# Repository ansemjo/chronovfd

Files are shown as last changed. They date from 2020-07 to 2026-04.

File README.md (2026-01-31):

# chronovfd

A vacuum-flourescent display (VFD) clock project based on Soviet NOS [IVL2-7/5 / ИВЛ2-7/5](https://www.ebay.com/sch/i.html?_nkw=ivl2-7%2F5) tubes. This has been my first somewhat complex hardware project when I got into electronics design in 2020 and grew to multiple iterations over the years.

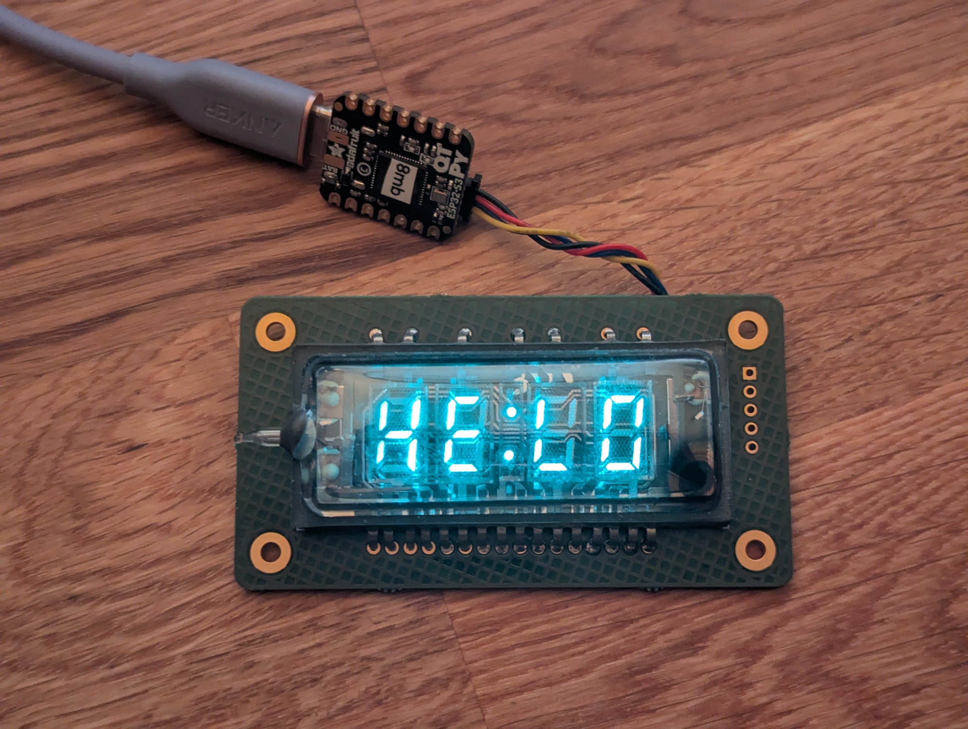
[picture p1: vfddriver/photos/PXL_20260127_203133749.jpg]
Redesigned vfddriver v2 showing blue glowing text HE:LO. The PCB has a hatched pattern on the front and gold ENIG plating.


#### quickmenu:

* [vfddriver](vfddriver/) — updated display board, which can be used over I2C
* [sandwich](sandwich/) — the original clock design with two boards
* [other](#other-directories) — links to initial research prototypes and various experiments

### vfddriver

This section describes the updated display board design, which I will be using going forward with this project. The [original design](#sandwich) of course still works but I found it needlessly complex later on due to a few choices I made.

Primarily, you needed to have a lot of IVL2-7/5 specific bits in the firmware and constantly refresh the display contents on the shift register. The mapping of display characters to segment anodes, their mapping to the correct shift-register pin, as well as the necessary anode and grid time-multiplexing all needed to be implemented on the controller board. Which meant that you really couldn't easily swap out the controller for something else. It had originally been a design goal not to require *any* separate firmware on the display board but I realized that just makes everything more complicated because you can't handle the display as an abstraction.

Instead, in this redesign I opted to include a small AVR ATtiny414 microcontroller, simplify the filament AC driver circuit with an H-bridge and implement the entire board as an I2C peripheral. **That newer design, along with firmware and documentation, can be found in [`vfddriver/`](vfddriver/).**

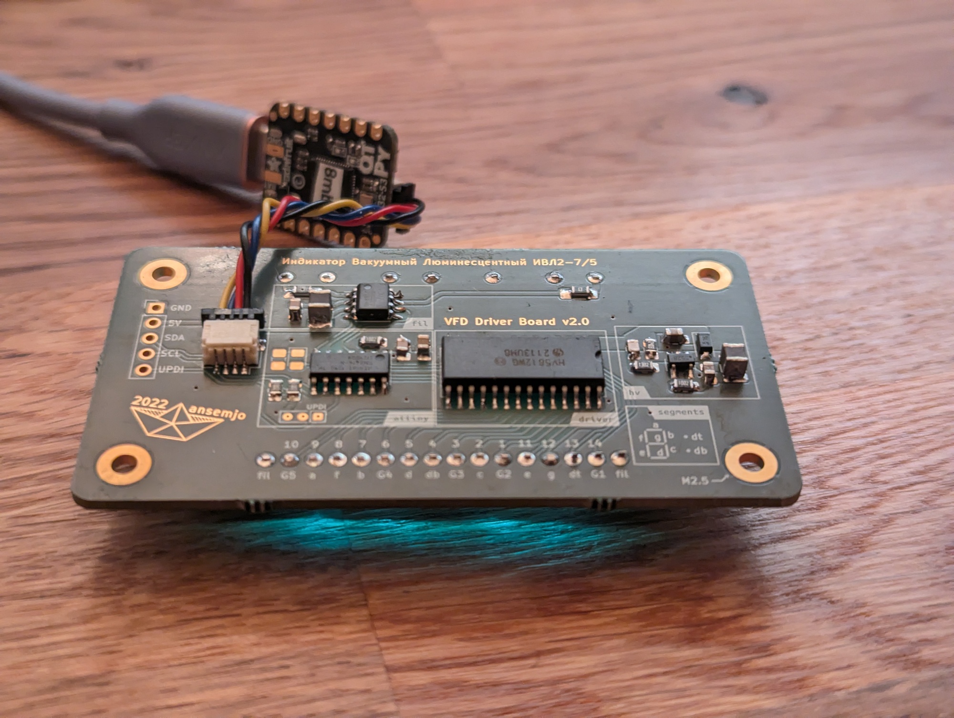
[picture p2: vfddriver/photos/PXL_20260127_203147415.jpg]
Backside of the vfddriver v2 board, with each group of chips labelled on the silkscreen.

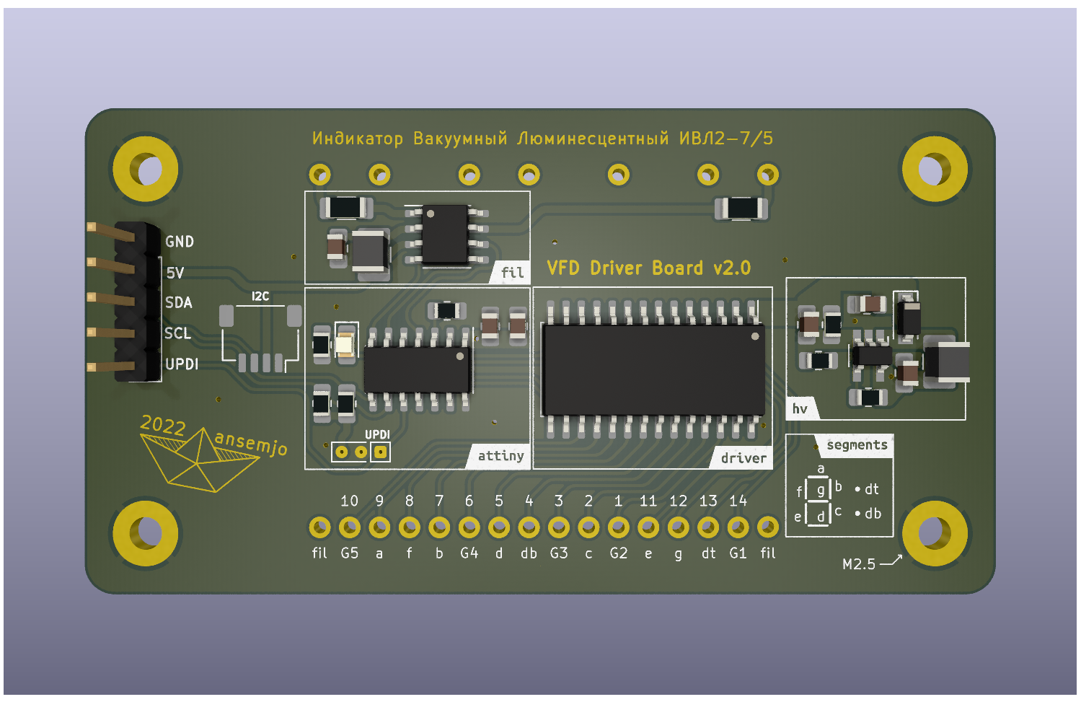
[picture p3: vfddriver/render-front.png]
PCB render of the same board.


In these images above you can also see why there is no dedicated "clockdriver v2" yet: now that the VFD is controlled over I2C, you can just use a small CircuitPython board with a Qwiic cable, like the [Adafruit QT Py ESP32-S3](https://www.adafruit.com/product/5426). :)

### sandwich

What you see in the pictures below is the original "sandwich design" with a pure-logic display driver (more or less a wrapper around the HV5812 shift-register) and an ESP32-based design with an RTC and coin-cell backup for the controller board. You can find all the KiCAD files and firmware for it in [`sandwich/`](sandwich/), together with the original README and more photos.

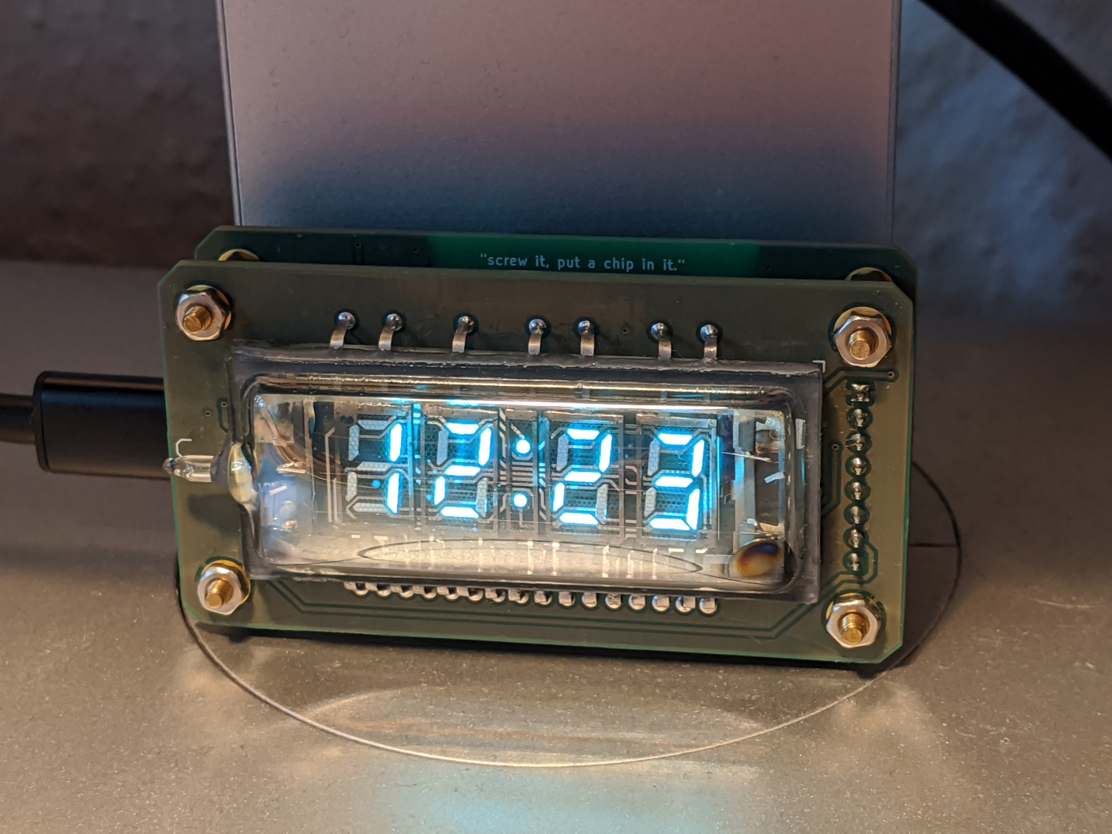
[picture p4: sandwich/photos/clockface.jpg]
finished sandwich clock, showing the time 12:23 in blue glowing digits

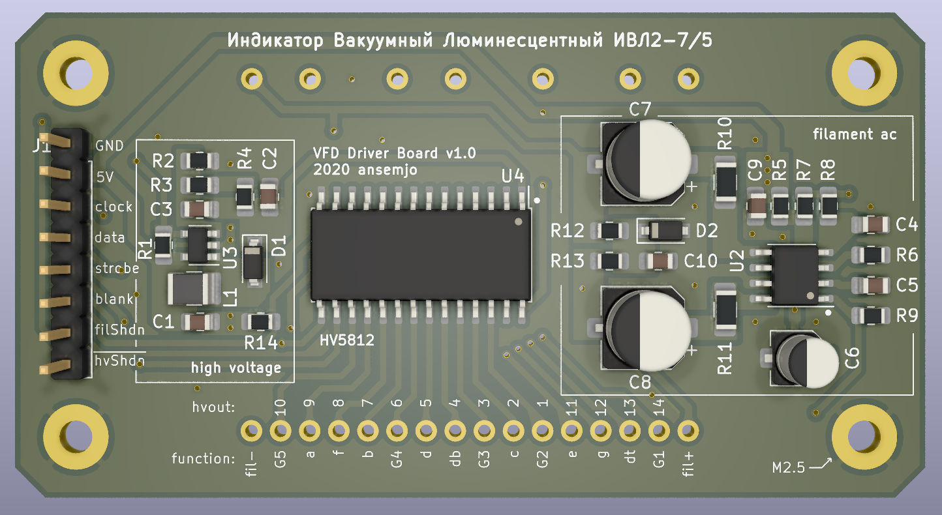
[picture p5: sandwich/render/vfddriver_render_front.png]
vfddriver PCB render, front

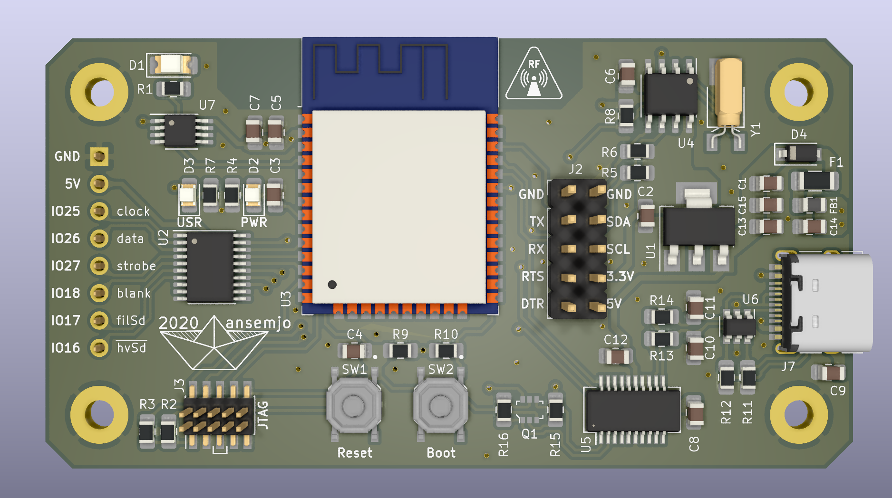
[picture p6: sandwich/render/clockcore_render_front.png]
clockcore PCB render, front


### other directories

The **[research/](research/) directory** contains a lot of initial ideas and fundamental information on VFD operation (needed voltages etc.) along with the [display datasheets](research/ivl2-7_5-datasheets).

The first **prototype clock** on perfboard can be found in [research/protoclock/](research/protoclock/).

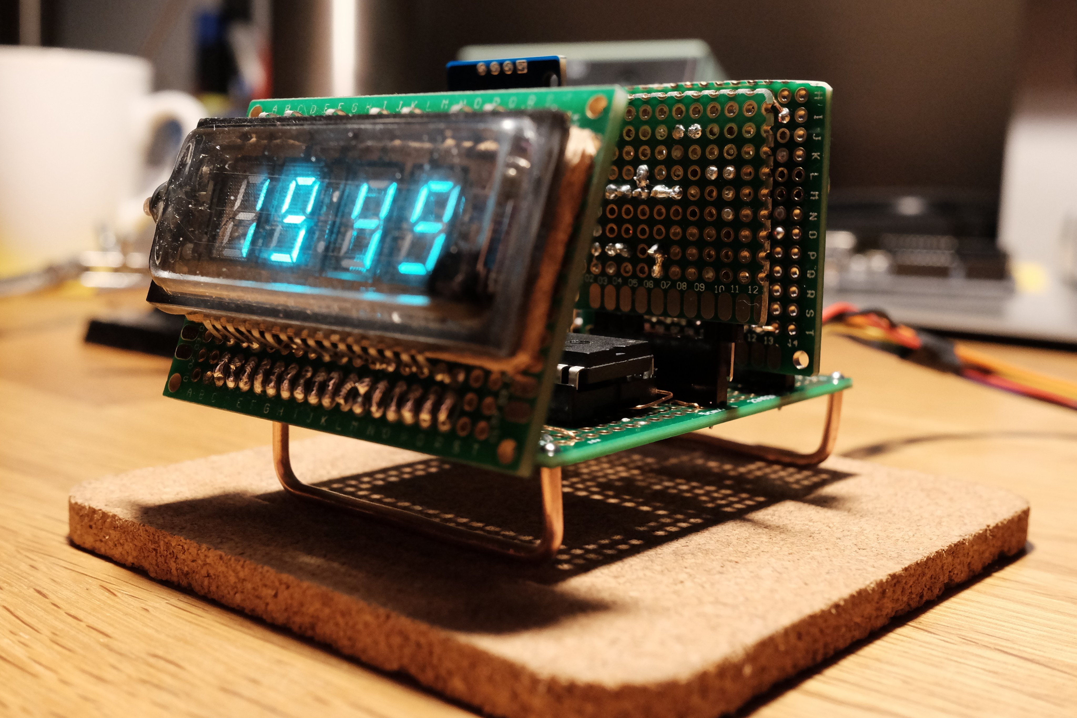
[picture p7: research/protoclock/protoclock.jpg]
Prototype clock built from multiple green perfboards.


An alternative **LCD-based front panel** with compatible dimensions, which can also be used standalone in [lcddriver](lcddriver/).

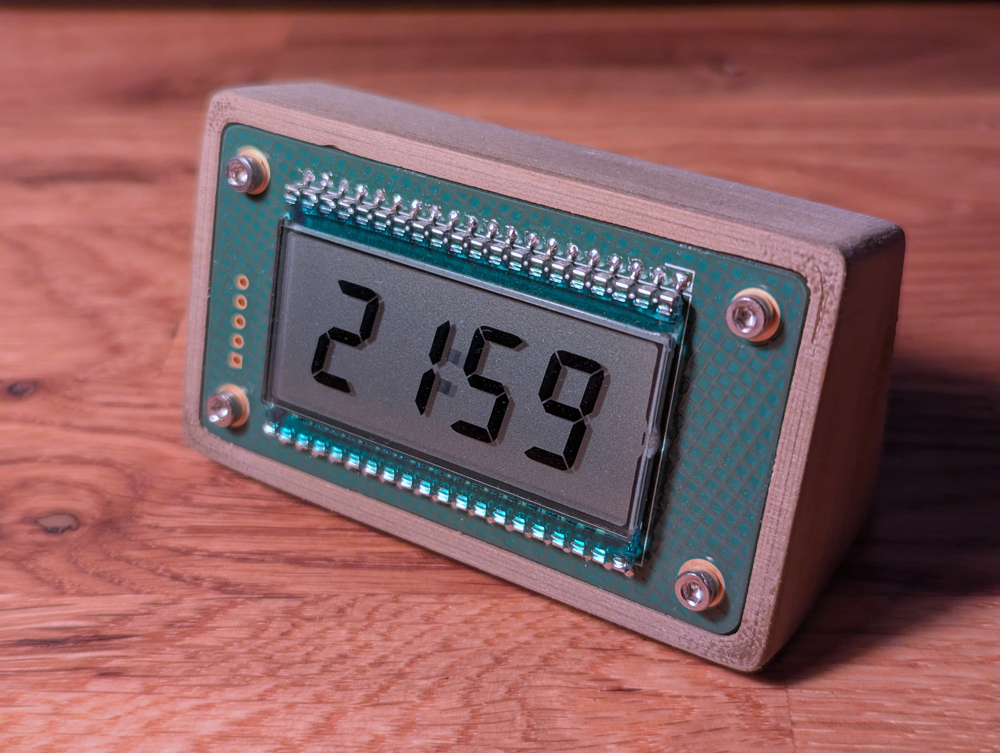
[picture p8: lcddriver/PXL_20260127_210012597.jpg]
The LCD clock panel in a small enclosure printed with brown wood-fibre filament.


In [experiments/si4706_radio_eval](experiments/si4706_radio_eval/) there is an evaluation board based on the **Skyworks Si4706 FM receiver** with RDS decoding. The idea is that you should be able to get time signal from radio stations without any need for internet synchronization.

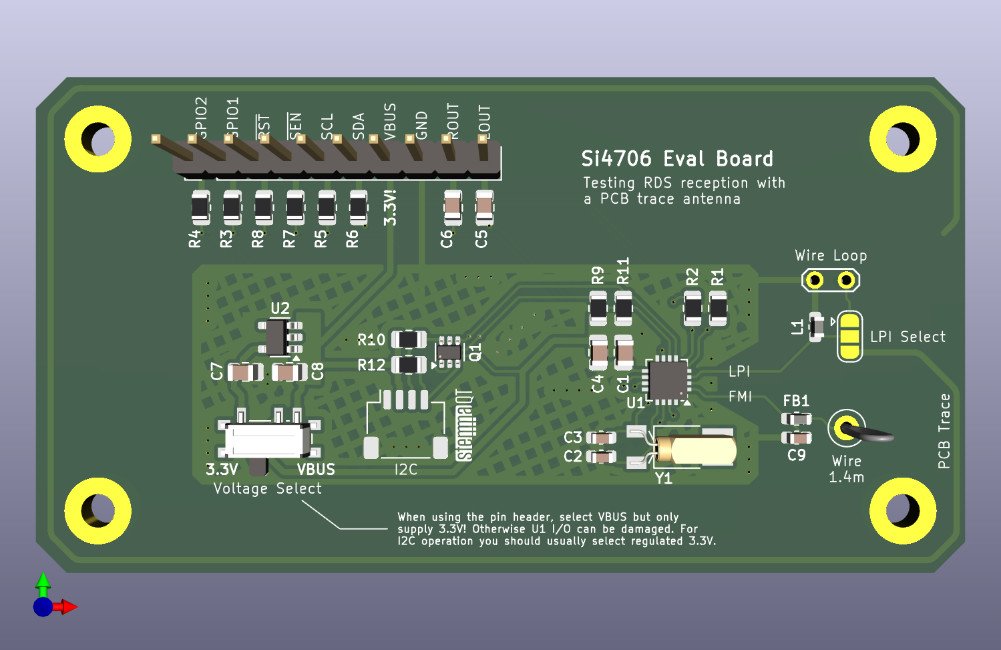
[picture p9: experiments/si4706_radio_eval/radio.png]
PCB render of the Si4706 evaluation board showing a trace around the edge, that could act as an antenna.


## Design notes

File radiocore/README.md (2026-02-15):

# radiocore
This is a redesign of the [`si4706_radio_eval`](../experiments/si4706_radio_eval/) experiment, meant to be a "clockcore v2" to control the standalone vfddriver.

Notably, it includes:

* **Skyworks Si4706** FM radio receiver with RDS decoder, to get time signal "from the air"
* **DS1338 RTC** with coin cell battery backup, to keep accurate time over long periods and without power
* **ESP32-C3** as a simple-to-program-over-USB controller chip, which conveniently *also* includes WiFi capability, if you prefer NTP over RDS
* vertical **GCT USB4145** USB-C connector, so a final assembly with two sandwiched boards will have the cable coming in from the back

_**2026-02-03:** I ordered the boards and am waiting to try if the CircuitPython firmware from the experiment will work on this chip as well. (**edit:** yes, it does!)_

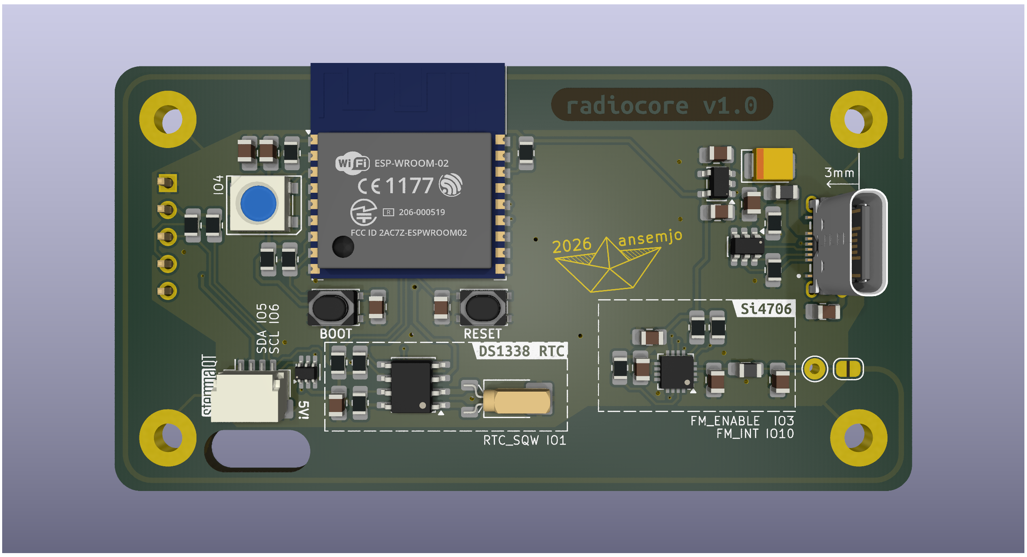
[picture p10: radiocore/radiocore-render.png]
A KiCAD rendering of the radiocore board. Top-left: an ESP32-C3 WROOM module. Bottom: DS1338 RTC with a crystal and the Skyworks Si4706 next to it. Right edge: vertical USB-C connector.

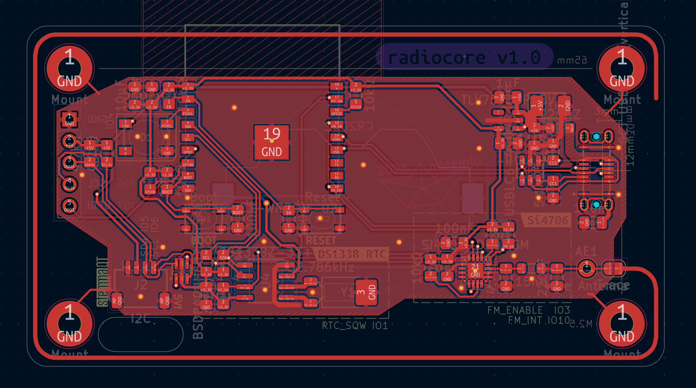
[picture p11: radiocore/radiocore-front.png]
KiCAD screenshot showing the traces on the front side. Visible is a recessed ground fill in the middle and a PCB trace antenna around the edge for radio reception.


### errata

While the overall function works (reception is even better than expected, to be honest), I also made a few major mistakes:

* The Neopixel is supplied with VBUS (~ 5V) but only gets logic level 3.3V on its data pin from the ESP32. When the VBUS supply voltage is slightly over 5V (like 5.2–5.3V), the Neopixel consistenly stays dark. When it is exactly at or slightly under 5V, you can *sometimes* get it to work. At 5V, the SK6812 requires a 3.6V logic level per the datasheet. Oops.

* The UPDI connection (pin 5 on the side header) is connected directly to the ESP32 without level shifting or current limit. Since this pin is at 5V logic level on the ATtiny, you could damage the ESP32-C3 if it is ever connected during programming of the `vfddriver`. Use a Qwiic cable only or just solder the first four pins to be safe.

* While it works out, the cutout under the Qwiic connector is a little close to properly insert the plug while the cable is already weaved through the hole.

* In the previous `vfddriver` firmware, the display's address was `0x68` and thus collided with the RTC. I've moved the VFD to address `0x42` and you can still reconfigure it using the `user_row`, of course.

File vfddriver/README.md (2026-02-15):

# vfddriver (v2)

A standalone driver board for four-digit IVL2-7/5 vacuum-flourescent display (VFD) tubes.

Redesigned vfddriver v2 showing blue glowing text HE:LO. The PCB has a hatched pattern on the front and gold ENIG plating.

view: [schematic](https://kicanvas.org/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) –
[circuit board](https://kicanvas.org/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) –
[firmware](firmware/) –
[parts list](https://www.digikey.de/de/mylists/list/2BJCAMLMTA) –
[ibom](https://htmlpreview.github.io/?https://github.com/ansemjo/chronovfd/blob/main/vfddriver/ibom.html)

## hardware

You can find a lot of fundamental information on VFD operating principles in [this excellent Noritake guide](https://www.noritake-elec.com/technology/general-technical-information/vfd-operation) ([archive](https://archive.is/BsdLR)). As a very brief overview, the filament is emitting electrons from a constant current, which are accelerated towards the positive grids over each segment and when the electrons hit a phosphor-coated segment, it starts glowing brightly.

* High-voltage (24V) for the grids and anodes is supplied using a simple [TI LM2733YMF](https://www.ti.com/lit/gpn/lm2733) boost converter.
* A [Microchip HV5812](https://ww1.microchip.com/downloads/aemDocuments/documents/OTH/ProductDocuments/DataSheets/20005629A.pdf) shift register with high-voltage MOSFET outputs is used to supply the grids and anodes with 24V, while being safe to use with 5V logic.
* The filament requires alternating current for best luminous uniformity. This is provided by a [Diodes Inc. ZXBM5210](https://www.diodes.com/datasheet/download/ZXBM5210.pdf) (or equivalently, [Rohm BD6211F](https://fscdn.rohm.com/en/products/databook/datasheet/ic/motor/dc/bd621x-e.pdf)) H-bridge motor driver by toggling the FWD/REV direction pins and using Vref to adjust the effective RMS voltage, which directly influences the overall brightness.
* Everything is controlled using an [AVR ATtiny414 microcontroller](https://www.microchip.com/en-us/product/attiny414), which acts as a peripheral on an I2C bus. Since the segments on all digits are connected, it needs to use time-multiplexing over the grids and constantly refresh the shift-register sufficiently quickly for a smooth appearance. The AVR also translates received ASCII characters to the actual segment anodes.



So far, I have ordered the PCBs from [AISLER.net](https://aisler.net/), who produce locally (to me) using the pretty gold ENIG finish and accept KiCAD files directly. Parts were [ordered from DigiKey](https://www.digikey.de/de/mylists/list/2BJCAMLMTA) and assembly was done by hand using the [interactive BOM viewer](https://htmlpreview.github.io/?https://github.com/ansemjo/chronovfd/blob/main/vfddriver/ibom.html).

### segments

In the render above, you can see the HV5812 pin numbering and mapping to grids (`G1`, `G2`, `Gc`, `G3`, `G4`) and segments (`a`–`g`, `db`, `dt`), with pin 1 being the "latest" shifted bit:

|anode|G4|a|f|b|G3|d|db|Gc|c|G2|e|g|dt|G1|
|-|-|-|-|-|-|-|-|-|-|-|-|-|-|-|
|**pin**|10|9|8|7|6|5|4|3|2|1|11|12|13|14|

For convenience, here is the same table in terms of bits in a `u16`:

|anode|G1|dt|g|e|G4|a|f|b|G3|d|db|Gc|c|G2
|-|-|-|-|-|-|-|-|-|-|-|-|-|-|-|
|**bit**|13|12|11|10|9|8|7|6|5|4|3|2|1|0|

The segments in a digit are counted clockwise, starting from the top; the center dash is last and the two dots in the colon can be adressed individually as well:

```
      a            a                a            a     
    ────         ────             ────         ────    
 f │    │     f │    │     dt  f │    │     f │    │   
   │  g │ b     │  g │ b   ■     │  g │ b     │  g │ b 
    ────         ────             ────         ────    
 e │    │     e │    │     db  e │    │     e │    │   
   │  d │ c     │  d │ c   ■     │  d │ c     │  d │ c 
    ────         ────             ────         ────    
                                                        
     G1           G2       Gc       G3           G4     
```

## firmware

The firmware was ported to Rust using the [`avr-none`](https://doc.rust-lang.org/stable/rustc/platform-support/avr-none.html) target and [`rahix/avr-device`](https://github.com/Rahix/avr-device) crate. Even though this is effectively still register-fiddling, since there currently is no proper HAL for ATtiny 0/1-series chips, the development experience was much more pleasant already.
*(Note: the previous C firmware can be found in [commit `2b87ed3`](https://github.com/ansemjo/chronovfd/tree/2b87ed39b4a0b78c596b9a6d270321534c5b3cb9/vfddriver/firmware), though it has fallen behind feature-wise.)*

### building

I am not exactly sure what the absolute minimum required version is for a successful build. But I can say that the firmware easily builds in a current `rust:trixie` container.

You should be able to just run `cargo build` after installing `gcc-avr` and `avr-libc`. The resulting `firmware.elf` then just needs to be converted to a HEX file using `avr-objcopy` before flashing.

```
$ docker run --rm -it -v firmware/:/firmware -w /firmware rust:latest

# apt update && apt install -y gcc-avr avr-libc
// binutils-avr amd64 2.43.50.20250108-1
// gcc-avr amd64 1:14.2.0-2
// avr-libc all 1:2.2.1-1

# cargo build
info: syncing channel updates for 'nightly-x86_64-unknown-linux-gnu'
info: latest update on 2026-01-31, rust version 1.95.0-nightly (a293cc4af 2026-01-30)
// ...
    Finished `dev` profile [optimized + debuginfo] target(s) in 26.26s

# avr-objcopy -O ihex -R .eeprom target/avr-none/debug/firmware.{elf,hex}
# avr-size target/avr-none/debug/firmware.hex
   text	   data	    bss	    dec	    hex	filename
      0	   3658	      0	   3658	    e4a	firmware.hex
```

A compiled firmware is also committed in this repository, though I won't guarantee that I will always keep it updated with every commit. (:

### flashing

The ATtiny 0/1/2-series chips can be flashed using an UPDI programmer, which can be as simple as connecting a Schottky diode or resistor between the RX and TX pins of a USB-TTL adapter: [SpenceKonde/AVR-Guidance/UPDI/jtag2updi.md](https://github.com/SpenceKonde/AVR-Guidance/blob/master/UPDI/jtag2updi.md#connections). I have my own programmer based on a CH340N chip, very similar to [this pogo pin adapter](https://oshwlab.com/gabe_9484/usb-c-to-updi).

Using serial adapters like this, you can then use [`pymcuprog`](https://pypi.org/project/pymcuprog/) to flash the firmware:

```
pymcuprog -d attiny414 -t uart -u /dev/ttyUSB0 write \
 --erase -f firmware/target/avr-none/debug/firmware.hex
```

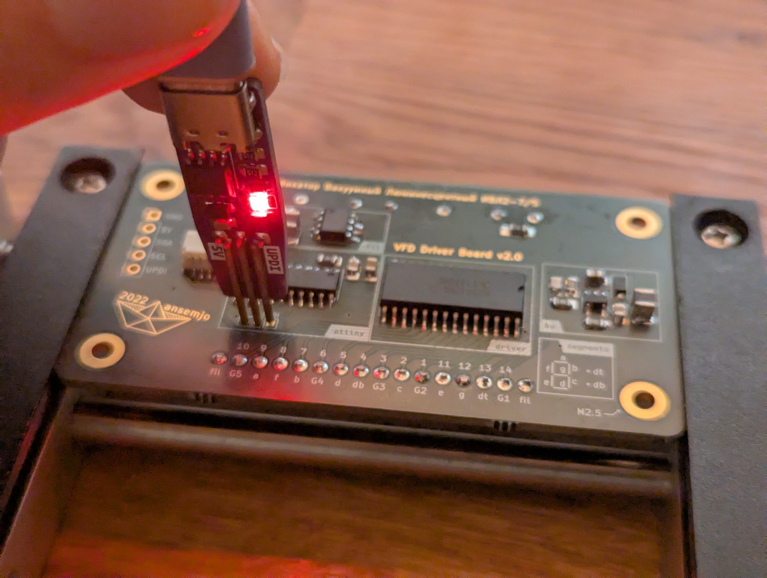
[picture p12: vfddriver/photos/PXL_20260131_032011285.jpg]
Flashing the firmware to the display board using a serial UPDI programmer. A red LED is lit signalling a write in progress.


### configuration

For persistent configuration, you can write values to the ATtiny414's USERROW — a special region in the EEPROM (`0x1300`), which is not deleted when flashing new firmware. You can again use `pymcuprog` to set these values. Erasing the region or writing a `0xff` always means "use hardcoded defaults", since this is the default when you haven't modified the USERROW.

```
pymcuprog -d attiny414 -t uart -u /dev/ttyUSB0 write \
 -m user_row -o 0x01 -l 160 # default brightness
```

| Offset | Type | Default | Description |
| --- | ---- | ---| --- |
| `0x00` | `u8` | `0x42` | I2C peripheral address |
| `0x01` | `u8` | 120 | filament brightness (DAC value) |
| `0x02` | `u16` | 10.000 | digit multiplexing frequency in Hz |
| `0x0b` | `[u8; 5]` | `0xff..ff` | initial display contents |
| `0x10` | `[u8; 16]` | `[0, 1, 2, 3, 4]` | grid multiplex loop |

The grid multiplex loop can be used to adjust the relative brightness of grids, if they do not light up evenly. For example, if your first and last digits are darker at the edges, write:

```
pymcuprog -d attiny414 -t uart -u /dev/ttyUSB0 write \
 -m user_row -o 0x10 -l 0 0 1 2 3 4 4 0xff
```

## usage

The default I2C address of the display is `0x42`. Since the primary usage will be writing new display contents, the firmware will try to parse *most* bytes as bare numbers, ASCII characters or raw segment bitmaps. There are only two special command sequences which change the behaviour with the first transmitted byte; otherwise the display always expects exactly five bytes for the new display contents, from left to right, with the colon in the middle.

```
# HE LO
i2c.writeto(0x42, "HE LO")
```

#### commands

The two commands currently are:

* `[ 0x10, <u8> ]`: adjust display brightness with a new filament DAC value
* `[ 0x7f ]` (ASCII `DEL`): clear display (all segments off)

Future additions will probably use the non-printable range after `0x10`.

#### bare numbers

The byte values `0x00` to `0x09` are simply interpreted as decimal numbers.

So `[ 0x01, 0x02, 0x00, 0x03, 0x04 ]` would display `12 34`.

#### segment bitmap

The non-printable range above `0x80` is treated as raw bitmaps to the segments. To make it easier to think about, the bits are mapped from "left to right" (MSB to LSB) in the same clockwise order as they are named `a` to `g`: `0b1abcdefg` (bits `b` and `c` additionally map to `dt` and `db`).

Showing the "identical to" symbol `≡` with three horizontal bars could therefore be done by transmitting:

```
  1abcdefg
0b11001001
```

#### characters

All the remaining bytes are mapped from the ASCII characters, where possible. Since the digits are only sevent-segments digits, you can't really display the full alphabet well; for the colon only `:`, `.` and ` ` are really useful, etc. But this also allows you to simply format a `HH:MM` string with the time on your controller and transmit that as bytes.

#### examples

A few more examples that you might use from CircuitPython:

```
# 23:59
i2c.writeto(0x42, "23:59")
i2c.writeto(0x42, bytes([2, 3, 0xff, 5, 9]))
# 20°C
i2c.writeto(0x42, "20 *C")
```

```
# An.on                    A     n        .        o     n
i2c.writeto(0x42, bytes([0x41, 0x6e, 0b10010000, 0x6f, 0x6e]))
```

```
# lower brigthness
i2c.writeto(0x42, bytes([0x10, 65]))
```

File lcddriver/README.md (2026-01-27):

# lcddriver

This isn't entirely my own design and is instead heavily based on David Johnson-Davies' ["Low-Power LCD Clock" design on Technoblogy](http://www.technoblogy.com/show?19K8) (archived: [page](https://archive.ph/uYsL3), [firmware](https://archive.ph/4itl0)). This was created shortly after the `vfddriver` v2 and was meant to use the same physical format and I2C protocol to be a drop-in replacement. In practice, I haven't really bothered to write a separate firmware and used it as a standalone clock with David's firmware instead.

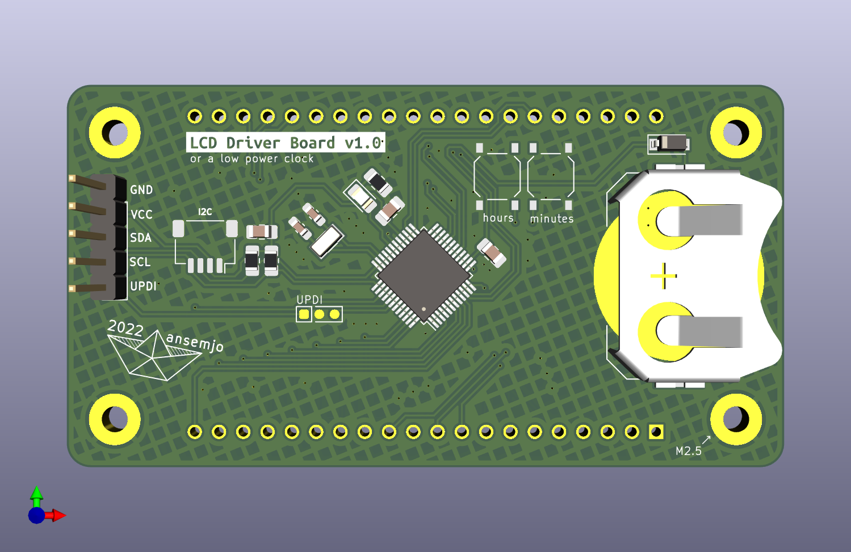
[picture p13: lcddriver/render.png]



It just needed a few small modifications from the original:

* Only `PE0` is connected to the display's `COM`. `PE1` is used for an LED and if you use the firmware as-is, you'll have a constantly flashing LED.

* I used an **AVR32DB48** and apparently (?) it lacks some of the ADC stuff necessary to read its own voltage? So I just removed `ADCSetup()`, `DisplayVoltage()` and the references to it.

* Additionally, I removed the temperature display and reduced the blinking frequency of the colon by to 2 Hz.

There is also an inverted variant of the firmware, for when you want to operate the clock rotated by 180°, since the LCD segments are rotationally symmetric but the viewing angle is better from one side.

### Compile

The firmware is in `technoblogy-clock-firmware/`.

The chip [is supported](https://docs.platformio.org/en/latest/boards/atmelmegaavr/AVR32DB48.html) by PlatformIO but back when I tried this, I couldn't get it to work. I got either `Error: Unknown board ID 'AVR32DB48'` or `Error: This board doesn't support Arduino framework!`. Therefore I used the method that David used and installed the [DxCore](https://github.com/SpenceKonde/DxCore) in the Arduino IDE, which I then used to compile the firmware instead.

### Flashing

For some reason the Arduino GUI couldn't directly flash my chip. Probably something about a wrong Python version. I manually installed [`pymcuprog`](https://pypi.org/project/pymcuprog/) in a Python 3.9.12 environment and used:

```
pymcuprog write -d avr32db48 -t uart -u /dev/ttyUSB1 -f lcdclock.ino.hex
```

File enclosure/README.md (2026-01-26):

# enclosures

This is a small collection of 3D-printable cases designed in [Solvespace](https://solvespace.com/) to go with the chronovfd display.

* **vfdshell**: fits a vfddriver_v2 display from behind
  * screw with M2.5 directly into the plastic or use the `_deeper` variant which uses heat inserts
  * supposed to be standalone and driven with an [Adafruit QT Py](https://learn.adafruit.com/adafruit-qt-py-esp32-s3/overview) over the Stemma QT cable
  * it hides most of the PCB from the front and encloses the vacuum tube

* **frontmount**: screw in the display PCBs from the front
  * again, held in place with M2.5 screws and nuts that need to be pushed into pockets
  * rather designed for use with the lcddriver, which is powered by a coin cell and needs no additional microcontrollers or cables on the back

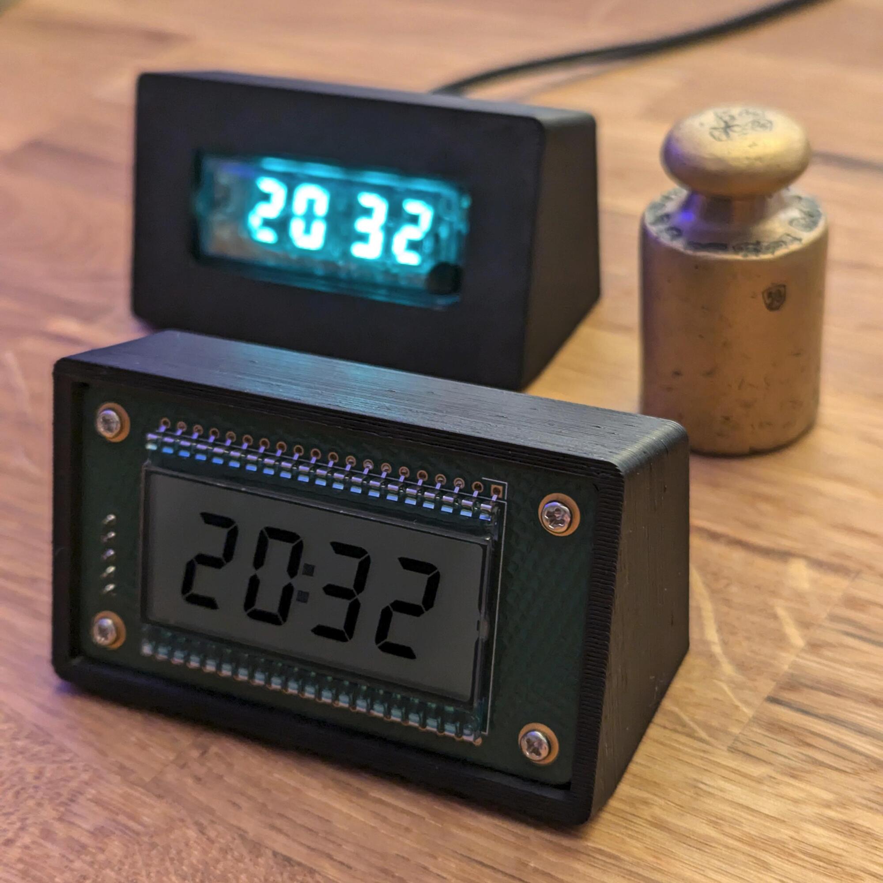
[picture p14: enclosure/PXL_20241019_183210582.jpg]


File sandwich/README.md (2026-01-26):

# chronovfd

~~ *a vacuum-flourescent display clock project* ~~

The first prototype of this clock was built completely on protoboard and can be
seen on [my Twitter](https://twitter.com/ansemjo/status/1235315817937596424).

This has become my first somewhat complex hardware project and as of now I have
assembled multiple printed circuit boards for the "display driver" and the
"clock core". After fiddling with Espressif's development framework for a while
the assembled hardware now actually works as a clock with internet time
synchronization. :)



You'll find:

* some initial research and ressources on the topic in `research/`
* [hardware](#hardware) files in `hardware/`
* the [firmware](#firmware) in a PlatformIO project in `firmware/`

# Hardware

As mentioned above the final assembly consists of two sandwiched boards:

* [VFD Driver](#vfd-driver-board)
* [Clock Core](#clock-core)

The boards were designed with KiCad version 5.1.6.

The bill-of-materials files contain Digi-Key part numbers, so you can easily
import all parts into your cart. Only the IVL2-7/5 display itself needs to be
sourced elsewhere but there are plenty on [eBay](https://www.ebay.com/sch/i.html?_nkw=ivl2-7%2F5).

Both boards can be screwed together e.g. with 11 mm M2.5 standoffs between
them. I have found some that are marketed as a "Raspberry Pi assembly kit" that
fit well.

### Errata

Sometimes things go wrong .. these are known errors and how to fix them:

* [Rev1.0: Fix the ambient light sensor photodiode](hardware/errata/rev1.0-photodiode/erratum-photodiode.md)

## VFD Driver Board

The VFD driver board is basically a power supply and a simple shift register
with a high-voltage capable output side. I used Rolo's *Universal VFD PSU*
design from [this EEVblog forum post](https://www.eevblog.com/forum/projects/showing-my-vfd-psu/).
The original [schematics](research/universal-vfd-psu/schematic_r2.1.pdf) and
a few pictures are mirrored in `research/universal-vfd-psu/`.

It can be used standalone but there is no logic on the board, so you'll have
to implement time multiplexing for the digits yourself. See the
[Microchip HV5812 datasheet](http://ww1.microchip.com/downloads/en/DeviceDoc/20005629A.pdf)
for more information. The gist is:

* supply regulated 5V power on `GND` / `5V`
* data is transmitted over `clock` and `data` with SPI mode 0 transactions at 5 MHz
* the output pin numbers are listed with their segment or grid function on the silkscreen
* toggle the `strobe` pin `HIGH` to latch the data to the high voltage outputs
* pulling the `filShdn` pin `HIGH` disables the filament supply
* pulling the `hvShdn` pin `LOW` disabled the high-voltage supply
* when the shutdown pins are left floating / in high-Z state, they are pulled active internally, so the display is "on"
* PWM dimming the brigthness with the filament shutdown pin is possible

### Design files

| type | file |
| ---- | ---- |
| kicad project | `hardware/vfddriver.pro` |
| schematic | [`hardware/vfddriver.pdf`](https://github.com/ansemjo/chronovfd/raw/master/hardware/vfddriver.pdf) |
| bill of materials | [`hardware/vfddriver_bom.csv`](hardware/vfddriver_bom.csv) |
| interactive bom | [`hardware/vfddriver_ibom.html`](https://raw.githack.com/ansemjo/chronovfd/master/hardware/vfddriver_ibom.html) |

### Images

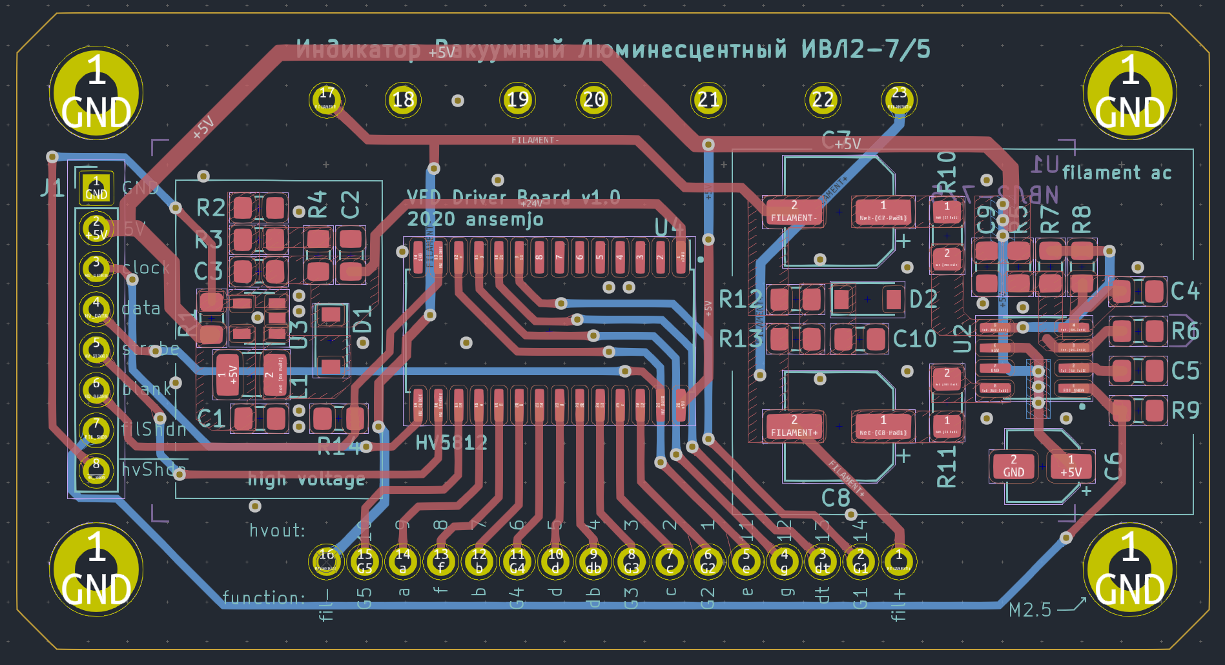
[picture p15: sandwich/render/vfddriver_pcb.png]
vfddriver PCB layout

vfddriver PCB render, front
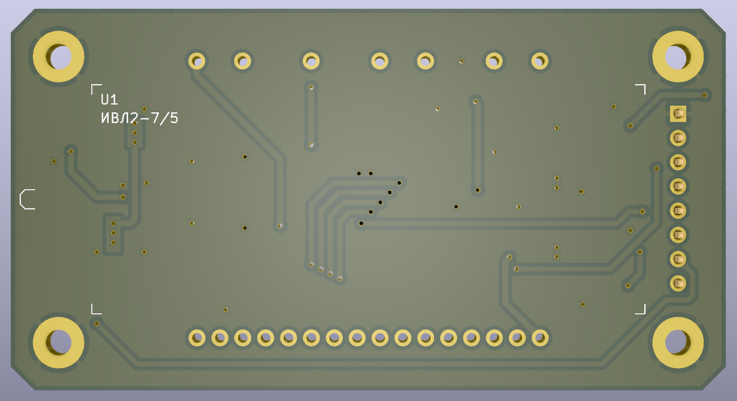
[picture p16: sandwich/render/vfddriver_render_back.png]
vfddriver PCB render, back


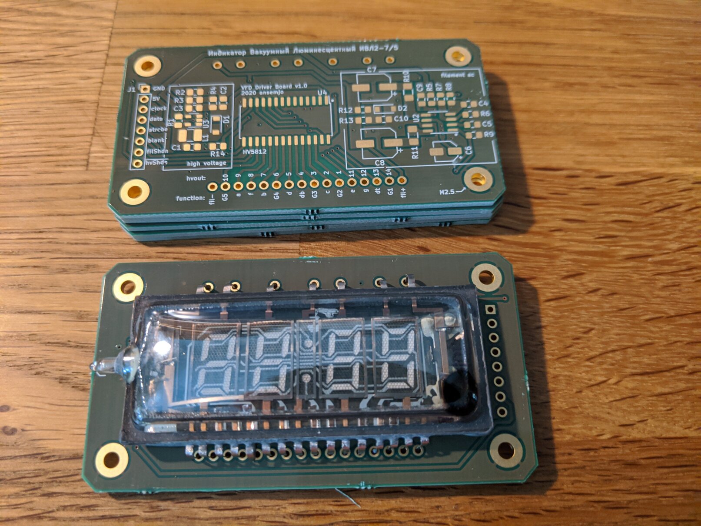
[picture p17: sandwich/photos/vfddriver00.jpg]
First batch of PCBs from Aisler.net

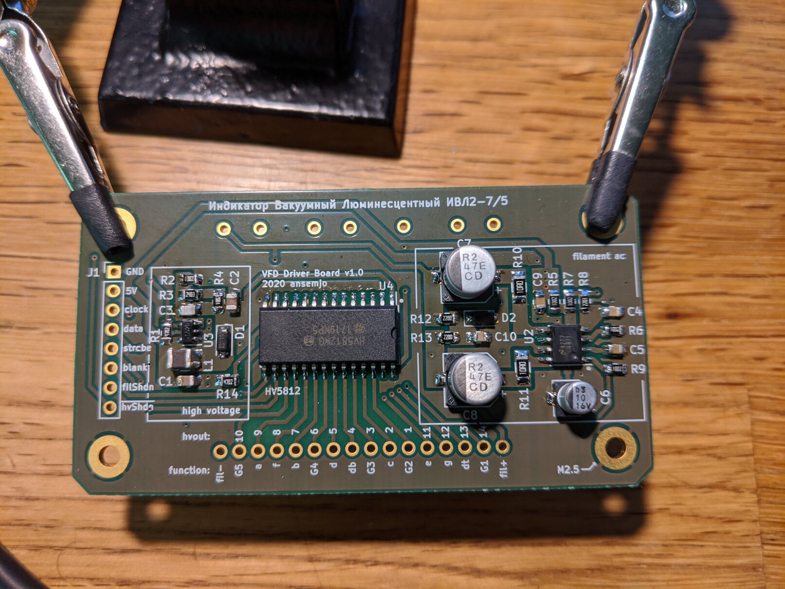
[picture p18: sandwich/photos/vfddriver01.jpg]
An assembled VFD driver board

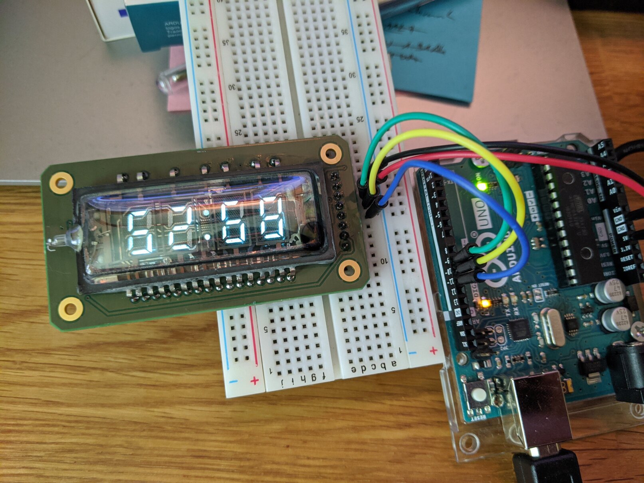
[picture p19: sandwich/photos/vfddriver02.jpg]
Testing a board on a breadboard with an Arduino


## Clock Core

The Clock Core board is the control logic for this clock project. If you look
at the bill of materials it is a relatively expensive board for what it's
supposed to do but I wanted to experiment with some of these components. On
this board there are:

* an Espressif `ESP32-WROOM-32` module, which has WiFi and Bluetooth connectivity
* a USB 2.0 Type-C receptacle for power and data with relatively good input protections and a 3.3V linear regulator
* an FTDI `FT231XS` with an auto-reset circuit providing a serial programming and communication interface to the ESP32
* a Maxim `DS1338Z-33+` RTC with a crystal, which is connected to the ESP32 over I²C and has a coin cell battery backup
* a Maxim `DS18B20U` temperature sensor with a OneWire interface
* a footprint for a photodiode to sense ambient light levels
* a Texas Instruments `SN74HCT245PWR` level shifter to provide the correct logic levels to the VFD driver board
* a PWR and a USR LED for that blinkenlights, the PWR LED can be disabled by cutting a solder jumper
* a 10-pin 1.27mm JTAG header for the ESP32

### Design files

| type | file |
| ---- | ---- |
| kicad project | `hardware/clockcore.pro` |
| schematic | [`hardware/clockcore.pdf`](https://github.com/ansemjo/chronovfd/raw/master/hardware/clockcore.pdf) |
| bill of materials | [`hardware/clockcore_bom.csv`](hardware/clockcore_bom.csv) |
| interactive bom | [`hardware/clockcore_ibom.html`](https://raw.githack.com/ansemjo/chronovfd/master/hardware/clockcore_ibom.html) |

### Images

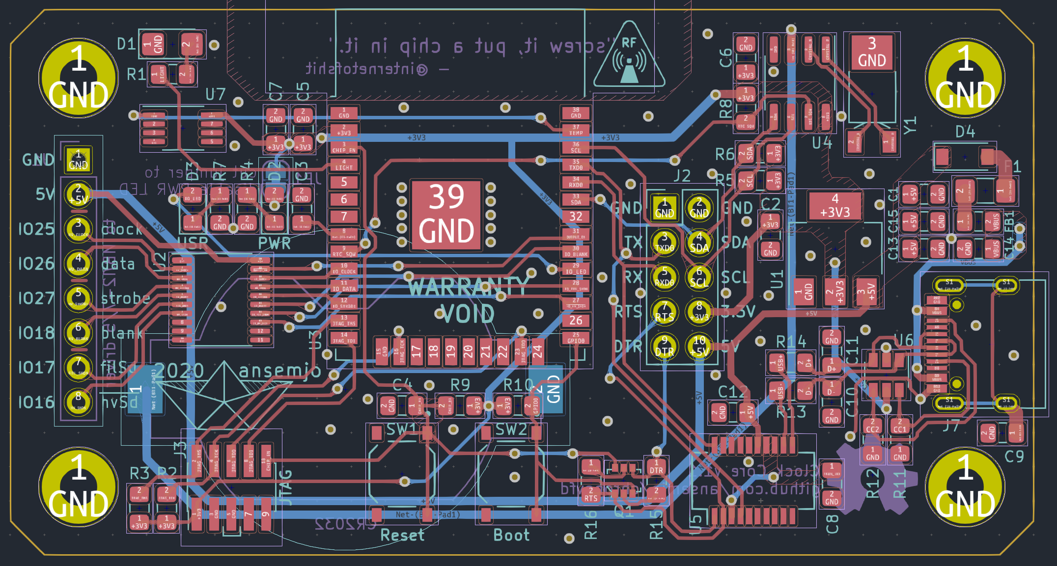
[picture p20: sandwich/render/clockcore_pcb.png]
clockcore PCB layout

clockcore PCB render, front
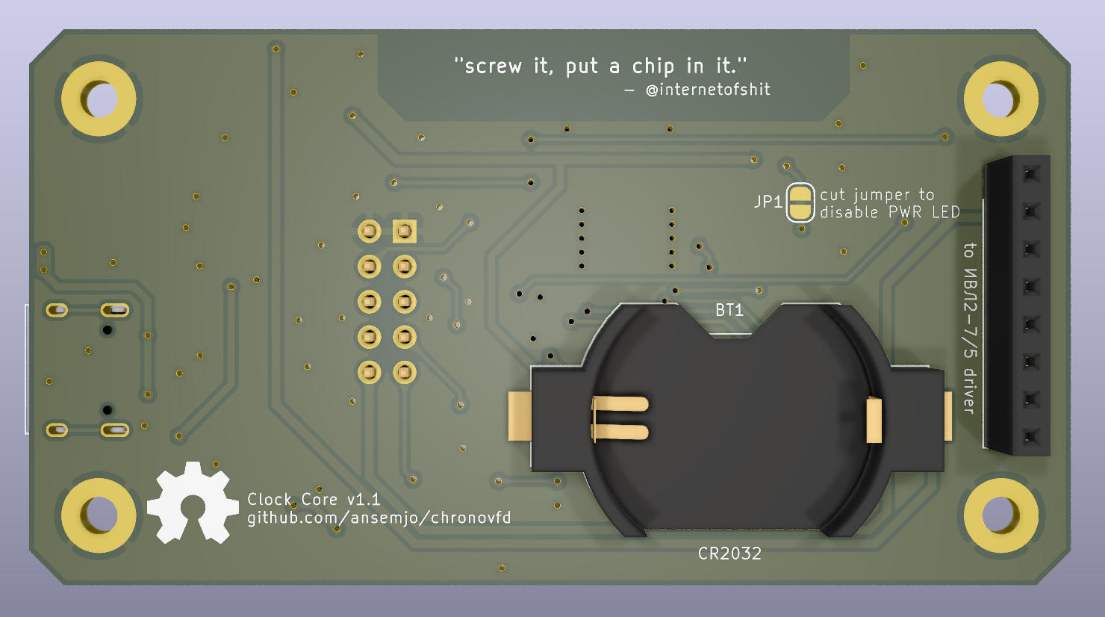
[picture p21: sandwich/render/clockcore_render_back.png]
clockcore PCB render, back


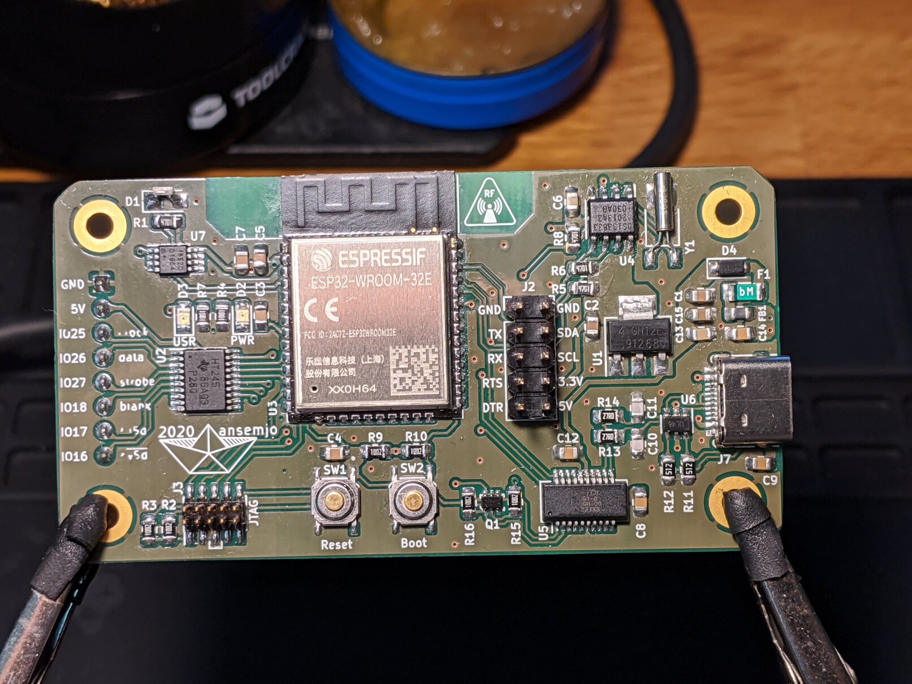
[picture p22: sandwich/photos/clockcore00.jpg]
A soldered clockcore circuit boards in small helping hands grips.

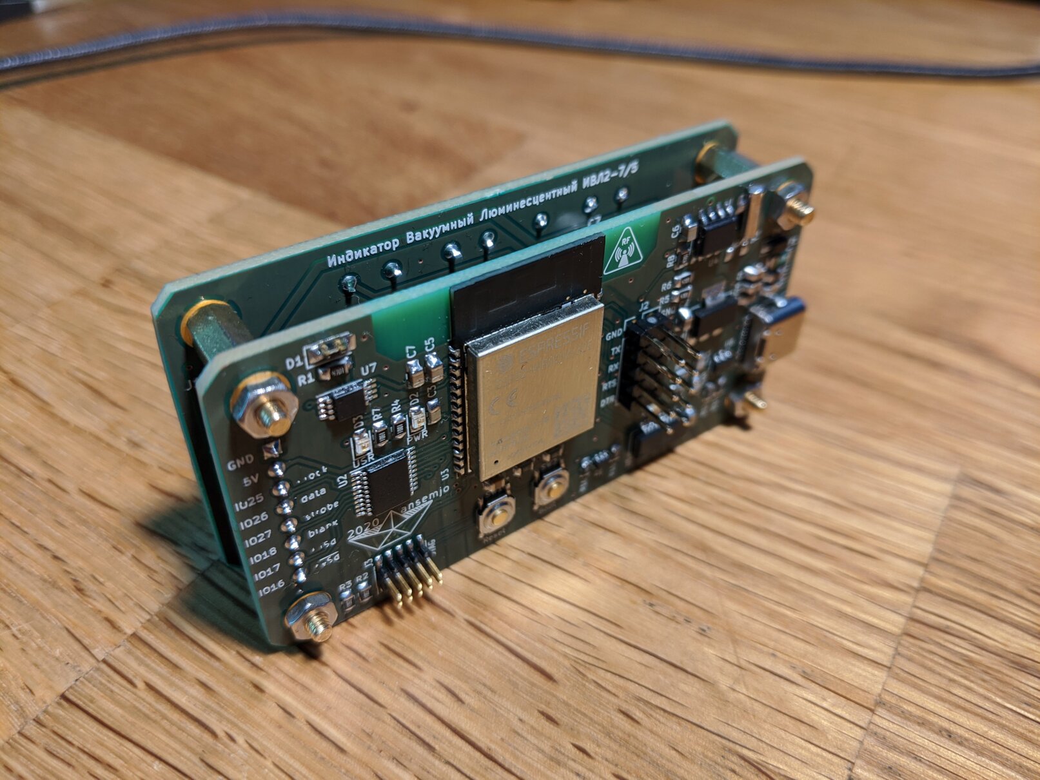
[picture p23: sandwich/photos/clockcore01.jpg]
An assembled chronovfd, where both boards are screwed together with standoffs.

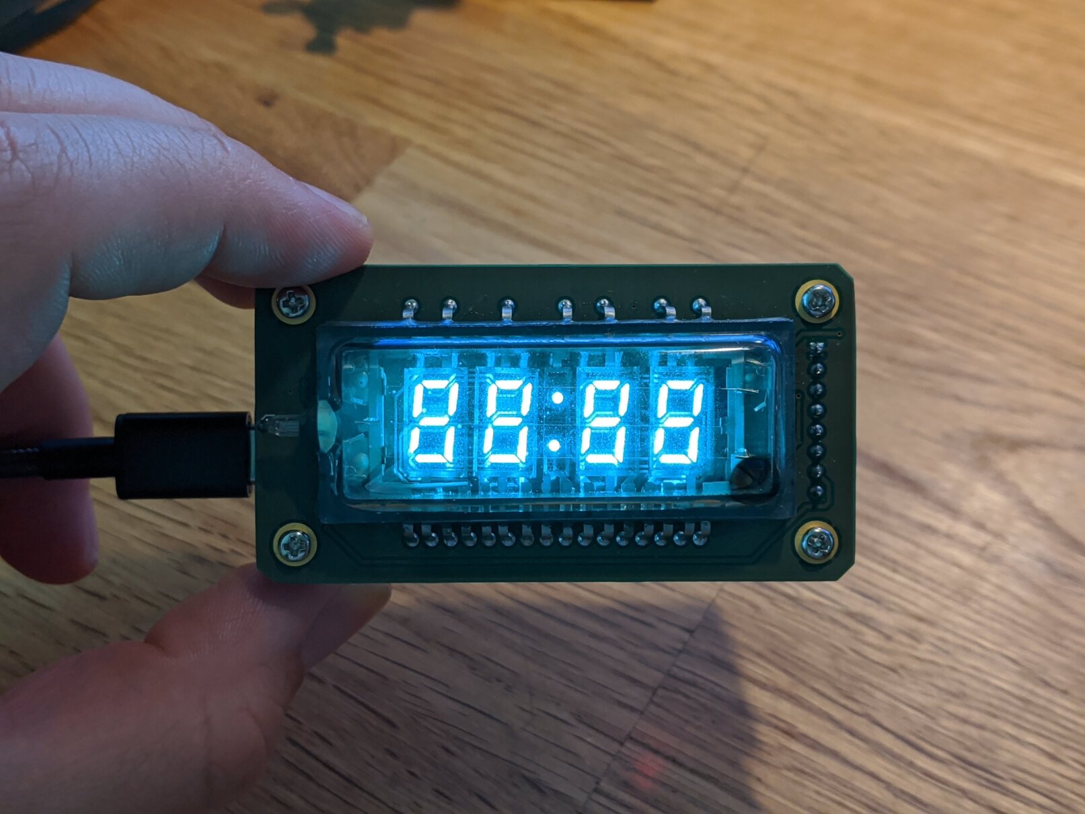
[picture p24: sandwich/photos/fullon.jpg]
Testing the display by lighting up all segments to their full brightness.


# Firmware

The firmware is kept in a PlatformIO project. So – if you have `platformio`
already installed – all you need to do is connect the Clock Core via USB and run:

    pio run -t upload

Generally, this board is compatible with most ESP32 devkit configurations. I'm
using a custom board definition mainly to get faster upload speeds, which the
onboard FTDI FT231X can handle. For new projects you may use `pio init -b esp32dev`.

After flashing the firmware, the board starts in **provisioning mode** and you'll
see the word `Prov` blink on the display. Use the
[ESP BLE Provisioning](https://play.google.com/store/apps/details?id=com.espressif.provble)
app to connect and provision your WiFi credentials.

**Note:** I haven't configured a *proof-of-posession* in the firmware, so you
must disable *Encrypted Device Communication* in the app settings first. If you
want to encrypt the provisioning step, look into `wireless_provision()` in
`src/wireless.c`.

Afterwards, the chip will connect to the internet and attempt to synchronize the
time. This will be written to the RTC, which will keep the time as long as an
RTC backup battery is present. If upon poweron the last synchronization is more
than two hours ago, the clock will be synchronized once immediately. Otherwise
it runs on a schedule every night at 05:00. See `src/realtimeclock.c` if you
want to change that. You should probably also fix the timezone if you're not
in the "Europe/Berlin" zone. That is set in `app_main()` with a call to `setenv()`.

# LICENSE

Unless otherwise noted in the file (`ds1307.*`, `i2cdev.*`) the firmware is licensed
under an MIT license, which can be found in [LICENSE](LICENSE).

The hardware project is licensed under a CERN Open Hardware Licence Version 2 -
Permissive, which can be found in [hardware/LICENSE](hardware/LICENSE).

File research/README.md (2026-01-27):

# VFD Clock

I bought some old Russian / Ukranian stock of **IVL2-7/5** tubes. These are **V**acuum **F**lourescent **D**isplays used in old alarm clocks.

The basic principle has a cathode filament wire and several phosphorous-coated anode segents with section grids above them. A low voltage has to be supplied to the cathode to emit electrons which are attracted to a higher voltage on the anode grids and segments. When an electron hits the coating of a segment, it lights up in a blue-ish colour.

## Thoughts

Some thoughts on a select number of topics, when building such a clock:

### Realtime Clock

There's basically two approaches .. use a microcontrller with a sufficiently precise crystal and set the time on every boot, e.g. via NTP on an Espressif chip .. or use an onboard RTC module, which holds the time with a little button cell.

I think I favor the no-internet-of-shit approach, which uses only an offline microcontroller and can keep its time while it is disconnected from power. Either implement a simple three-button interface to set the clock or write a serial protocol to interface with the chip in-system.

### Microcontroller

As descibed above, I funfamentally need to make the choice between a connected device like an ESP8266 or a chip from the ATMega/ATTiny family.

And I tend towards the latter, specifically either an ATMega328P or an ATTiny84. They use 5 V logic levels, so I don't need any level shifting with my desired power source. And the project is just a damn clock after all! If I decide to do another design with a larger dot-matrix VFD, then a connected device might come in handy. For now though ..

I'd also like to experiment with barebones microchips. The Espressif boards are too much of a *complete module* for my tastes here.

### Power Source

There's a few designs which only use a 1.5 V battery and the kinda work .. albeit not for long. That's cool. But I would rather use a bigger battery, it doesn't need to be a wristwatch after all.

In any case, I think I would like to assume a regulated 5 V rail from which I derive all other voltages that I need. This allows me to solder a micro-USB port somewhere and run it off a powerbank. Also, most LiPo daughterboards appear to be interfacing at 5 V, so I could just put some sort of JST connector somewhere and not bother with charging logic at all.

### High-voltage Driver

Simply use a regulated boost converter, duh'. This part seems to be really simple. Though, depending on your specific filament circuit you might need to boost a little higher than nominally needed to account for the center-tap offset.

### Filament Driver

The filament usually expects AC voltage to mitigate the effects of luminance gradients caused by the DC voltage drop in the filament. When one side has a lower potential than the other this might cause a visible gradient. On the one hand the voltage for this tube is relatively low to begin with and the tube is rather short. On the other hand a proper AC circuit is relatively complex. Just looking at the VFD PSU design by Rolo, the coupling capacitors would be the next biggest component after the anode multiplexer chip - weird.

Either way, this driver circuit needs to be regulated at the correct voltage. If I just pump 3.3 V into it continiously, it will eventually burn out or drastically reduce the lifetime. This seems to concern the RMS voltage however, so pulsing with the correct width could be feasible ..

I would like to have power circuits that do not depend on the microcontroller to provide correct oscillations. An ATTiny-controlled H-bridge would probably remain open in one direction if I program the microcontroller in-system .. eek. Ideally, the board should be usable as a serial-interface to the VFD, so it should not depend on any microcontroller.

There's a number of different approaches here:

* Just use **DC**.

  * Use a regulated converter to provide the correct voltage as DC. It may have a disable pin to cut power but otherwise needs no interfacing.

  * Supply 3.3 V from a microcontroller and pulse-modulate the output to reach the correct average.

* Supply an **AC** voltage.

  * Use an H-bridge (motor controller) that is timed externally. This can be a self-oscillating circuit, a 555 timer or a microcontroller. Hard to get the right timing.

      + _**Note from the future:** this is what I picked for the v2 redesign, where I decided to have a microcontroller on the display driver anyway. This way, I can adjust the direction change frequency and can supply the correct filament voltage from an ADC pin directly. Though, be aware that bad frequencies can lead to high-pitched ringing!_

  * Use two GPIO pins and alternate their HIGH/LOW stated on a microcontroller. Maximum draw might be an issue and we're still dealing with too much voltage.

  * Clone the circuitry of a dedicated filament driver with a self-oscillating audio amplifier, capacitor coupling and center-tap biasing with a zener diode. This is Rolo's design but it's pretty large.

      + _**Another note from the future:** still, this is overall a very nice and clean design. You can dim the display pretty well by PWM-toggling the shutdown pin of the amplifier._

  * **Future note:** The best combination would probably reuse a lot of the circuit (large capacitors and center-tap) from the self-oscillating v1 design but instead drive the direction changes with an H-bridge from v2.

### Interfaces

Do I provide a USB-to-Serial adapter on the board? Can I speak to ATTiny84's in this way at all? I suspect you can only program them over ISP anyway. I could probably just spit out the current time over Serial and allow setting the correct time as well.

Buttons? If any, I think I'd use microswitches along one of the edges. I don't want to have anything at all on the front. Switches might come in handy to quickly control things like brightness or date display?

## Links

A collection of useful links and articles:

* [JohnEngineer's ChronodeVFD](https://archive.is/ODOFR): a steampunk-esque wristwatch powered from a 1.5V Alkaline battery ([flickr](https://www.flickr.com/photos/johngineer/15564850491/), [archive]([https://archive.is/ODOFR](https://archive.is/ODOFR))

* [VFD Watch Demystified](https://www.instructables.com/id/Vacuum-Fluorescent-Display-Watch/): a clone of the wristwatch above, complete with schematics and code ([archive](https://archive.is/ojaD5))

* [WiFi Desk Clock](https://www.thingiverse.com/thing:3479496): instructions on using an ESP32 to power the tube and use NTP

* [VFD Clock](http://vwlowen.co.uk/arduino/vfd/vfd-clock.htm): another design, where the filament is driven directly from two Arduino GPIOs, but also contains a description of a regulated H-bridge driver L9110 ([archive](https://archive.is/Xkr9G))

* [Tiny IV-21 VFD Clock](https://hackaday.io/project/167749-tiny-iv-21-vfd-clock#j-discussions-title) uses a hovering actual tube VFD where the filament is powered directly with a voltage divider through a transistor

* [One more build by Kevin Rye](http://kevinrye.net/index_files/vfd_clock_part3.php) which uses a dedicated - albeit obsolete - filament driver: LM9022 (note: this is the same schematic like Rolo's LM4871 driver) ([archive](https://archive.is/C2UBq))

Some fundamental information on VFD operation:

* [Noritake Itron VFD operation guide](https://www.noritake-elec.com/technology/general-technical-information/vfd-operation): contains extensive descriptions of how to drive the filament with center-tapped AC couplings ([archive](https://archive.is/BsdLR))

* [IV-18 Clock](https://web.jfet.org/inGrid/) contains a description of driving anodes with discrete transistors, the author says not to worry about filament AC ([archive](https://archive.is/tNjHp))

* [A series of posts on idyl.io](https://idyl.io/category/vfd/) follows the design of VFD quasi-dot-matrix displays with several different PSU designs based on OpAmps and H-bridges

* Some EEVblog Forum posts:

  * [Designing and OpAmp based power supply for VFD filaments](https://www.eevblog.com/forum/projects/vfd-filament-power-using-lm4871-replacement-for-obsolete-lm9022/)

  * [Datasheet of an old Amp used for that: LM9022M, with example circuits](https://datasheet.octopart.com/LM9022M/NOPB-National-Semiconductor-datasheet-11896945.pdf)

  * [Rolo shows off his universal VFD PSU](https://www.eevblog.com/forum/projects/showing-my-vfd-psu/) based on an LM4871 OpAmp ([archive, no images](https://archive.is/bkgaG))

  * [One particular reply by Ian which details some filament specifics](https://www.eevblog.com/forum/projects/any-interest-in-vfd-tube-power-supply-boards/msg1607869/#msg1607869)

  * [Rolo / r.kamp's pictures folder on some university server?](http://members.casema.nl/r.kamp/pictures/electronics/vfd_psu)

* [Noritake VFD Driver by Nick Poole](https://github.com/NPoole/VFDLib/tree/main/Driver_Boards), [schematic](https://mobile.twitter.com/NorthAllenPoole/status/1460093862437916677/photo/1) ([archive](https://archive.ph/Z7QLS))
  * 60V boost: LM3488MM/NOPB
  * grid scanning watchdog: CD74HC123ME4
  * VCC1 protection switch with a MOSFET
  * 100kHZ filament driver: LTC6906CS6#TRPBF (R-set oscillator) & MAX628CSA+ (N/P-ch MOSFET)

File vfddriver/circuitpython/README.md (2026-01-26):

# CircuitPython Driver

These `code_*.py` files can be used on a [CircuitPython board](https://circuitpython.org/downloads) to drive the display over I2C. I've used a QT Py ESP32-S3 for most of these.

You may need to install extra libraries for some of these. Use `circup` to do so:

```
circup install asyncio adafruit_connection_manager adafruit_ntp
```

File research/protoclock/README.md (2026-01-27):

# protoclock

Since the fragile legs of the display are pretty hard to use in a breadboard, and also because I wanted to test the schematics for filament and 24V supplies, I constructed this prototype on multiple perfboards instead. The solder joints look horrible but it was my first working clock.



* There is a large carrier board, which holds the HV5812P DIP shift register and an ATtiny84 for control. Additionally, pin headers and enamelled wired connect all the other modules:
* the "high-voltage" (24V) power supply for the grids and anodes,
* a low-voltage AC power supply for the filament, based on a self-oscillating audio amplifier,
* a header for a DS3231 RTC with coin cell battery.

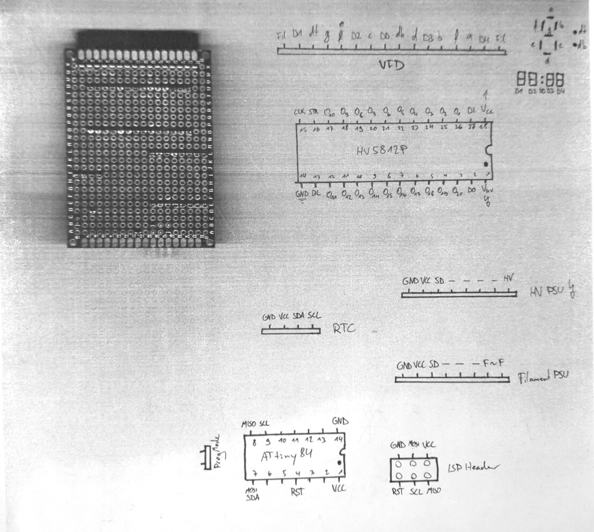
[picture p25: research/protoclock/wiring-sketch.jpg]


The [firmware](firmware/) supports two modes:

* With the jumper closed, the ATtiny drives the display as a standalone clock from the RTC.
* An open jumper makes the microcontroller a peripheral, so you can set the time on the RTC or drive the display directly over I2c.

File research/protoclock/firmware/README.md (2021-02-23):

# protoclock

This is the firmware for my protoboard version of the clock
based on an ATtiny84 and a DS3231 module connected over I2C.

The jumper is read on startup:

* `LOW` (closed) --> I2C mode, address `0x20`
* `HIGH` (open) --> clock mode

In I2C mode you can use the scripts in the sibling directory
to push content onto the display. They're written with an
i2c-tiny-usb in mind.

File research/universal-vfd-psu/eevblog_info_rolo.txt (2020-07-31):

1) For the tubes I ordered I've seen many people just use DC voltage. 
   Since it's pretty low voltage at only 2.4 V with 65 mA per the datasheet and the tube is relatively 
   short I might just get away with using a simple regulator and not waste time thinking about an AC design at all? 
   You seem to be using DC in your IV-22 carrier PCB as well ..
   
   My opinion/experiance is that it's best to use AC on display's that contain multiple characters. 
   I think most factory made clocks used a separate winding on the AC tranformer for the filament.
   You can start with DC, develop your program and then see if AC is needed. Check for segment ghosting. 
   AC is better on the long run, that is hard to check.     

2) If I decide I want to "do it right" and I were to use your universal VFD PSU design rev2 though ..

2.1) Do the coupling capacitors C4 and C5 really need to be that large? 
     It just stands out to me that these capacitors are (physically) that large, while the HV rail uses relatively small ones.
     
     I have copied these values from other designs, I think it must be an electrolyte. 
     The HV rail uses ceramic caps, they are mandatory with the LM2733 (info from the datasheet)

2.2) How would I calculate the correct values for R7, R8, R10 and R11? 
     You have given values for "13 char" and "8 char" displays in your schematic but 
     neither do I know what voltage those displays use, nor would I know I'd calculate mine.
     
     I have an excel sheet to calculate HVout and determine R2 & R13
     R8 and R11 have to be about 5 times the hot filament resistance, choose a nearby E value, not critical.
     I have no calculation for R7 & R10, I did this empirical, using two resistor banks. 
     I do have three tables with values for different display, you can use these as an indication for your application.

3) Could you use something like an SN6501 Transformer Driver with an SMD transformer in place of the self-oscillating circuit with an audio amplifier? Looking at the application schematics in chapter 9 of its datasheet, it should be possible to use this driver without the rectifier diodes and treat the transformer outputs as filament connection points, no? R8, R11 and the bias voltage with the zener diode should work similarly, too. And the output voltage could be selectable by choosing the correct winding ratio?
     Yes, should be possible, I did not go this route. Would be a nice solution. 
     Biggest issue is parts availability, SMD transformers and the SN6501 are less available to me.

Some random tips:
You can experiment with the zener voltage, depends on the display. 2.7V, 3.3V, 4.7V are common values     
You have to measure the actual HV between HVout and the cathode of D2. You will find that it less then HVout to gnd. 
Difference is the zener voltage.

The coils are size 1210
All ceramic caps are size 0805
All resistors (except R7 & R10) are size 0805
R7 & R10 are size 1206
Please do not buy the LM4871 or LM2733 in China, they can be fake.
D1 is package SOD-123
D2 is package SOD-80
 
See bom.xlsx for reichelt partnumbers coils, IC's and electolytic caps

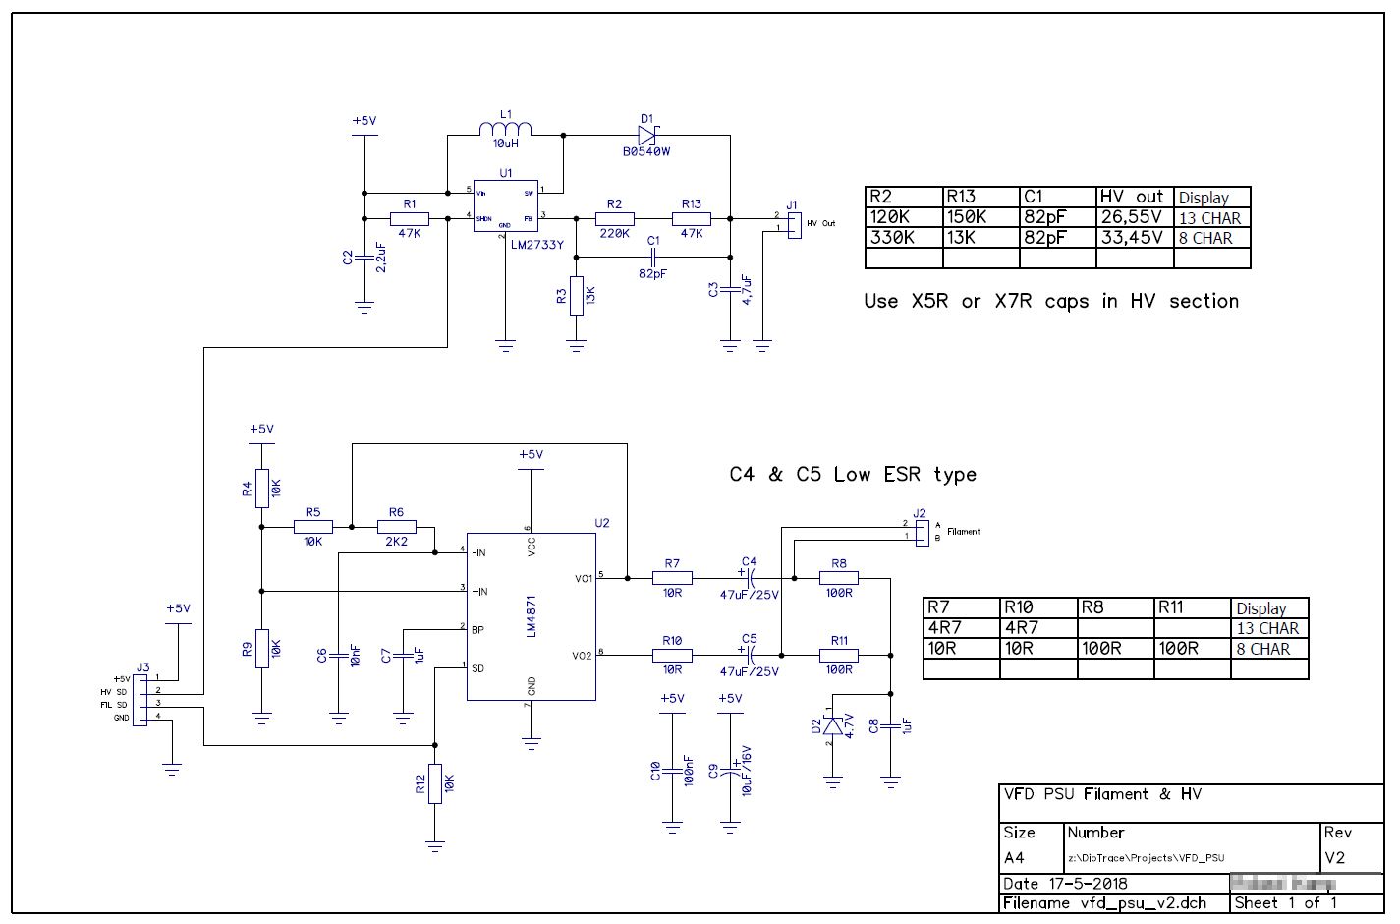
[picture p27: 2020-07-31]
research/universal-vfd-psu/schematic_r2.jpg

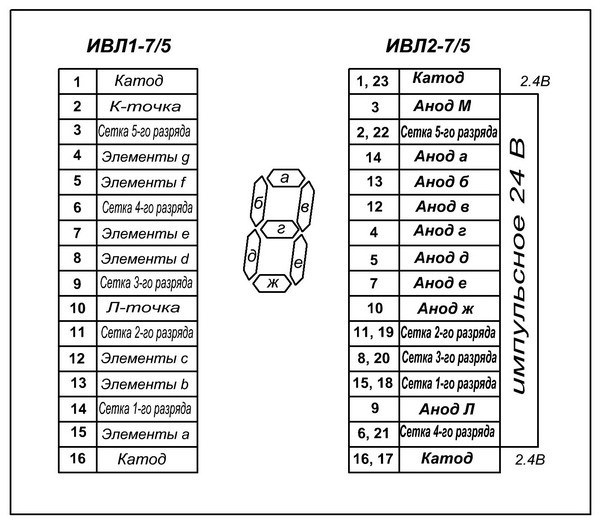
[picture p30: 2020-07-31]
research/ivl2-7_5-datasheets/pinout.jpg

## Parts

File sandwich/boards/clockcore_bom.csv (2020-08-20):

References | Value | Quantity Per PCB | Part | Digi-Key_PN | MPN | Manufacturer
BT1 | Keystone 1058 (CR2032) | 1 | Battery_Cell | 36-1058-ND | 1058 | Keystone
C4 C7 C8 C12 C14 | 100nF | 5 | C_Small | 1276-1099-1-ND | CL21B104KACNNNC | Samsung
C13 | 10nF | 1 | C_Small | 311-1136-1-ND | CC0805KRX7R9BB103 | Yageo
C5 | 10µF | 1 | C_Small | 1276-1096-1-ND | CL21A106KOQNNNE | Samsung
C3 | 1nF | 1 | C_Small | 1276-1020-1-ND | CL21B102KBANNNC | Samsung
C6 | 1µF | 1 | C_Small | 1276-6469-1-ND | CL21B105KAFNNNG | Samsung
C1 C2 C15 | 4.7µF | 3 | C_Small | 1276-1244-1-ND | CL21A475KAQNNNE | Samsung
C10 C11 | 47pF | 2 | C_Small | 311-1107-1-ND | CC0805JRNPO9BN470 | Yageo
C9 | DNP/100nF | 1 | C_Small | 1276-1099-1-ND | CL21B104KACNNNC | Samsung
D4 | 1N5819HW | 1 | D_Schottky_Small | 1N5819HW-FDICT-ND | 1N5819HW-7-F | Diodes Inc.
D2 | PWR RED | 1 | LED_Small | 732-4985-1-ND | 150080SS75000 | Würth
D1 | Photodiode | 1 | D_Photo | VEMD1060X01CT-ND | VEMD1060X01 | Vishay
D3 | USR GRN | 1 | LED_Small | 732-4986-1-ND | 150080VS75000 | Würth
F1 | 500mA | 1 | Polyfuse_Small | 507-1802-1-ND | 0ZCJ0050FF2G | Bel Fuse
FB1 | 220ΩZ | 1 | Ferrite_Bead_Small | 490-16661-1-ND | BLM21PG221SZ1D | Murata
J2 | Ext | 1 | Conn_02x05_Odd_Even | S2011EC-40-ND | PRPC040DAAN-RC | Sullins
J7 | GCT_USB4108-GF-A | 1 | USB_C_Receptacle_USB2.0 | 2073-USB4105-GF-ACT-ND | USB4105-GF-A | GCT
J1 | Header | 1 | Conn_01x08_Male | S7006-ND | PPTC081LFBN-RC | Sullins
J3 | JTAG | 1 | Conn_ARM_JTAG_SWD_10 | 609-3695-6-ND | 20021121-00010C4LF | Amphenol
Q1 | MBT3904DW1T1G | 1 | MBT3904DW1T1G | MBT3904DW1T1GOSCT-ND | MBT3904DW1T1G | ON Semiconductor
R2 R3 R9 R10 R15 R16 | 10kΩ | 6 | R_Small | 311-10.0KCRCT-ND | RC0805FR-0710KL | Yageo
R1 | 1MΩ | 1 | R_Small | 311-1.00MCRCT-ND | RC0805FR-071ML | Yageo
R7 | 1kΩ | 1 | R_Small | 311-1.00KCRCT-ND | RC0805FR-071KL | Yageo
R4 | 2.2kΩ | 1 | R_Small | 311-2.20KCRCT-ND | RC0805FR-072K2L | Yageo
R13 R14 | 27Ω | 2 | R_Small | 311-27.0CRCT-ND | RC0805FR-0727RL | Yageo
R5 R6 R8 | 4.7kΩ | 3 | R_Small | 311-4.70KCRCT-ND | RC0805FR-074K7L | Yageo
R11 R12 | 5.1kΩ | 2 | R_Small | 311-5.1KARCT-ND | RC0805JR-075K1L | Yageo
SW2 | Boot | 1 | SW_Push | CKN12221-1-ND | PTS526 SK15 SMTR2 LFS | C&K
SW1 | Reset | 1 | SW_Push | CKN12221-1-ND | PTS526 SK15 SMTR2 LFS | C&K
U1 | AP2114H-3_3TRG1 | 1 | AP2114H-3_3TRG1 | AP2114H-3.3TRG1DICT-ND | AP2114H-3.3TRG1 | Diodes Inc.
U4 | DS1338Z-33+ | 1 | DS1307ZN+ | DS1338Z-33+T&RCT-ND | DS1338Z-33+T&R | Maxim
U7 | DS18B20U | 1 | DS18B20U | DS18B20U+T&RCT-ND | DS18B20U+T&R | Maxim
U3 | ESP32-WROOM-32 | 1 | ESP32-WROOM-32 | 1965-ESP32-WROOM-32E(8MBFLASH)CT-ND | ESP32-WROOM-32E (8MB) | Espressif
U5 | FT231XS | 1 | FT231XS | 768-1129-1-ND | FT231XS-R | FTDI
U6 | USBLC6-4SC6 | 1 | USBLC6-4SC6 | 497-4492-1-ND | USBLC6-4SC6 | ST Microelectronic
U2 | ‎SN74HCT245PWR‎ | 1 | SN74LVC245AN | 296-8404-1-ND | SN74HCT245PWR | Texas Instruments
Y1 | 32.768Hz, 12.5pF, 45kΩ | 1 | Crystal_GND3 | XC1911CT-ND | ECS-.327-12.5-13FLX-C | ECS Inc.

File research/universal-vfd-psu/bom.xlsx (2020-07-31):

Part | Ref | Package | Reichelt part no
47uF/25V | C4&C5 |  | FK 47/25 AP
10uF/16V | C9 |  | FK 10/16 R
LM4871 | U2 |  | LM 4871 M
LM2733Y | U1 |  | LM 2733 YMF
Coil 4,7uH | L2 | 1210 | LQH3C 4,7µ
Coil 10uH | L1 | 1210 | LQH3C 10µ

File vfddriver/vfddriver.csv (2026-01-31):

Id | Designator | Footprint | Quantity | Designation | Supplier and ref
1 | C1,C3 | C_0805_2012Metric_Pad1.18x1.45mm_HandSolder | 2 | 4.7µF
2 | L1,L2 | L_1210_3225Metric_Pad1.42x2.65mm_HandSolder | 2 | 10µH
3 | R2 | R_0805_2012Metric_Pad1.20x1.40mm_HandSolder | 1 | 13kΩ
4 | R3 | R_0805_2012Metric_Pad1.20x1.40mm_HandSolder | 1 | 240kΩ
5 | R1,R14,R7,R8 | R_0805_2012Metric_Pad1.20x1.40mm_HandSolder | 4 | 10kΩ
6 | C2 | C_0805_2012Metric_Pad1.18x1.45mm_HandSolder | 1 | 82pF
7 | U3 | SOT-23-5_HandSoldering | 1 | LM2733YMF
8 | D1 | D_SOD-123 | 1 | 1N5819HW-7-F
9 | J1 | PinHeader_1x05_P2.54mm_Vertical | 1 | Header
10 | C5 | C_0805_2012Metric_Pad1.18x1.45mm_HandSolder | 1 | 100nF
11 | D2 | LED_0805_2012Metric_Pad1.15x1.40mm_HandSolder | 1 | LED
12 | U2 | SOIC-14_3.9x8.7mm_P1.27mm | 1 | ATtiny414-SS
13 | R6,R5 | R_1206_3216Metric_Pad1.30x1.75mm_HandSolder | 2 | 0Ω
14 | U4 | SOIC-28W_7.5x17.9mm_P1.27mm | 1 | HV5812WG
15 | R4 | R_0805_2012Metric_Pad1.20x1.40mm_HandSolder | 1 | 660Ω
16 | J3 | JST_SH_SM04B-SRSS-TB_1x04-1MP_P1.00mm_Horizontal | 1 | I2C
17 | U5 | SOIC-8_3.9x4.9mm_P1.27mm | 1 | ZXBM5210-S
18 | C6 | C_0805_2012Metric_Pad1.18x1.45mm_HandSolder | 1 | 1µF
19 | C4 | C_0805_2012Metric_Pad1.18x1.45mm_HandSolder | 1 | 10µF
20 | U1 | IVL2-7_5 | 1 | IVL2-5_7

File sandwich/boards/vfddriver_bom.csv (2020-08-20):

References | Value | Quantity Per PCB | Part | Digi-Key PN | MPN | Mfg
C9 | 100nF | 1 | C_Small | 1276-1099-1-ND | CL21B104KACNNNC | Samsung
C4 | 10nF | 1 | C_Small | 311-1136-1-ND | CC0805KRX7R9BB103 | Yageo
C6 | 10µF | 1 | CP_Small | 493-2100-1-ND | UWX1C100MCL1GB | Nichicon
C5 C10 | 1µF | 2 | C_Small | 1276-6469-1-ND | CL21B105KAFNNNG | Samsung
C1 C2 | 4.7µF | 2 | C_Small | 587-5485-1-ND | UMK212BBJ475KG-T | Taiyo Yuden
C7 C8 | 47µF | 2 | CP_Small | 493-6385-1-ND | UCD1E470MCL1GS | Nichicon
C3 | 82pF | 1 | C_Small | 311-1110-1-ND | CC0805JRNPO9BN820 | Yageo
D1 | 1N5819HW-7-F | 1 | 1N5819 | 1N5819HW-FDICT-ND | 1N5819HW-7-F | Diodes Inc.
D2 | 3.3V | 1 | D_Zener_Small | MMSZ4684T1GOSCT-ND | MMSZ4684T1G | ON Semi
J1 | Connection Header | 1 | Conn_01x08_Male | S2112EC-40-ND | PREC040DBAN-M71RC | Sullins
L1 | 10µH | 1 | L_Small | 587-6332-1-ND | LBC3225T100MR | Taiyo Yuden
R4 R5 R6 R7 R9 | 10kΩ | 5 | R_Small | 311-10.0KCRCT-ND | RC0805FR-0710KL | Yageo
R10 R11 | 12Ω 0.25W | 2 | R_Small | 311-10.0FRCT-ND | RC1206FR-0710RL | Yageo
R2 | 13kΩ | 1 | R_Small | 311-13.0KCRCT-ND | RC0805FR-0713KL | Yageo
R8 | 2.2kΩ | 1 | R_Small | 311-2.20KCRCT-ND | RC0805FR-072K2L | Yageo
R12 R13 | 220Ω | 2 | R_Small | 311-220CRCT-ND | RC0805FR-07220RL | Yageo
R3 | 240kΩ | 1 | R_Small | 311-240KCRCT-ND | RC0805FR-07240KL | Yageo
R1 R14 | 47kΩ | 2 | R_Small | 311-47.0KCRCT-ND | RC0805FR-0747KL | Yageo
U4 | HV5812WG | 1 | HV5812WG | HV5812WG-GCT-ND | HV5812WG-G | Microchip
U1 | IVL2-5_7 | 1 | IVL2-5_7 |  | IVL2-7/5
U3 | LM2733YMF | 1 | LM2733YMF | LM2733YMF/NOPBCT-ND | LM2733YMF/NOPB | Texas Instr
U2 | LM4871MX_NOPB | 1 | LM4871MX_NOPB | LM4871MX/NOPBCT-ND | LM4871MX/NOPB | Texas Instr

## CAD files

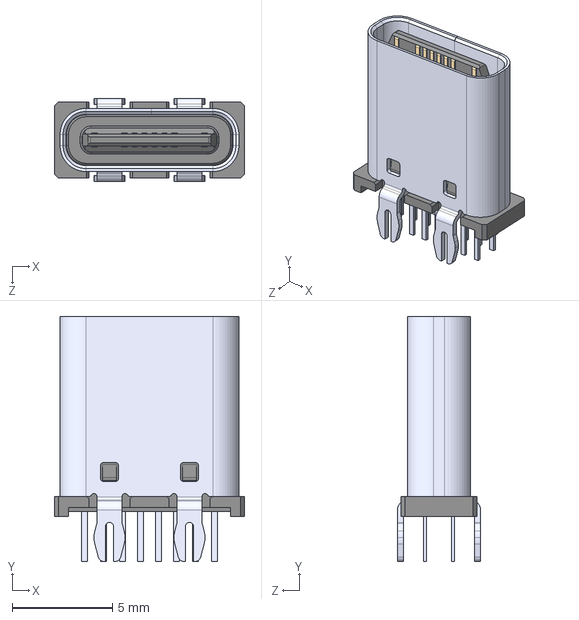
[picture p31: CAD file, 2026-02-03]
kicad_library/3dmodels/UJ20-C-V-C-2-SMT-TR.step
9.50 x 12.2 x 4.16 mm

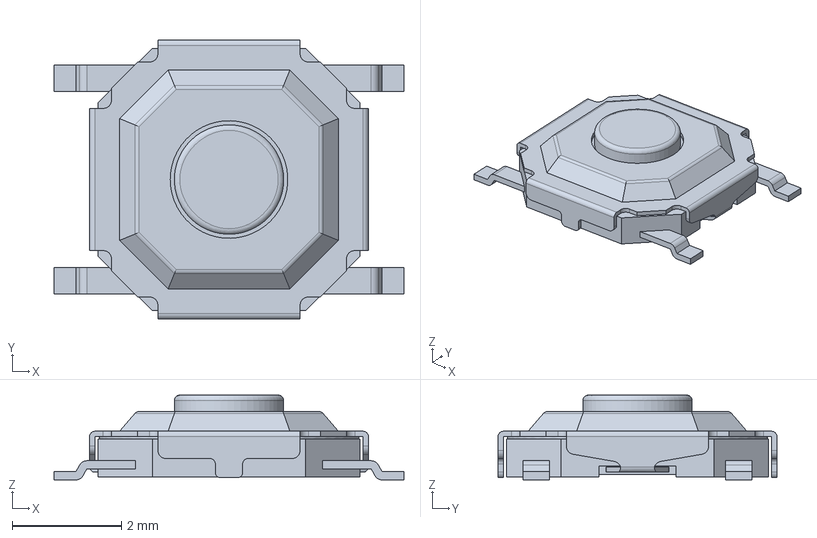
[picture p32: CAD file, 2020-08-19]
sandwich/boards/extra_libraries/PTS526SPG15SMTR2LFS.stp
6.40 x 5.10 x 1.55 mm

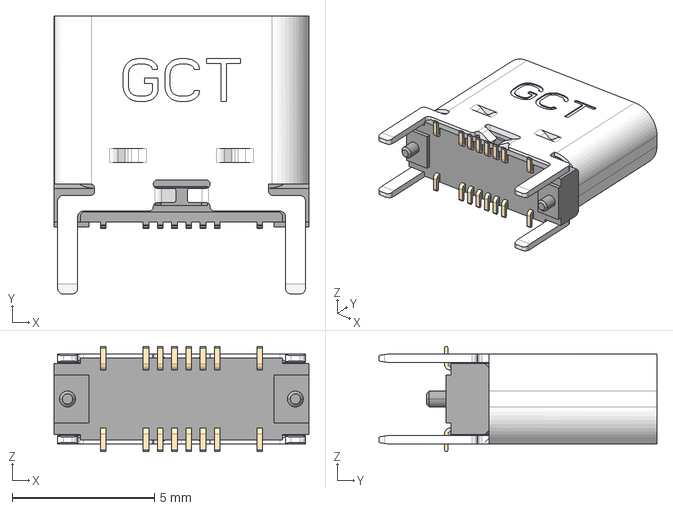
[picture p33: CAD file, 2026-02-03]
kicad_library/3dmodels/usb4145-03-0230-c.stp
8.95 x 9.76 x 3.69 mm

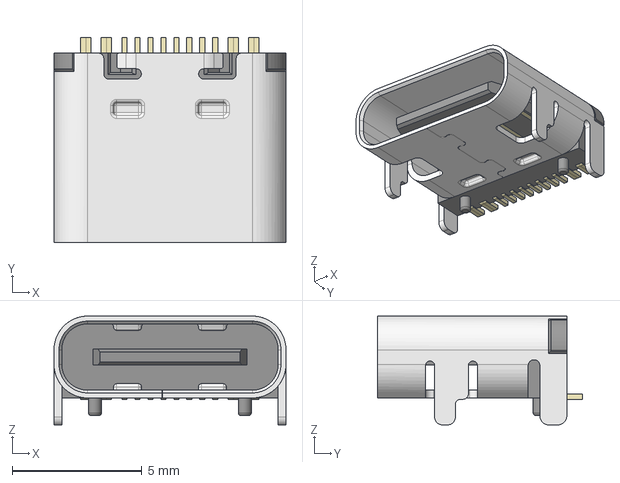
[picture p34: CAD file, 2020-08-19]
sandwich/boards/extra_libraries/USB_C_Receptacle_HRO_TYPE-C-31-M-12.step
8.95 x 7.90 x 4.20 mm

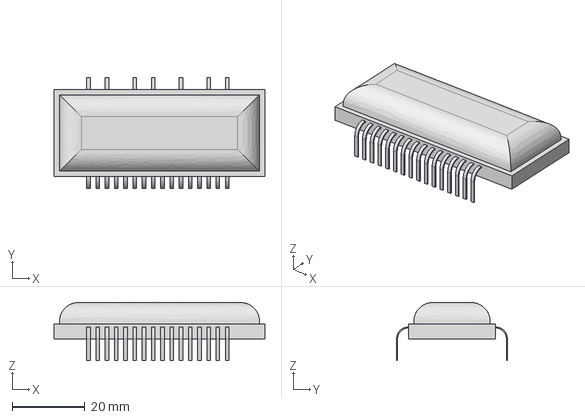
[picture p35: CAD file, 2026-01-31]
kicad_library/3dmodels/VFD_Display v1.step
58.0 x 30.5 x 16.0 mm

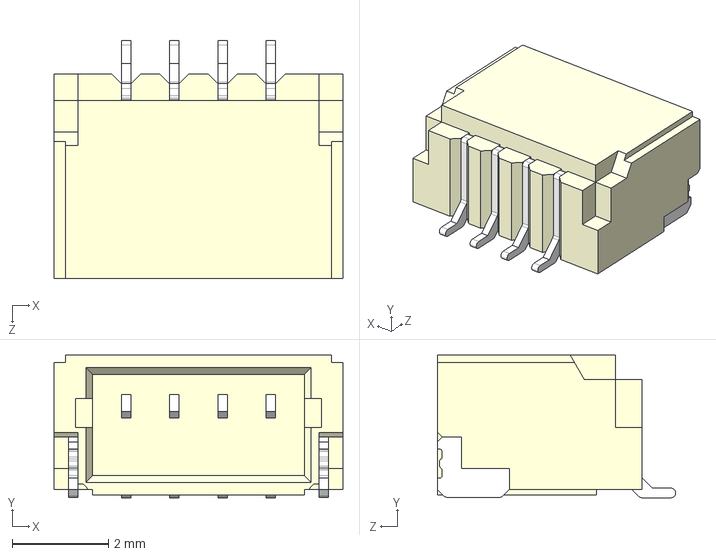
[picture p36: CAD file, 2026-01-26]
kicad_library/3dmodels/SM04B-SRSS-TB(LF)(SN)--3DModel-STEP-56544.stp
6.00 x 2.96 x 4.95 mm

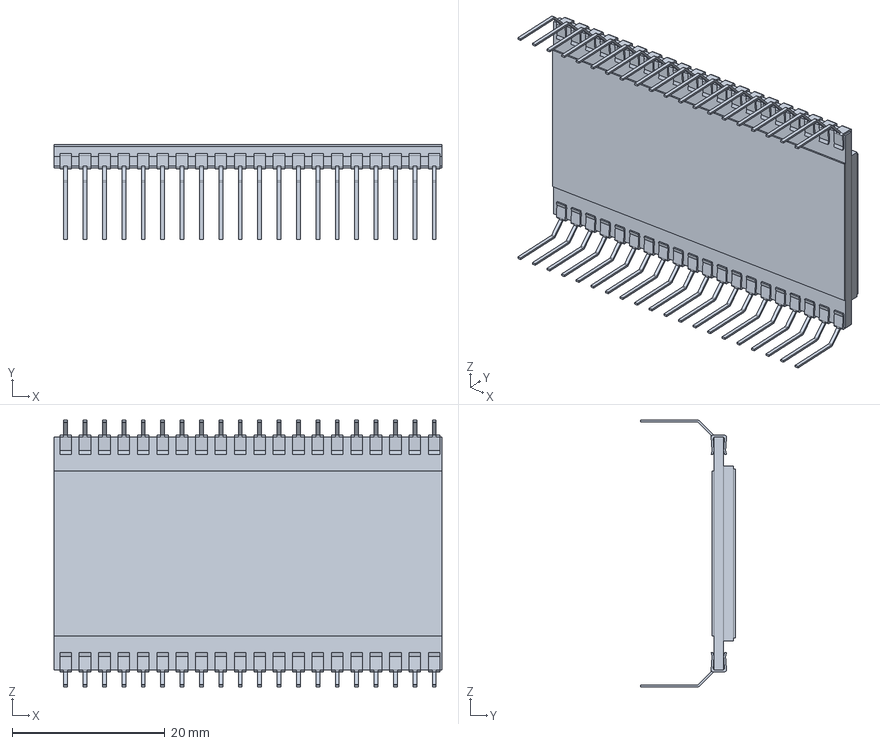
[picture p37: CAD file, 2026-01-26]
kicad_library/3dmodels/de113-lcd-1.step
50.8 x 12.4 x 34.9 mm
eMachineShop.1.1
eMachineShop.1.2
eMachineShop.1.3
eMachineShop.1.4
eMachineShop.1.5
eMachineShop.1.6
eMachineShop.2.1
eMachineShop.2.2
eMachineShop.2.3
eMachineShop.2.4
eMachineShop.2.5
eMachineShop.2.6
eMachineShop.3.1
eMachineShop.3.2
eMachineShop.3.3
eMachineShop.3.4
eMachineShop.3.5
eMachineShop.3.6
eMachineShop.4.1
eMachineShop.4.2
eMachineShop.4.3
eMachineShop.4.4
eMachineShop.4.5
eMachineShop.4.6
eMachineShop.5.1
eMachineShop.5.2
eMachineShop.5.3
eMachineShop.5.4
eMachineShop.5.5
eMachineShop.5.6
eMachineShop.5.7
eMachineShop.5.8
eMachineShop.5.9
eMachineShop.5.10
eMachineShop.5.11
eMachineShop.5.12
eMachineShop.5.13
eMachineShop.5.14
eMachineShop.5.15
eMachineShop.5.16
eMachineShop.5.17
eMachineShop.5.18
eMachineShop.5.19
eMachineShop.5.20
eMachineShop.5.21
eMachineShop.5.22
eMachineShop.5.23
eMachineShop.5.24
eMachineShop.5.25
eMachineShop.5.26
eMachineShop.5.27
eMachineShop.5.28
eMachineShop.5.29
eMachineShop.5.30
eMachineShop.5.31
eMachineShop.5.32
eMachineShop.5.33
eMachineShop.5.34
eMachineShop.5.35
eMachineShop.5.36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

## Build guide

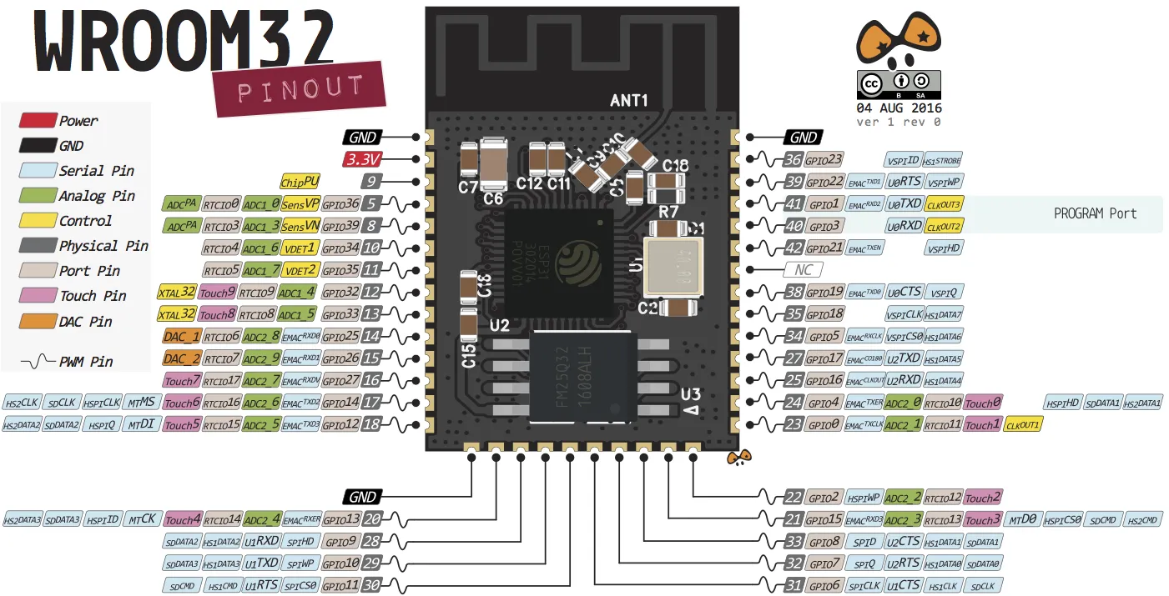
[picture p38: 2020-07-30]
sandwich/render/esp32-wroom-32-pinout-randomnerdtutorials.png

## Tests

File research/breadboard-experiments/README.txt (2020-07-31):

# Breadboard Experiments

These were some first tests using the HV5812P shift register
and an Adafruit FT232H for SPI communication.

I don't have wiring diagrams anymore, sorry.

| file | function |
| ---- | --- |
| `helo.py` | simply displays `HELO` in the segments |
| `clock.py` | display the current time with blinking second dots |

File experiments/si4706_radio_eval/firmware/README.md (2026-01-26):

# Si4706 Examples

These are code samples for a CircuitPython device to use this FM
testing board and try to find suitably strong radio signals and
get a current time from the RDS signal.

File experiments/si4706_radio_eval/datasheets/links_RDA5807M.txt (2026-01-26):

https://www.mouser.com/datasheet/2/744/Seeed_107020006-1217577.pdf
https://github.com/Seeed-Studio/I2C_FM_Receiver/blob/master/I2C_FM.ino
https://w.electrodragon.com/w/Category:FM
https://www.mikrocontroller.net/topic/313562#3411429
https://www.mikrocontroller.net/topic/381652

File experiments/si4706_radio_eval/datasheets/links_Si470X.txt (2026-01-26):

https://radio-bastler.de/forum/showthread.php?tid=14455
https://www.instructables.com/Si4703-FM-Radio-Arduino-Uno-Schield/
https://learn.sparkfun.com/tutorials/si4703-fm-radio-receiver-hookup-guide
https://www.mathertel.de/Arduino/RadioLibrary3.aspx

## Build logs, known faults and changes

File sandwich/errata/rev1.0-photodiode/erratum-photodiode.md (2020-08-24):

# Fix the ambient light sensor on rev 1.0 boards

The ambient light sensor in the form of a photodiode on D1 was added and placed
as one of the last components before ordering the first batch of PCBs. As such
I haven't actually calculcated how much of a voltage drop the diode would cause
and overlooked that the ADC of the ESP32 could not actually measure the
difference between 3.3V and 3.1V accurately.

To remedy this and move the measured voltage to the other side of the spectrum
closer to GND a small modification to the circuit board is necessary. The
modification is incorporated in revision 1.1 and the change is as follows:

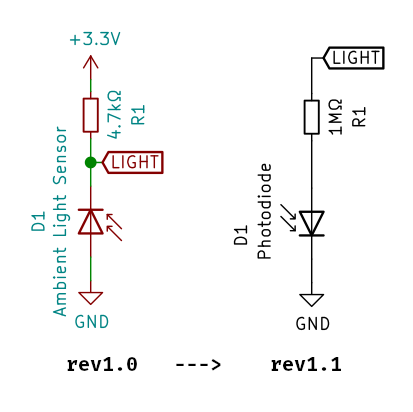
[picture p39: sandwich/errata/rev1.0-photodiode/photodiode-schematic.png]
screenshots showing the changes between schematics rev 1.0 and 1.1


That means:

* If already assembled, desolder `R1` and `D1`.
* Cut the trace between the footprints of `R1` and `D1` with a sharp tool.¹
* Solder `D1` back in reverse direction, so the diode's anode is on the cathode
  side of the footprint (in the silkscreen box).³
* Put a `1MΩ` resistor over the previously cut trace, connecting the diode's
  anode and the trace going to the ESP32.²
* The `+3.3V` pad of the `R1` footprint remains unpopulated!

## Pictures:

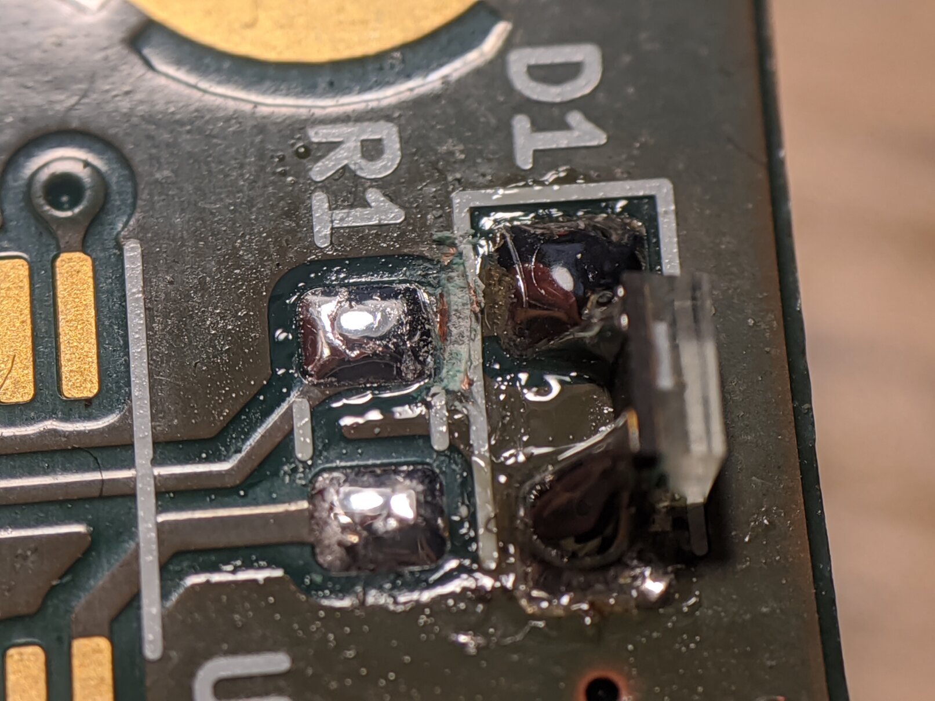
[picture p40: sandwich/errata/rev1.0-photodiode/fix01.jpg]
1) cut the trace between D1 and R1

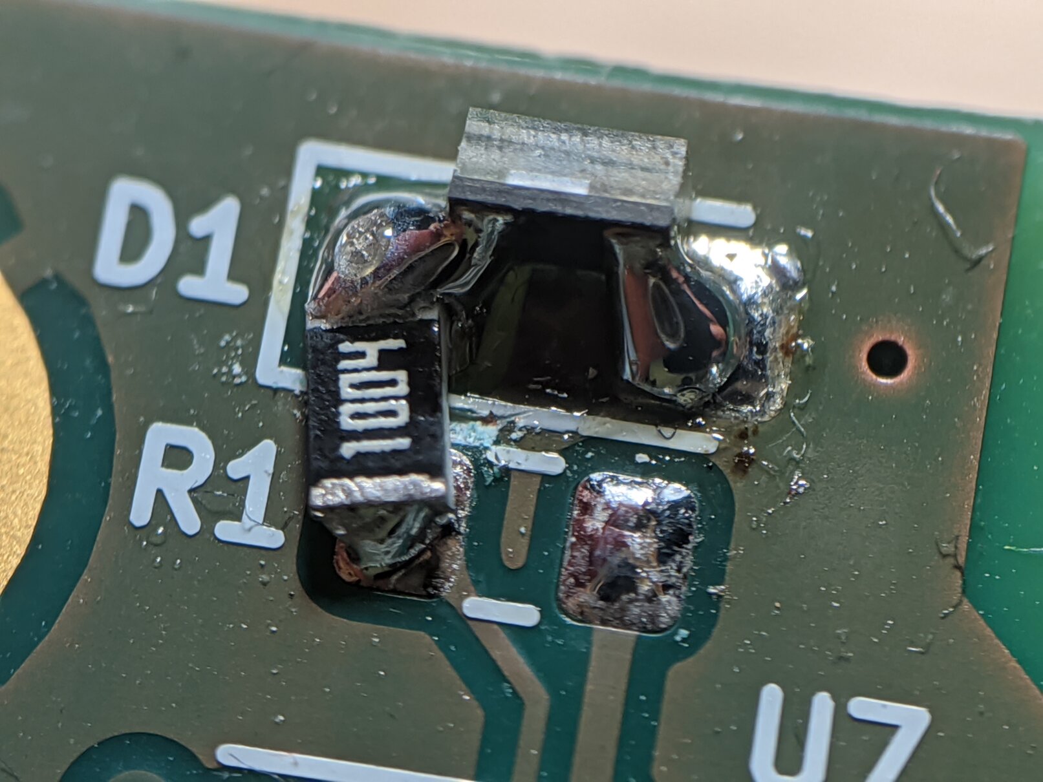
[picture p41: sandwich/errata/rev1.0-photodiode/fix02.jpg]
2) put a 1 megaohm resistor on these now-disconnected pads

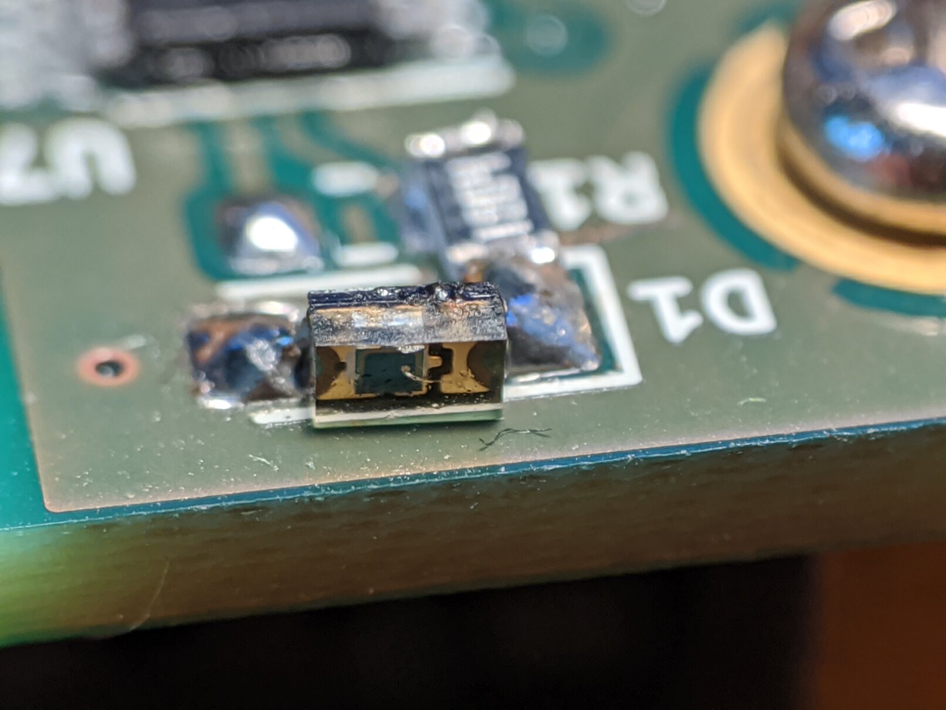
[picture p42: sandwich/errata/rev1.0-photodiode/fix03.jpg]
3) top view showing the orientation of the vishay photodiode


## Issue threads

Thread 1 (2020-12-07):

document provisioning mode better

ansemjo, 2020-12-07:
the first person who was not me or my roommate assembled a chronovfd and they had trouble with provisioning ..

* in the most recent firmware, holding the `boot0` button will reset to "factory" settings and delete the saved wireless credentials
* apparently a somewhat recent device with bluetooth le support is necessary for the current provisioning mode?

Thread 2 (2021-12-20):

automated workflow to check firmware build

ansemjo, 2021-12-20:
I was contacted with a request for help in building the firmware and noticed that due to some updated package names in the PlatformIO toolchains / framework my pinned versions in `platformio.ini` were apparently ineffective.

Maybe create a simple scheduled GitHub workflow that tries to build the firmware from a fresh `HEAD` clone to detect such problems early.

ansemjo, 2022-01-11:
fixed in c2c7b33cb1a6d2b7752a84c55f2d39de58642ff3

Closed 2022-01-11.

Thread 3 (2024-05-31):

Problem finding how to set GMT

nikkisstuff, 2024-05-31:
I have built the clock and it works flawlessly But i am not very good with coding please could you tell me what i need to change to configure GMT

Thanks

ansemjo, 2024-05-31:
That is wonderful to hear! ☺️

The timezone is configured in `main.c` with a `setenv( )` call: https://github.com/ansemjo/chronovfd/blob/c2c7b33cb1a6d2b7752a84c55f2d39de58642ff3/firmware/src/main.c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

According to the [linked CSV file](https://github.com/nayarsystems/posix_tz_db/blob/1f0cc11d79f7384afcf6acd860d8565165d940db/zones.csv#L459) you should simply change that to:
```c
setenv("TZ", "GMT0", 1);
```

nikkisstuff, 2024-05-31:
Thank you i will try it now

nikkisstuff, 2024-05-31:
I made the changes and set it for GMT/London from the list in the link but its not worked. I took the picture at 3:51pm // ```
Copyright (c) 2020 Anton Semjonov
// Licensed under the MIT License

#include <stdio.h>
#include <stdlib.h>
#include <string.h>
#include <time.h>

#include <freertos/FreeRTOS.h>
#include <freertos/task.h>
#include <freertos/queue.h>
#include <freertos/event_groups.h>

#include <esp_system.h>
#include <esp_log.h>
#include <esp_types.h>
#include <esp_event.h>
#include <nvs_flash.h>
#include <esp_wifi.h>

#include <wifi_provisioning/manager.h>
#include <wifi_provisioning/scheme_ble.h>

#include <driver/gpio.h>

#include "ds1307.h"
#include "vfddriver.h"
#include "segments.h"
#include "realtimeclock.h"
#include "ambientlight.h"
#include "animations.h"
#include "wireless.h"

#define SECONDS configTICK_RATE_HZ

// turn on the usr led, yay
#define LED 5
void led_init() {

  gpio_set_level(LED, 1);
}

/*
  TODO LIST
  - erase nvs and reprovision on long gpio0 button press
  - manage "foreground" task in stack with push/pop
  - use the temperature sensor
*/

void do_sync(TaskHandle_t clock) {

  esp_err_t err;
  if (clock) vTaskSuspend(clock);
  TaskHandle_t loading;
  animation_spinner(&loading);

  wireless_connect();
  err = xEventGroupWaitBits(wireless, WIFI_CONNECTED, false, true, 30 * SECONDS);
  if (err == ESP_ERR_TIMEOUT) goto fail;
  err = sntp_sync(60 * SECONDS);
  if (err == ESP_ERR_TIMEOUT) goto fail;
  wireless_disconnect();
  goto out;

  fail:
  vTaskSuspend(loading);
  vfd_text("FAIL");
  vTaskDelay(2 * SECONDS);

  out:
  vTaskDelete(loading);
  if (clock) vTaskResume(clock);

}

TaskHandle_t factory_reset;

void factory_reset_task(void *arg) {

  ESP_LOGW("factory_reset", "button pressed");
  TickType_t t = xTaskGetTickCount();
  for (int i = 0; i < 5; i++) {
    ESP_LOGW("factory_reset", "in %d ...", 5 - i);
    gpio_set_level(LED, 1);
    vTaskDelayUntil(&t, 0.2 * SECONDS);
    gpio_set_level(LED, 0);
    vTaskDelayUntil(&t, 0.8 * SECONDS);
  }
  gpio_set_level(LED, 1);
  ESP_LOGW("factory_reset", "erase nvs partition & reboot");
  nvs_flash_erase();
  esp_restart();

}

static void IRAM_ATTR factory_reset_isr(void *arg) {

  int level = gpio_get_level(GPIO_NUM_0);
  if (!level) {
    // falling edge, button press
    xTaskCreate(factory_reset_task, "factory reset", 2048, NULL, ESP_TASK_PRIO_MIN + 1, &factory_reset);
  } else {
    // rising edge, release
    if (factory_reset) vTaskDelete(factory_reset);
    gpio_set_level(LED, 0);
  }

}

void factory_reset_watcher_init() {

  gpio_config_t factrst = {
    .mode = GPIO_MODE_INPUT,
    .pin_bit_mask = (1ULL << GPIO_NUM_0),
    .pull_up_en = true,
    .intr_type = GPIO_INTR_ANYEDGE,
  };
  gpio_config(&factrst);

  gpio_install_isr_service(0);
  gpio_isr_handler_add(GPIO_NUM_0, factory_reset_isr, NULL);

}

void app_main() {

  // initialize nonvolatile storage
  esp_err_t err = nvs_flash_init();
  if (err == ESP_ERR_NVS_NO_FREE_PAGES || err == ESP_ERR_NVS_NEW_VERSION_FOUND) {
    ESP_ERROR_CHECK(nvs_flash_erase());
    err = nvs_flash_init();
  }
  ESP_ERROR_CHECK(err);

  // init usr led
  gpio_set_direction(LED, GPIO_MODE_OUTPUT);
  gpio_set_level(LED, 0);
  factory_reset_watcher_init();

  // initialize vacuum flourescent display
  vfd_pin_t vfdcfg = {
    .enable    = VFD_PIN_ENABLE,
    .clock     = VFD_PIN_CLOCK,
    .data      = VFD_PIN_DATA,
    .strobe    = VFD_PIN_STROBE,
    .blank     = VFD_PIN_BLANK,
    .fil_shdn  = VFD_PIN_FILSHDN,
    .hv_shdn   = VFD_PIN_HVSHDN,
  };
  vfd_init_spi(&vfdcfg);
  TaskHandle_t digitmux;
  vfd_init_mux(0.002, &digitmux);

  // initialize filament dimmer via photodiode
  TaskHandle_t ambientlight;
  ambientlight_init(PHOTODIODE, vfdcfg.fil_shdn, &ambientlight);

  // connect to battery-backed rtc
  realtimeclock_init(I2C_SDA, I2C_SCL);
  time_t lastsync = realtimeclock_read_from_rtc();

  // set timezone to Europe/Berlin
  // https://github.com/nayarsystems/posix_tz_db/blob/master/zones.csv
  setenv("TZ", "GMT0BST,M3.5.0/1,M10.5.0", 1);
  tzset();

  // enable and possibly provision credentials the first time
  // nvs_flash_erase(); // always clear creds to force conf
  wireless_init();
  wireless_provision();

  // maybe sync once on startup
  time_t now;
  time(&now);
  if ((lastsync == 0) || (lastsync > now) || ((now - lastsync) > (60 * 60))) {
    ESP_LOGI("main", "last sync more than an hour ago");
    do_sync(NULL);
  }

  // display the current time
  TaskHandle_t clock;
  clockface(&clock);

  // all segments for debug purposes
  // vfd_text("88:88");
  // for (;;) { vTaskDelay(2 * SECONDS); }

  for (;;) {
    sntp_sync_schedule(NULL);
    do_sync(clock);
  }

  wireless_end();

}

```
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

ansemjo, 2024-05-31:
That looks like your clock isn't fetching any time at all, not just a timezone issue ...
- Did it fetch time before, just with a wrong offset?
- Maybe you need to configure the WiFi credentials again after flashing? It has been a long time since I've flashed mine; I don't remember ..
- Try taking out the RTC battery to "force" an NTP update after reset.

nikkisstuff, 2024-05-31:
that did not work i am going to reflash with unmodified firmware to see if that makes a difference

nikkisstuff, 2024-05-31:
After uploading the unmodified firmware it had moved +1 hour

ansemjo, 2024-05-31:
> After uploading the unmodified firmware it had moved +1 hour

Which, again, indicates that the timezone is applied correctly but the clock doesn't fetch the current time from NTP.

Have you tried opening the serial console to the ESP32? There are a lot of logging messages, including success or failure of NTP updates.

Maybe you also need to update the NTP server addresses. If you're in a firewalled network, connections to external NTP servers are sometimes not allowed and you need to use a specific host on-campus or something like that. https://github.com/ansemjo/chronovfd/blob/c2c7b33cb1a6d2b7752a84c55f2d39de58642ff3/firmware/src/realtimeclock.c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

ansemjo, 2024-05-31:
As an aside: I am working on-and-off on the next iteration of this clock, which will fetch the current time from FM radio stations via RDS. No internet and no timezones required. Or at least I hope so ...

nikkisstuff, 2024-05-31:
That sounds very interesting!  I Have pulled the boot message
```
ets Jul 29 2019 12:21:46
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
ansemjo, 2024-05-31:
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

wat. I'm afraid there is some kind of over- or underflow happening here.

* Something clearly went wrong during time calculation if that "last synchronized" time was saved like this. It obviously shouldn't be 1908.
* Notwithstanding, the check in `app_main()` should see that it's been more than an hour and refresh immediately: https://github.com/ansemjo/chronovfd/blob/c2c7b33cb1a6d2b7752a84c55f2d39de58642ff3/firmware/src/main.c#L175

---

If you can live with your clock *always* updating from NTP when plugging in power, you could replace the check entirely and just always force an update:

```diff
diff --git a/firmware/src/main.c b/firmware/src/main.c
index e4f65c8..cea49e2 100644
--- a/firmware/src/main.c
+++ b/firmware/src/main.c
@@ -169,13 +169,9 @@ void app_main() {
   wireless_init();
   wireless_provision();

-  // maybe sync once on startup
-  time_t now;
-  time(&now);
-  if ((lastsync == 0) || (lastsync > now) || ((now - lastsync) > (60 * 60))) {
-    ESP_LOGI("main", "last sync more than an hour ago");
-    do_sync(NULL);
-  }
+  // always sync on startup
+  ESP_LOGI("main", "forcing NTP sync on startup");
+  do_sync(NULL);

   // display the current time
   TaskHandle_t clock;

```

nikkisstuff, 2024-05-31:
that's brilliant I will try it now

nikkisstuff, 2024-06-01:
I left the clock powered up over night and this morning it looks to have synced up with the ntp server. i left the sync delay as 5 in the firmware

Closed 2024-06-02.

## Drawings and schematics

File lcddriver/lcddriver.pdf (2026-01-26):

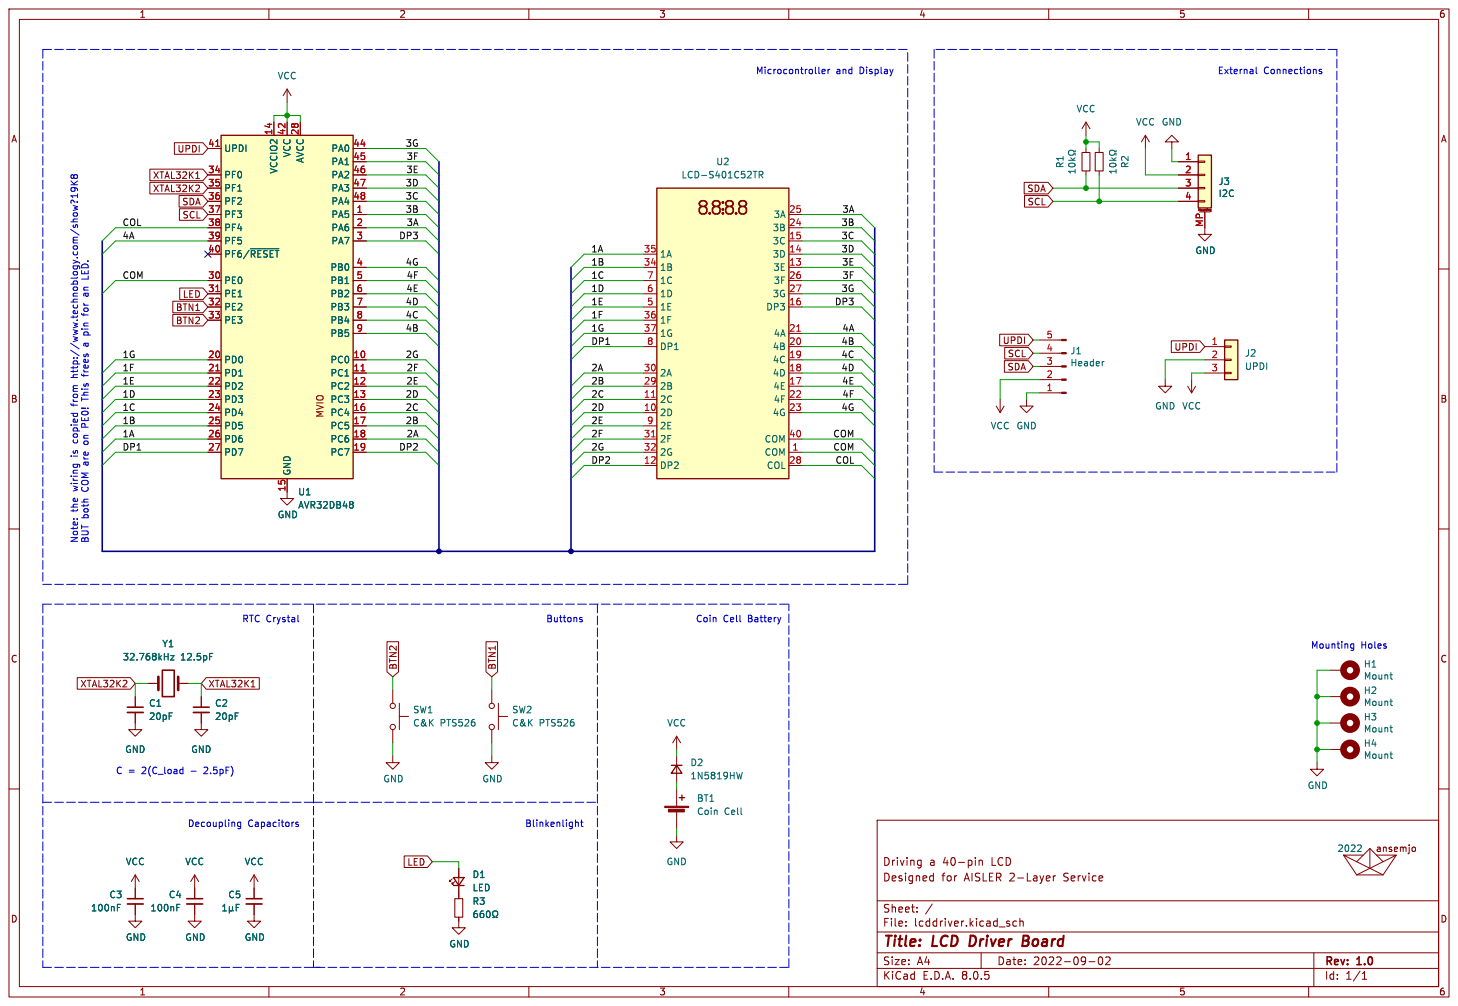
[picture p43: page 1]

H3 Mount H2 Mount H1 Mount UPDI SDA

Mounting Holes Note: the wiring is copied from http://www.technoblogy.com/show?19K8 BUT both COM are on PE0! This frees a pin for an LED.

Id: 1/1 Title: LCD Driver Board

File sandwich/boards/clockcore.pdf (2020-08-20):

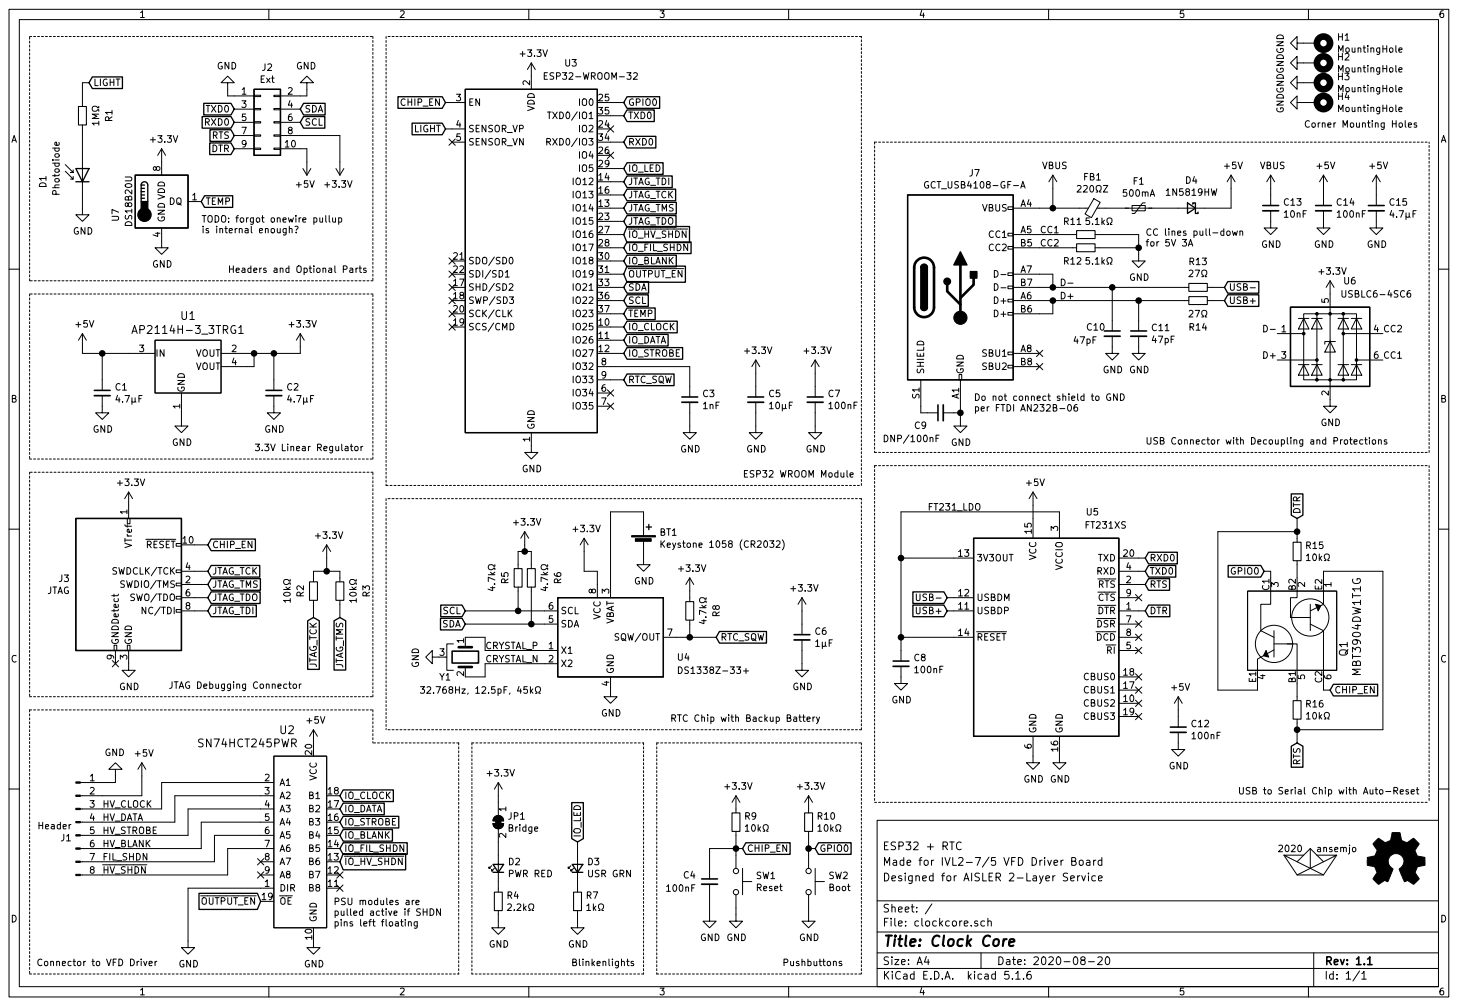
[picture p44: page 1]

2 SCK/CLK 20 SDO/SD0 21 SDI/SD1 22

1 2 JP1 Bridge D1 Photodiode 10k R2 10k R3 GND GND

TODO: forgot onewire pullup
is internal enough?

Headers and Optional Parts
SCL SDA OUTPUT_EN

6 DSR 7 DCD 8 CTS 9 U5 FT231XS D3USR GRN GND

3 SWDCLK/TCK 4 SWO/TDO 6 NC/TDI 8 GNDDetect 9

8 U4DS1338Z-33+ DIR 1 A1 2 A2 3 A3 4 A4 5 A5 6 A6 7 A7 8 A8 9 GND 10 VCC 20 B8 11 B7 12 B6 13 B5 14 B4 15 B3 16 B2 17 B1 18 OE 19 U2 SN74HCT245PWR

4 SDA 5 SCL 6 SQW/OUT 7 VCC

RTC Chip with Backup Battery

File: clockcore.sch Sheet: / Designed for AISLER 2-Layer Service Made for IVL2-7/5 VFD Driver Board ESP32 + RTC

pulled active if SHDN
pins left floating

Id: 1/1 Title: Clock Core

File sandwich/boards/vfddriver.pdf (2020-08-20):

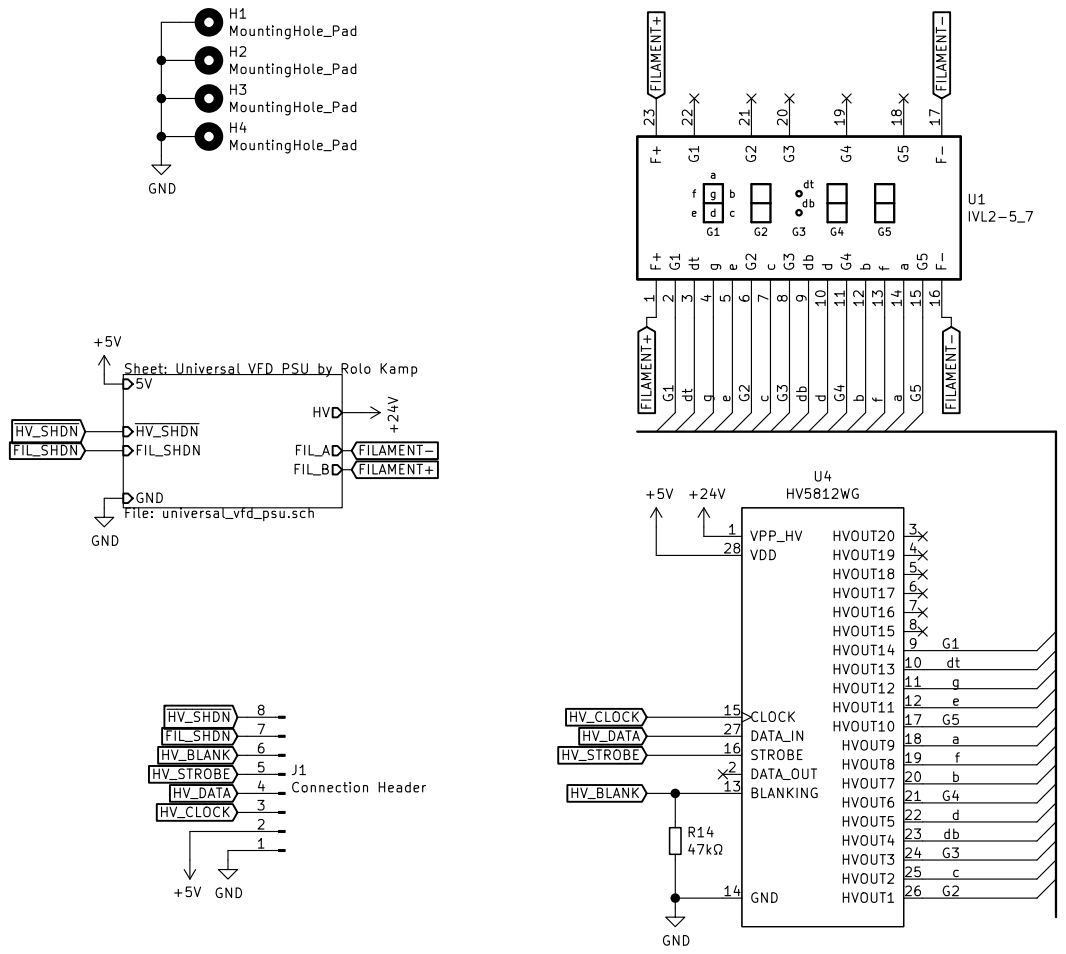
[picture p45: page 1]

Sheet: Universal VFD PSU by Rolo Kamp

Driving an IVL2-7/5 Display
File: vfddriver.sch Sheet: / Designed for AISLER 2-Layer Service

Id: 1/2 Title: VFD Driver Board

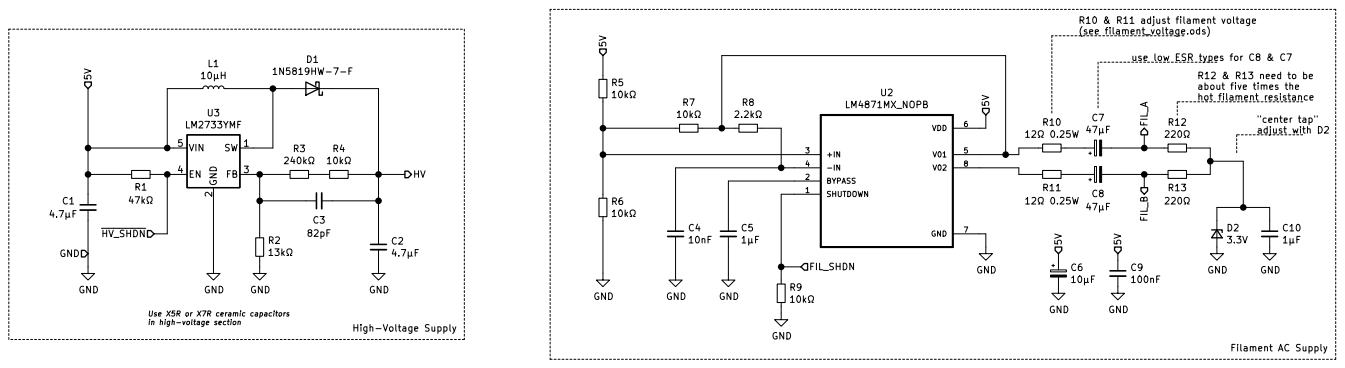
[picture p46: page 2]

use low ESR types for C8 & C7

R12 & R13 need to be
about five times the
hot filament resistance

Filament AC Supply Use X5R or X7R ceramic capacitors

vfd_psu_v2.dch from 2019-04-27
Original Design by Rolo Kamp on EEVBlog

Sheet: /Universal VFD PSU by Rolo Kamp/
File: universal_vfd_psu.sch
Id: 2/2 Title: Universal VFD PSU

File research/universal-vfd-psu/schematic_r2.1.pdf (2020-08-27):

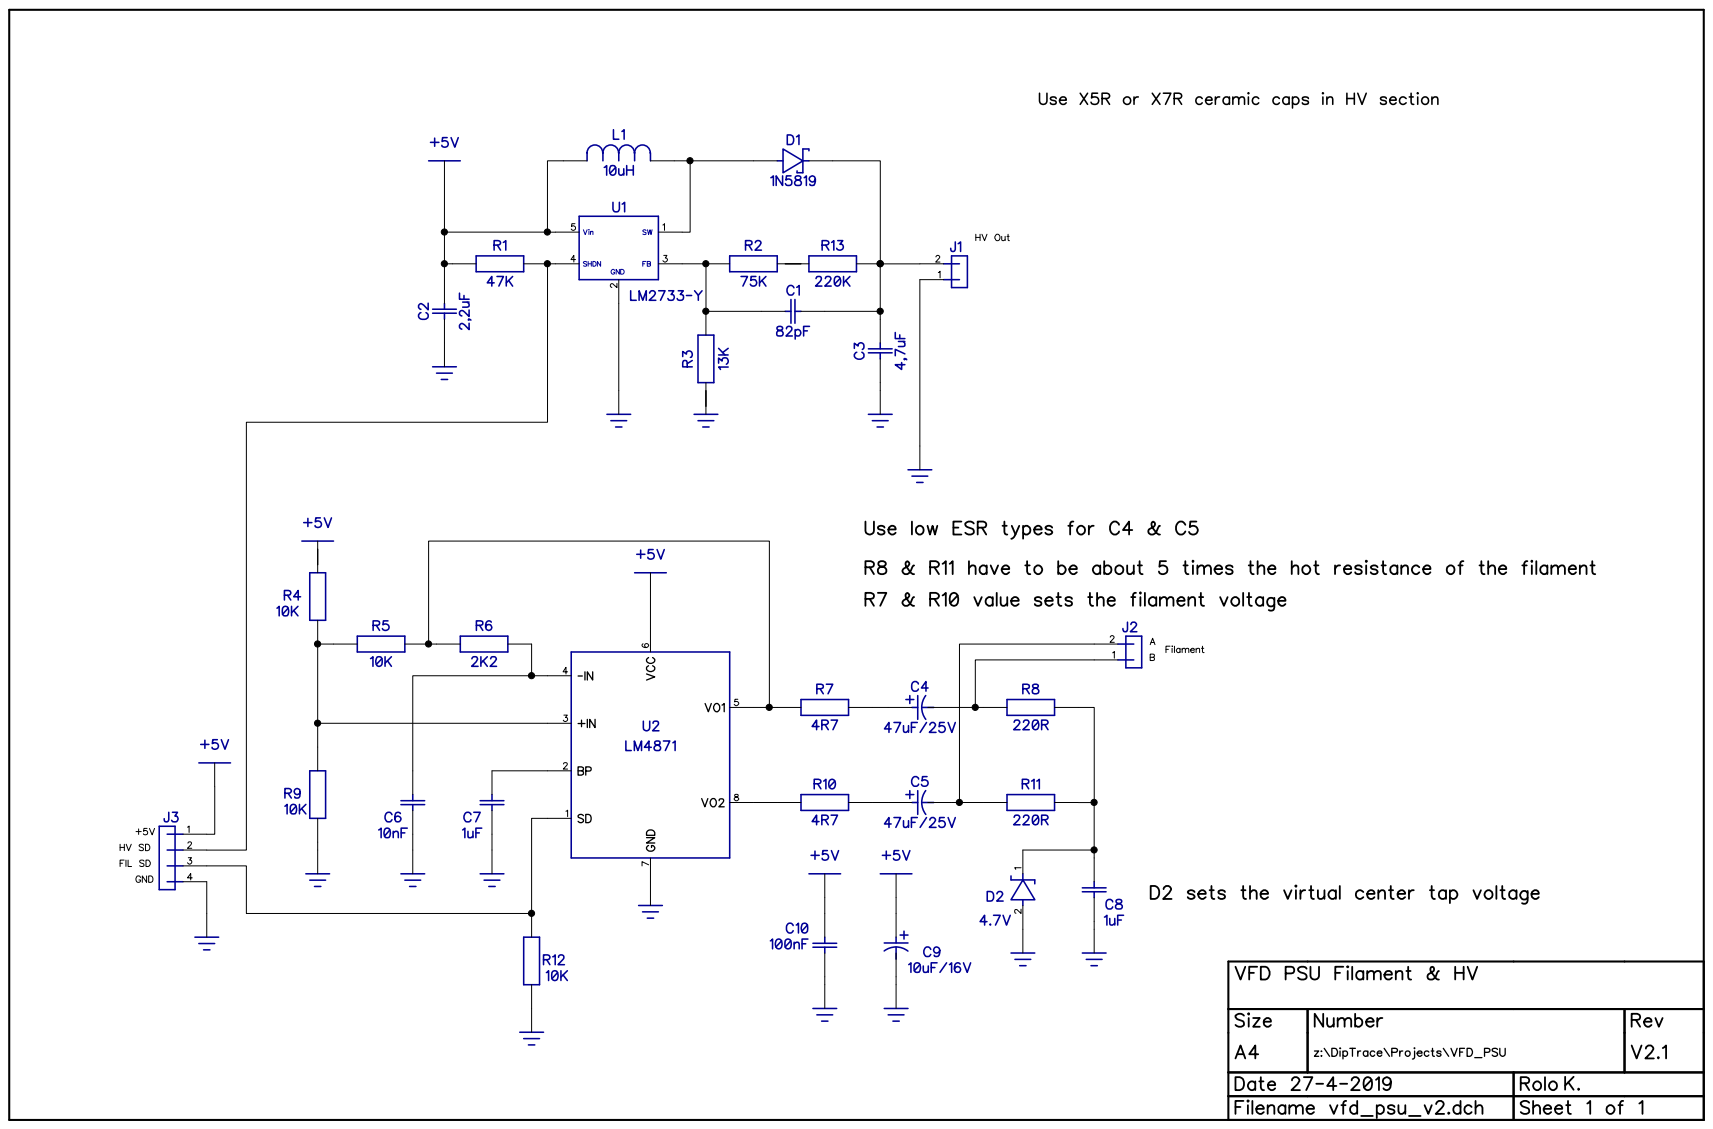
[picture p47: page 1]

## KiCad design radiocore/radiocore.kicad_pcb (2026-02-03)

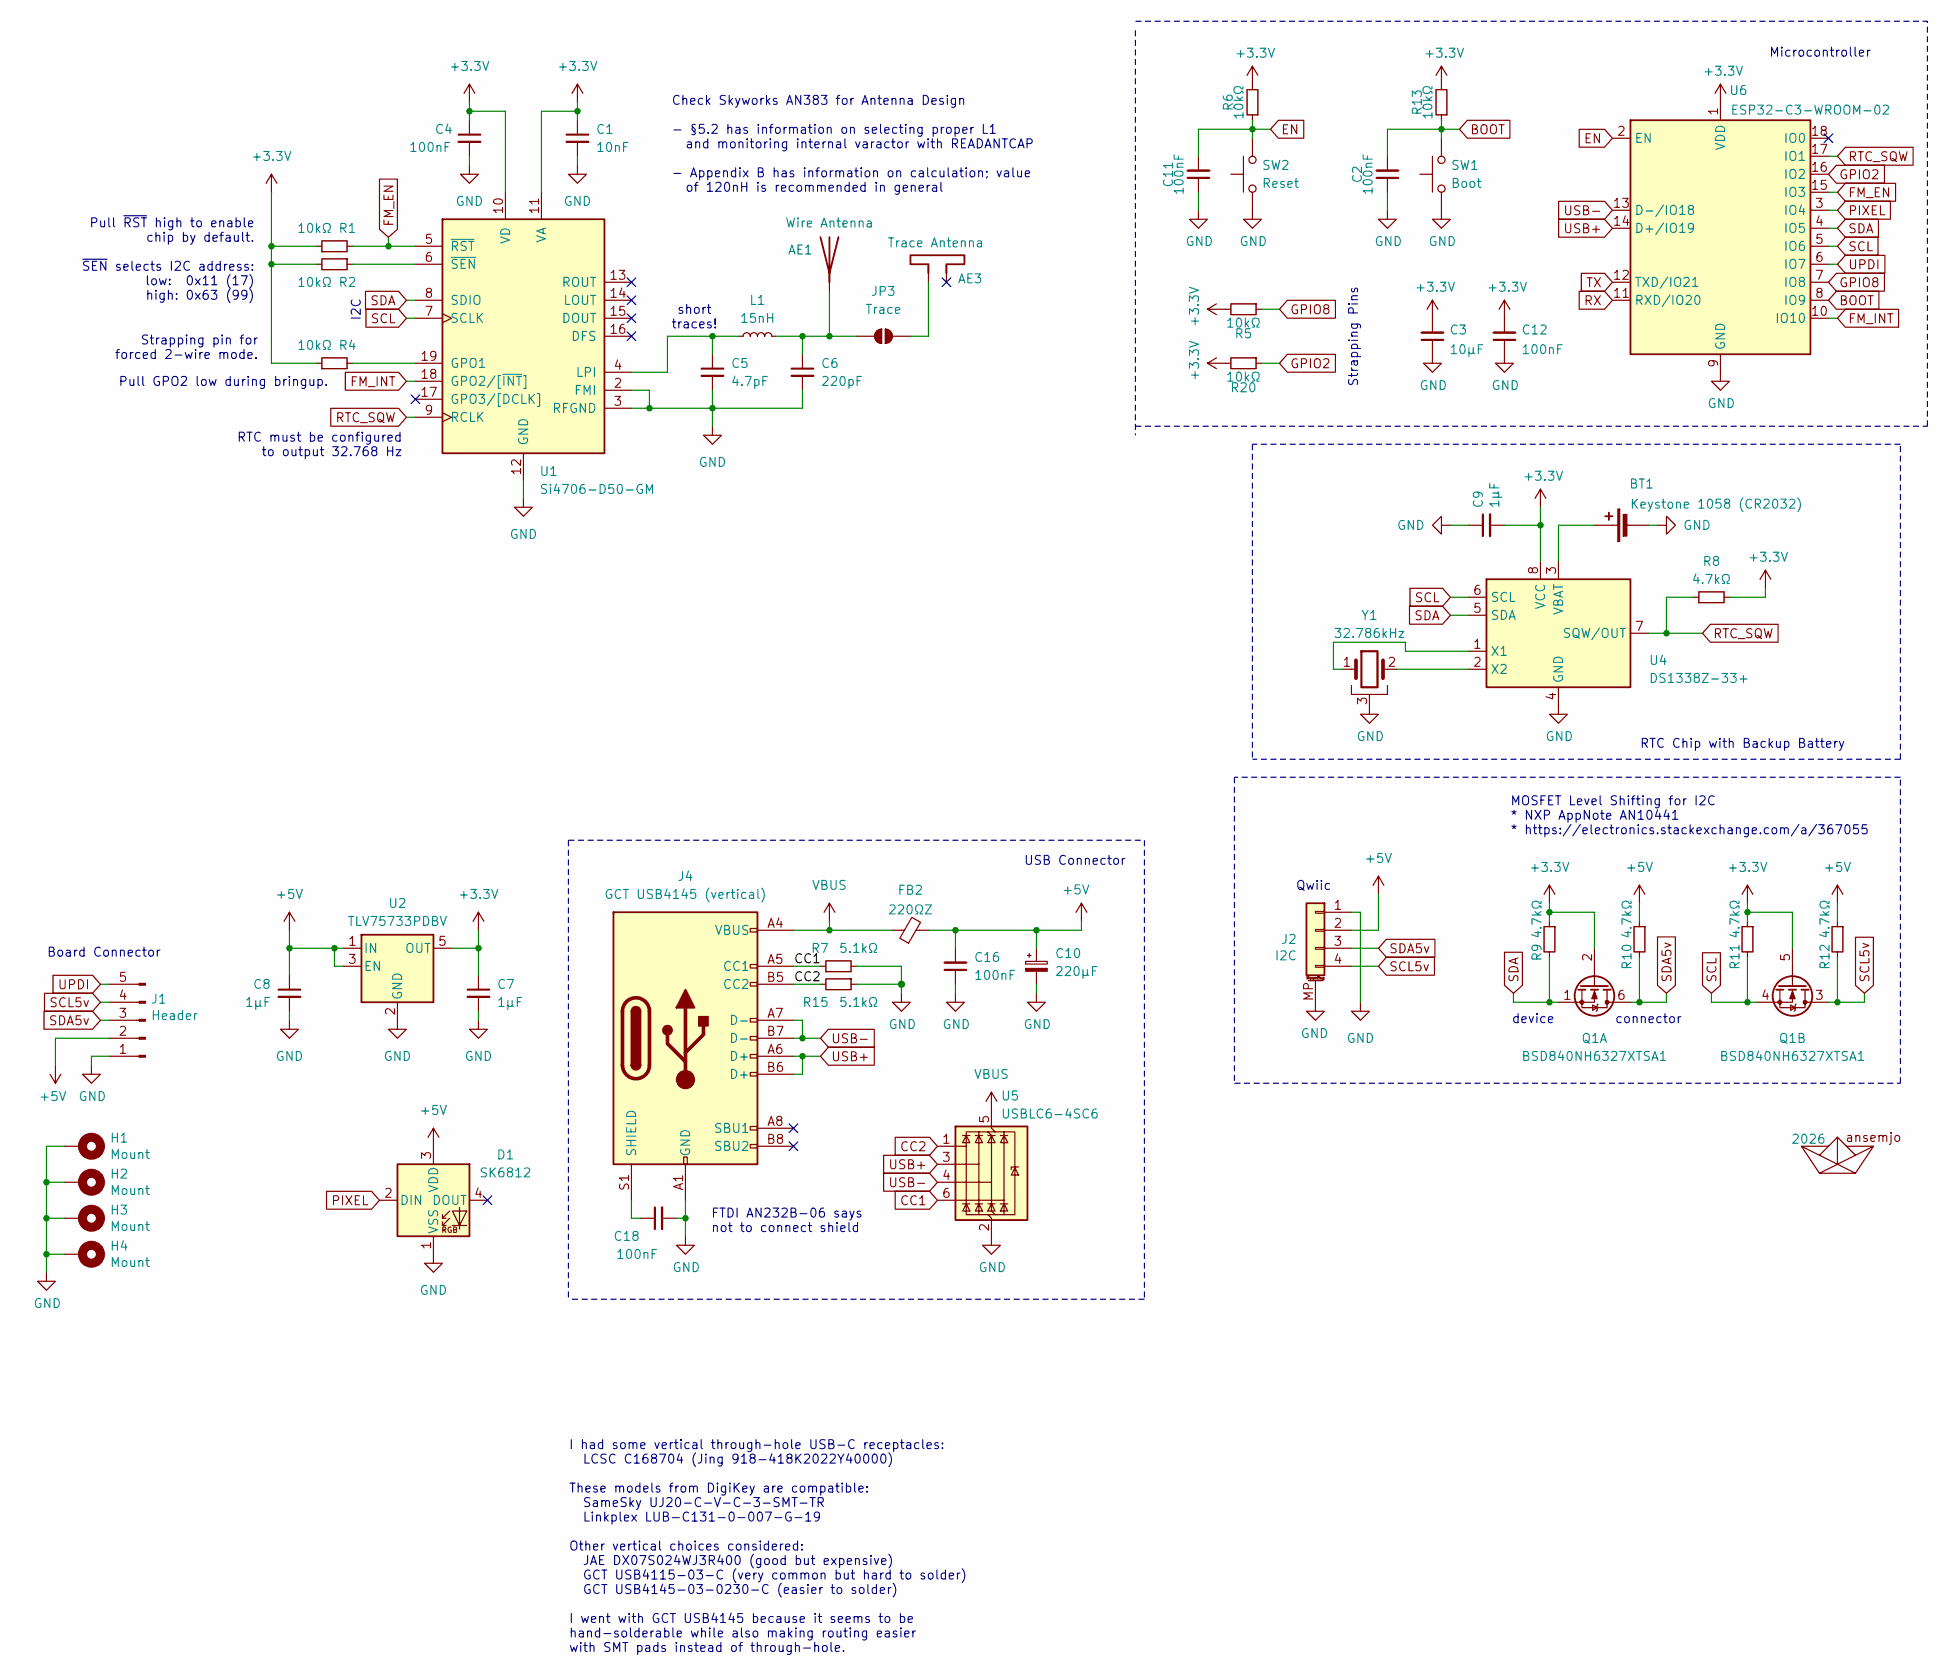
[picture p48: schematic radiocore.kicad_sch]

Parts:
A1: 2026; ahoi
AE1: Wire Antenna; TestPoint_THTPad_D2.0mm_Drill1.0mm
AE3: Trace Antenna
BT1: Keystone 1058 (CR2032); BatteryHolder_Keystone_1058_1x2032; MPN 1058; Digi-Key_PN 36-1058-ND
C1: 10nF; C_0805_2012Metric_Pad1.18x1.45mm_HandSolder
C2, C4, C11, C12, C16: 100nF; C_0805_2012Metric_Pad1.18x1.45mm_HandSolder
C3: 10µF; C_0805_2012Metric_Pad1.18x1.45mm_HandSolder
C5: 4.7pF; C_0805_2012Metric_Pad1.18x1.45mm_HandSolder
C6: 220pF; C_0805_2012Metric_Pad1.18x1.45mm_HandSolder
C7, C8: 1µF; C_0805_2012Metric_Pad1.18x1.45mm_HandSolder
C9: 1µF; C_0805_2012Metric_Pad1.18x1.45mm_HandSolder; MPN CL21B105KAFNNNG; Digi-Key_PN 1276-6469-1-ND
C10: 220µF; CP_EIA-3528-12_Kemet-T_HandSolder
C18: 100nF; C_0805_2012Metric_Pad1.18x1.45mm_HandSolder; MPN CL21B104KACNNNC; Digi-Key_PN 1276-1099-1-ND
D1: SK6812; LED_SK6812_PLCC4_5.0x5.0mm_P3.2mm
FB2: 220ΩZ; L_0805_2012Metric_Pad1.05x1.20mm_HandSolder
H1, H2, H3, H4: Mount; MountingHole_2.7mm_M2.5_Pad
J1: Header; PinHeader_1x05_P2.54mm_Vertical; MPN PREC040DBAN-M71RC; Digi-Key PN S2112EC-40-ND
J2: I2C; JST_SH_SM04B-SRSS-TB_1x04-1MP_P1.00mm_Horizontal
J4: GCT USB4145 (vertical); GCT_USB4145-03-0230-C_REVA2
JP3: Trace; SolderJumper-2_P1.3mm_Open_RoundedPad1.0x1.5mm
L1: 15nH; L_0805_2012Metric_Pad1.05x1.20mm_HandSolder
Q1: BSD840NH6327XTSA1; SOT-363_SC-70-6
R1, R2, R4, R5, R6, R13, R20: 10kΩ; R_0805_2012Metric_Pad1.20x1.40mm_HandSolder
R7, R15: 5.1kΩ; R_0805_2012Metric_Pad1.20x1.40mm_HandSolder
R8: 4.7kΩ; R_0805_2012Metric_Pad1.20x1.40mm_HandSolder; MPN RC0805FR-074K7L; Digi-Key_PN 311-4.70KCRCT-ND
R9, R10, R11, R12: 4.7kΩ; R_0805_2012Metric_Pad1.20x1.40mm_HandSolder
SW1: Boot; SW_SPST_PTS810
SW2: Reset; SW_SPST_PTS810
U1: Si4706-D50-GM; SiliconLabs_QFN-20-1EP_3x3mm_P0.5mm_EP1.8x1.8mm
U2: TLV75733PDBV; SOT-23-5
U4: DS1338Z-33+; SOIC-8_3.9x4.9mm_P1.27mm; MPN DS1338Z-33+T&R; Digi-Key_PN DS1338Z-33+T&RCT-ND
U5: USBLC6-4SC6; SOT-23-6; MPN USBLC6-4SC6; Digi-Key_PN 497-4492-1-ND
U6: ESP32-C3-WROOM-02; ESP-WROOM-02
Y1: 32.786kHz; Crystal_SMD_MicroCrystal_MS1V-T1K

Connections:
+3.3V: C1.1, C3.2, C4.1, C7.1, C9.2, C12.2, Q1.2 (G), Q1.5 (G), R1.1, R2.2, R4.1, R5.2, R6.2, R8.2, R9.1, R11.1, R13.2, R20.2, U1.10 (VD), U1.11 (VA), U2.5 (OUT), U4.8 (VCC), U6.1 (VDD)
+5V: C8.1, C10.1, C16.2, D1.3 (VDD), FB2.2, J1.2, J2.2, R10.1, R12.1, U2.1 (IN), U2.3 (EN)
BOOT: C2.2, R13.1, SW1.2, U6.8 (IO9)
CC1: J4.A5 (CC1), R7.1, U5.6 (I/O4)
CC2: J4.B5 (CC2), R15.2, U5.1 (I/O1)
EN: C11.2, R6.1, SW2.2, U6.2 (EN)
FM_EN: R1.2, U1.5 (~RST), U6.15 (IO3)
FM_INT: U1.18 (GPO2/[~INT]), U6.10 (IO10)
GND: BT1.2 (-), C1.2, C2.1, C3.1, C4.2, C5.2, C6.2, C7.2, C8.2, C9.1, C10.2, C11.1, C12.1, C16.1, C18.2, D1.1 (VSS), H1.1, H2.1, H3.1, H4.1, J1.1, J2.1, J2.MP (MountPin), J4.A1 (GND), J4.A12 (GND), J4.B1 (GND), J4.B12 (GND), R7.2, R15.1, SW1.1, SW2.1, U1.2 (FMI), U1.3 (RFGND), U1.12 (GND), U1.21 (GND), U2.2 (GND), U4.4 (GND), U5.2 (GND), U6.9 (GND), U6.19 (GND), Y1.3
GPIO2: R20.1, U6.16 (IO2)
GPIO8: R5.1, U6.7 (IO8)
unnamed: AE1.1 (A), C6.1, JP3.1 (A), L1.2
unnamed: BT1.1 (+), U4.3 (VBAT)
unnamed: C18.1, J4.S1 (SHIELD)
unnamed: AE3.1, JP3.2 (B)
unnamed: R4.2, U1.19 (GPO1)
unnamed: C5.1, L1.1, U1.4 (LPI)
unnamed: R2.1, U1.6 (~SEN)
unnamed: U4.1 (X1), Y1.1
unnamed: U4.2 (X2), Y1.2
PIXEL: D1.2 (DIN), U6.3 (IO4)
RTC_SQW: R8.1, U1.9 (RCLK), U4.7 (SQW/OUT), U6.17 (IO1)
RX: U6.11 (RXD/IO20)
SCL: Q1.4 (S), R11.2, U1.7 (SCLK), U4.6 (SCL), U6.5 (IO6)
SCL5v: J1.4, J2.4, Q1.3 (D), R12.2
SDA: Q1.1 (S), R9.2, U1.8 (SDIO), U4.5 (SDA), U6.4 (IO5)
SDA5v: J1.3, J2.3, Q1.6 (D), R10.2
TX: U6.12 (TXD/IO21)
UPDI: J1.5, U6.6 (IO7)
USB+: J4.A6 (D+), J4.B6 (D+), U5.3 (I/O2), U6.14 (D+/IO19)
USB-: J4.A7 (D-), J4.B7 (D-), U5.4 (I/O3), U6.13 (D-/IO18)
VBUS: FB2.1, J4.A4 (VBUS), J4.A9 (VBUS), J4.B4 (VBUS), J4.B9 (VBUS), U5.5 (VBUS)

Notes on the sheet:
USB Connector
Microcontroller
RTC Chip with Backup Battery
Qwiic
short traces!
Board Connector
RTC must be configured to output 32.768 Hz
I2C
Check Skyworks AN383 for Antenna Design - §5.2 has information on selecting proper L1 and monitoring internal varactor with READANTCAP - Appendix B has information on calculation; value of 120nH is recommended in general
device
FTDI AN232B-06 says not to connect shield
I had some vertical through-hole USB-C receptacles: LCSC C168704 (Jing 918-418K2022Y40000) These models from DigiKey are compatible: SameSky UJ20-C-V-C-3-SMT-TR Linkplex LUB-C131-0-007-G-19 Other vertical choices considered: JAE DX07S024WJ3R400 (good but expensive) GCT USB4115-03-C (very common but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
Pull ~{RST} high to enable chip by default. ~{SEN} selects I2C address: low: 0x11 (17) high: 0x63 (99)
connector
Pull GPO2 low during bringup.
Strapping Pins
MOSFET Level Shifting for I2C * NXP AppNote AN10441 * https://electronics.stackexchange.com/a/367055
Strapping pin for forced 2-wire mode.

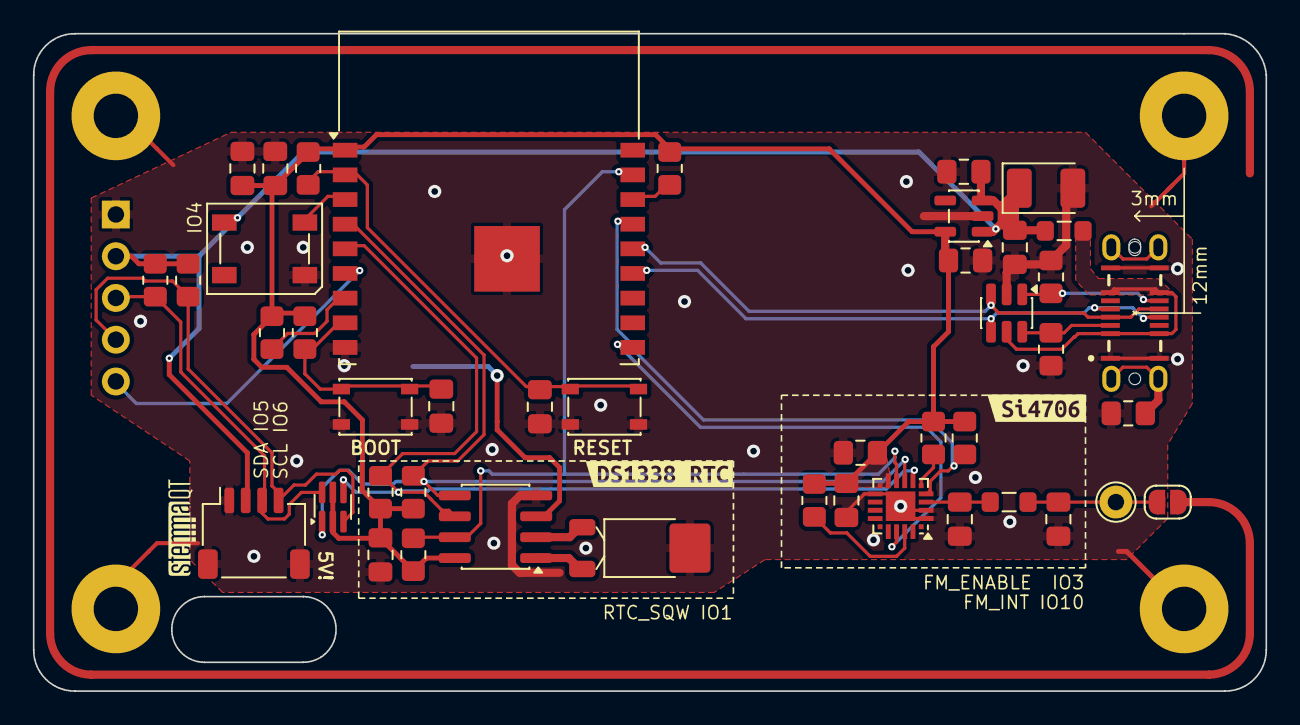
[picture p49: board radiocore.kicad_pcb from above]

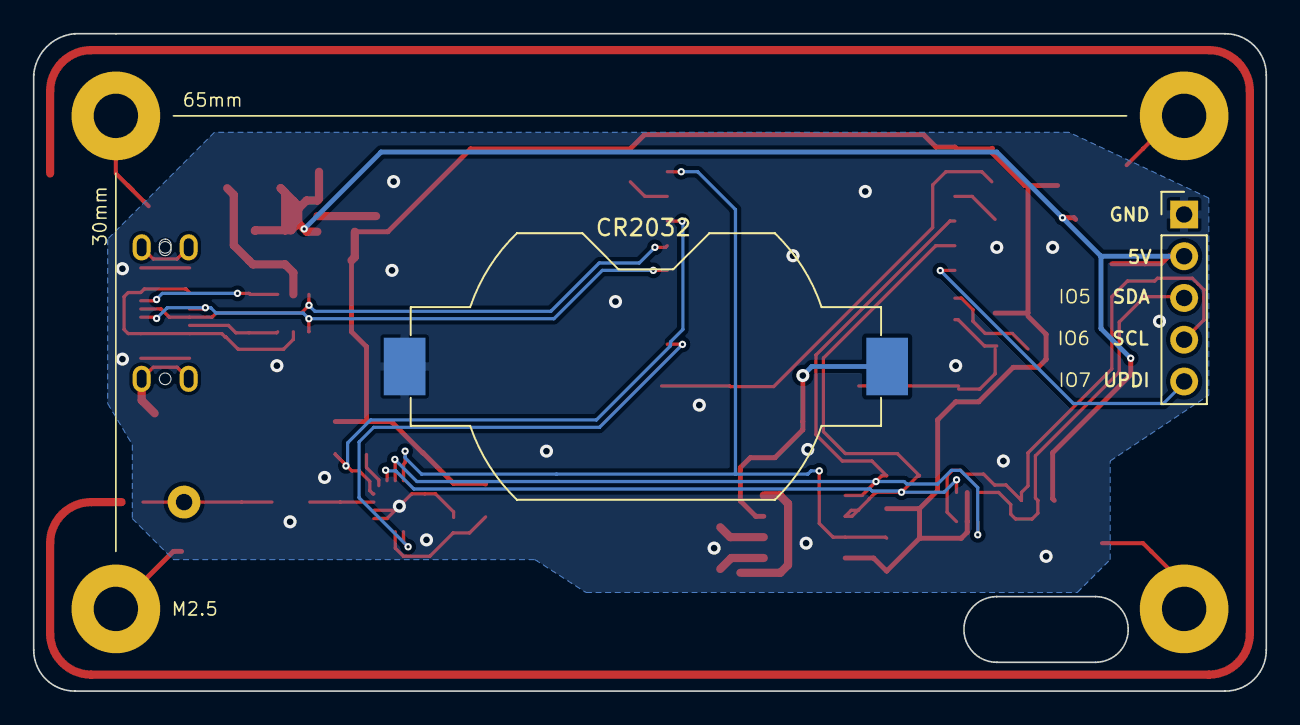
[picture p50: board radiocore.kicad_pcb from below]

Board: 2 copper layers, 75.0 x 40.0 mm, 54 parts (2 on the bottom side), 29 nets.

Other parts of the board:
kibuzzard-69810B1B: G***; kibuzzard-69810B1B
kibuzzard-69810B5E: G***; kibuzzard-69810B5E
kibuzzard-69811623: G***; kibuzzard-69811623

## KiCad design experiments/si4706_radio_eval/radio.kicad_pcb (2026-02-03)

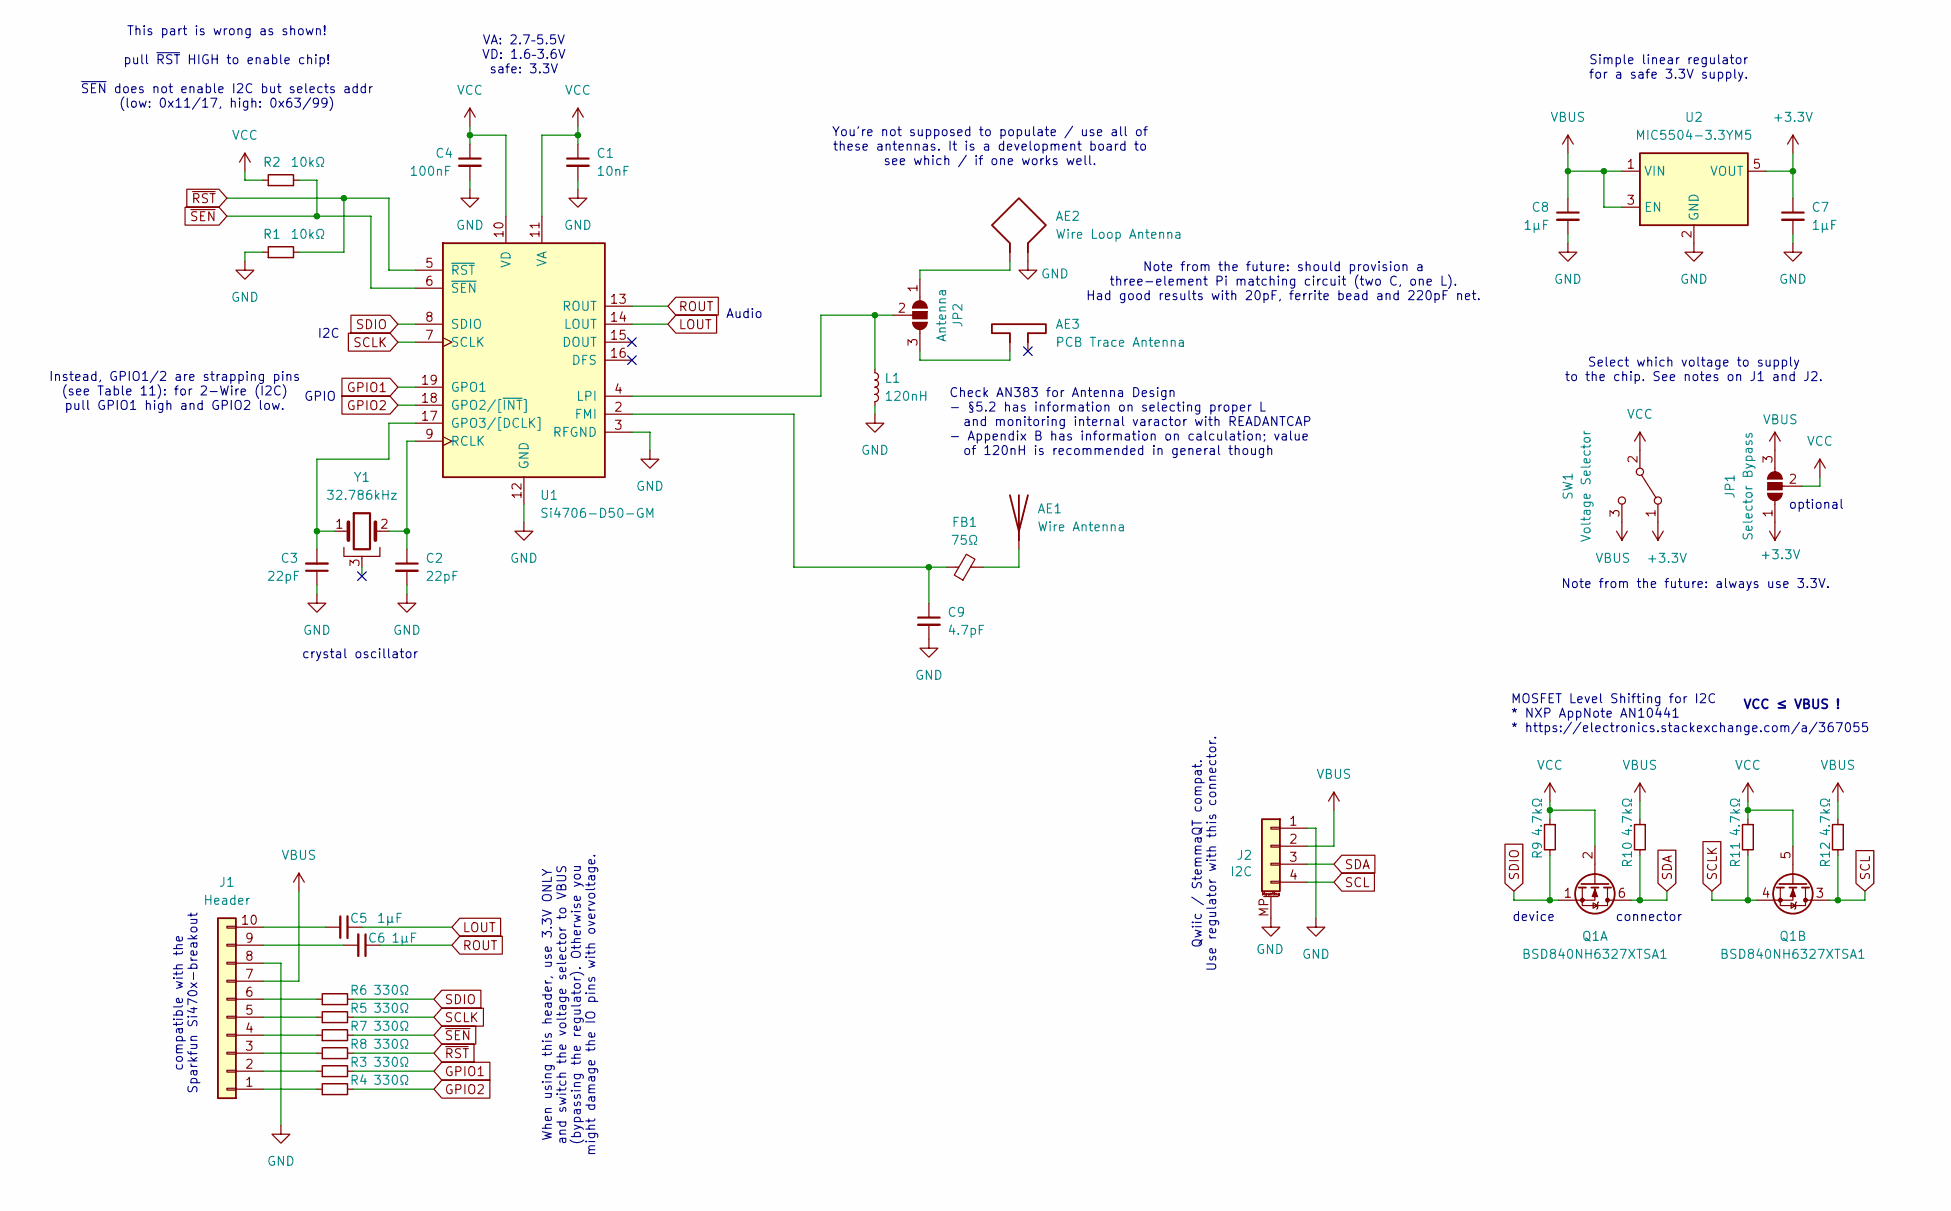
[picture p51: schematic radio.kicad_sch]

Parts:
AE1: Wire Antenna; TestPoint_Loop_D2.50mm_Drill1.0mm
AE2: Wire Loop Antenna; TestPoint_2Pads_Pitch2.54mm_Drill0.8mm
AE3: PCB Trace Antenna
C1: 10nF; C_0805_2012Metric
C2, C3: 22pF; C_0603_1608Metric
C4: 100nF; C_0805_2012Metric
C5, C6, C7, C8: 1µF; C_0805_2012Metric
C9: 4.7pF; C_0603_1608Metric
FB1: 75Ω; L_0603_1608Metric
J1: Header; PinHeader_1x10_P2.54mm_Vertical
J2: I2C; JST_SH_SM04B-SRSS-TB_1x04-1MP_P1.00mm_Horizontal
JP1: Selector Bypass; SolderJumper-3_P1.3mm_Open_RoundedPad1.0x1.5mm
JP2: Antenna; SolderJumper-3_P1.3mm_Open_RoundedPad1.0x1.5mm
L1: 120nH; L_0603_1608Metric
Q1: BSD840NH6327XTSA1; SOT-363_SC-70-6
R1, R2: 10kΩ; R_0805_2012Metric
R3, R4, R5, R6, R7, R8: 330Ω; R_0805_2012Metric
R9, R10, R11, R12: 4.7kΩ; R_0805_2012Metric
SW1: Voltage Selector; SW_SPDT_PCM12
U1: Si4706-D50-GM; SiliconLabs_QFN-20-1EP_3x3mm_P0.5mm_EP1.8x1.8mm
U2: MIC5504-3.3YM5; SOT-23-5
Y1: 32.786kHz; Crystal_SMD_MicroCrystal_MS1V-T1K

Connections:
+3.3V: C7.1, JP1.1 (A), SW1.1 (A), U2.5 (VOUT)
GND: AE2.2, C1.2, C2.2, C3.1, C4.2, C7.2, C8.2, C9.2, J1.8, J2.1, J2.MP (MountPin), L1.2, R1.1, U1.3 (RFGND), U1.12 (GND), U1.21 (GND), U2.2 (GND)
GPIO1: R3.2, U1.19 (GPO1)
GPIO2: R4.2, U1.18 (GPO2/[~INT])
LOUT: C5.2, U1.14 (LOUT)
unnamed: AE1.1 (A), FB1.2
unnamed: J1.1, R4.1
unnamed: J1.2, R3.1
unnamed: J1.3, R8.1
unnamed: J1.4, R7.1
unnamed: J1.5, R5.1
unnamed: J1.6, R6.1
unnamed: C6.2, J1.9
unnamed: C5.1, J1.10
unnamed: AE2.1, JP2.1 (A)
unnamed: AE3.1, JP2.3 (B)
unnamed: JP2.2 (C), L1.1, U1.4 (LPI)
unnamed: C9.1, FB1.1, U1.2 (FMI)
unnamed: C3.2, U1.17 (GPO3/[DCLK]), Y1.1
unnamed: C2.1, U1.9 (RCLK), Y1.2
ROUT: C6.1, U1.13 (ROUT)
SCL: J2.4, Q1.3 (D), R12.2
SCLK: Q1.4 (S), R5.2, R11.2, U1.7 (SCLK)
SDA: J2.3, Q1.6 (D), R10.2
SDIO: Q1.1 (S), R6.2, R9.2, U1.8 (SDIO)
VBUS: C8.1, J1.7, J2.2, JP1.3 (B), R10.1, R12.1, SW1.3 (C), U2.1 (VIN), U2.3 (EN)
VCC: C1.1, C4.1, JP1.2 (C), Q1.2 (G), Q1.5 (G), R2.1, R9.1, R11.1, SW1.2 (B), U1.10 (VD), U1.11 (VA)
~RST: R1.2, R8.2, U1.5 (~RST)
~SEN: R2.2, R7.2, U1.6 (~SEN)

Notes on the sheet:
Note from the future: always use 3.3V.
Simple linear regulator for a safe 3.3V supply.
crystal oscillator
Qwiic / StemmaQT compat. Use regulator with this connector.
compatible with the Sparkfun Si470x-breakout
Audio
You're not supposed to populate / use all of these antennas. It is a development board to see which / if one works well.
I2C
Select which voltage to supply to the chip. See notes on J1 and J2.
Check AN383 for Antenna Design - §5.2 has information on selecting proper L and monitoring internal varactor with READANTCAP - Appendix B has information on calculation; value of 120nH is recommended in general though
Note from the future: should provision a three-element Pi matching circuit (two C, one L). Had good results with 20pF, ferrite bead and 220pF net.
device
When using this header, use 3.3V ONLY and switch the voltage selector to VBUS (bypassing the regulator). Otherwise you might damage the IO pins with overvoltage.
This part is wrong as shown! pull ~{RST} HIGH to enable chip! ~{SEN} does not enable I2C but selects addr (low: 0x11/17, high: 0x63/99)
connector
VA: 2.7–5.5V VD: 1.6–3.6V safe: 3.3V
optional
GPIO
MOSFET Level Shifting for I2C * NXP AppNote AN10441 * https://electronics.stackexchange.com/a/367055
VCC ≤ VBUS !
Instead, GPIO1/2 are strapping pins (see Table 11): for 2-Wire (I2C) pull GPIO1 high and GPIO2 low.

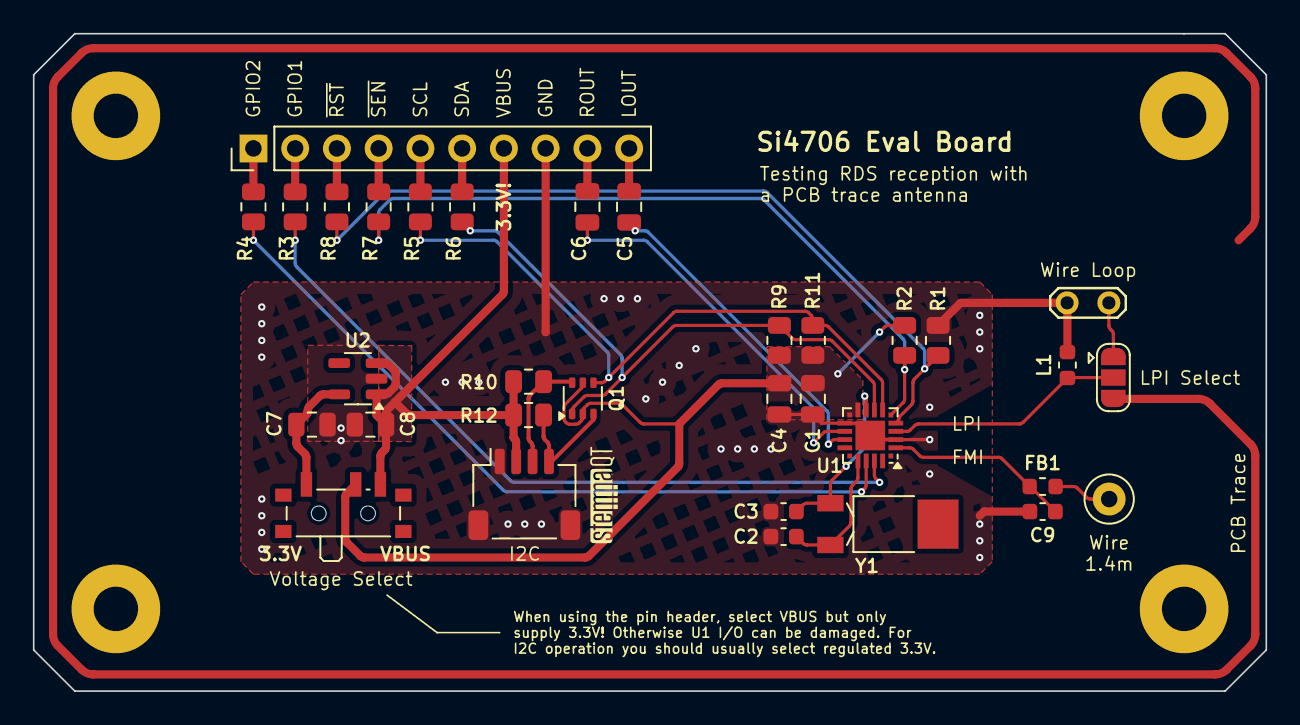
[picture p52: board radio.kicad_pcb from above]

Board: 2 copper layers, 75.0 x 40.0 mm, 33 parts (0 on the bottom side), 28 nets.

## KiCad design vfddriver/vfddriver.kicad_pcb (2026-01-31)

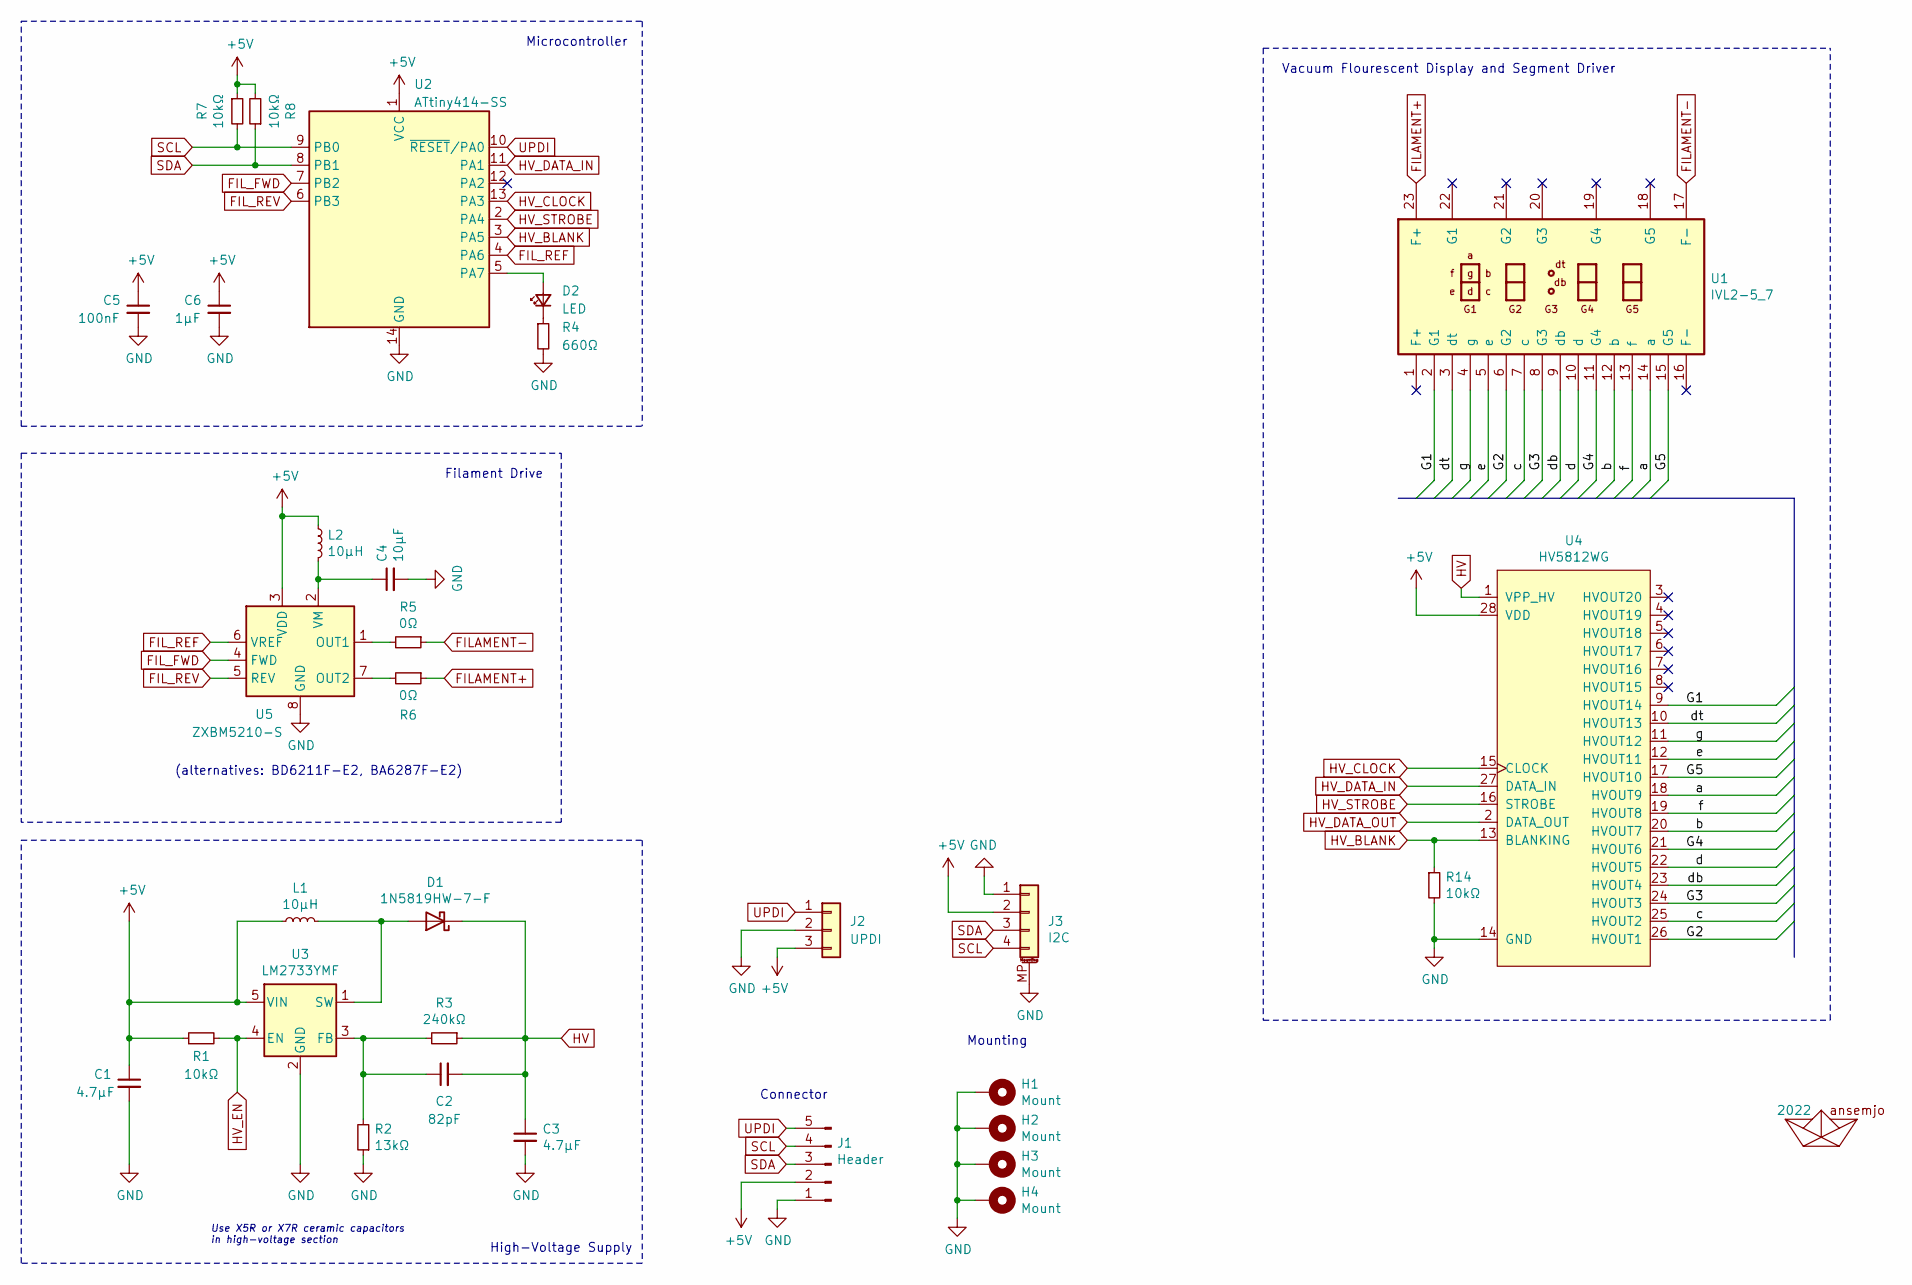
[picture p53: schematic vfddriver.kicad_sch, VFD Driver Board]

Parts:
A1: 2022; ahoi-mask
C1, C3: 4.7µF; C_0805_2012Metric_Pad1.18x1.45mm_HandSolder; MPN UMK212BBJ475KG-T; Digi-Key PN 587-5485-1-ND
C2: 82pF; C_0805_2012Metric_Pad1.18x1.45mm_HandSolder; MPN CC0805JRNPO9BN820; Digi-Key PN 311-1110-1-ND
C4: 10µF; C_0805_2012Metric_Pad1.18x1.45mm_HandSolder
C5: 100nF; C_0805_2012Metric_Pad1.18x1.45mm_HandSolder; MPN UMK212BBJ475KG-T; Digi-Key PN 587-5485-1-ND
C6: 1µF; C_0805_2012Metric_Pad1.18x1.45mm_HandSolder; MPN UMK212BBJ475KG-T; Digi-Key PN 587-5485-1-ND
D1: 1N5819HW-7-F; D_SOD-123; MPN 1N5819HW-7-F; Digi-Key PN 1N5819HW-FDICT-ND
D2: LED; LED_0805_2012Metric_Pad1.15x1.40mm_HandSolder
H1, H2, H3, H4: Mount; MountingHole_2.7mm_M2.5_Pad
J1: Header; PinHeader_1x05_P2.54mm_Vertical; MPN PREC040DBAN-M71RC; Digi-Key PN S2112EC-40-ND
J2: UPDI; UPDI_PogoProg_pinHoles
J3: I2C; JST_SH_SM04B-SRSS-TB_1x04-1MP_P1.00mm_Horizontal
L1: 10µH; L_1210_3225Metric_Pad1.42x2.65mm_HandSolder; MPN LBC3225T100MR; Digi-Key PN 587-6332-1-ND
L2: 10µH; L_1210_3225Metric_Pad1.42x2.65mm_HandSolder
R1, R14: 10kΩ; R_0805_2012Metric_Pad1.20x1.40mm_HandSolder; MPN RC0805FR-0747KL; Digi-Key PN 311-47.0KCRCT-ND
R2: 13kΩ; R_0805_2012Metric_Pad1.20x1.40mm_HandSolder; MPN RC0805FR-0713KL; Digi-Key PN 311-13.0KCRCT-ND
R3: 240kΩ; R_0805_2012Metric_Pad1.20x1.40mm_HandSolder; MPN RC0805FR-07240KL; Digi-Key PN 311-240KCRCT-ND
R4: 660Ω; R_0805_2012Metric_Pad1.20x1.40mm_HandSolder
R5, R6: 0Ω; R_1206_3216Metric_Pad1.30x1.75mm_HandSolder
R7, R8: 10kΩ; R_0805_2012Metric_Pad1.20x1.40mm_HandSolder; MPN RC0805FR-0710KL; Digi-Key PN 311-10.0KCRCT-ND
U1: IVL2-5_7; IVL2-7_5; MPN IVL2-7/5
U2: ATtiny414-SS; SOIC-14_3.9x8.7mm_P1.27mm
U3: LM2733YMF; SOT-23-5_HandSoldering; MPN LM2733YMF/NOPB; Digi-Key PN LM2733YMF/NOPBCT-ND
U4: HV5812WG; SOIC-28W_7.5x17.9mm_P1.27mm; MPN HV5812WG-G; Digi-Key PN HV5812WG-GCT-ND
U5: ZXBM5210-S; SOIC-8_3.9x4.9mm_P1.27mm

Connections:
+5V: C1.1, C5.1, C6.1, J1.2, J2.3, J3.2, L1.1, L2.1, R1.1, R7.1, R8.2, U2.1 (VCC), U3.5 (VIN), U4.28 (VDD), U5.3 (VDD)
/G1: U1.2 (G1), U4.9 (HVOUT14)
/G2: U1.6 (G2), U4.26 (HVOUT1)
/G3: U1.8 (G3), U4.24 (HVOUT3)
/G4: U1.11 (G4), U4.21 (HVOUT6)
/G5: U1.15 (G5), U4.17 (HVOUT10)
/a: U1.14 (a), U4.18 (HVOUT9)
/b: U1.12 (b), U4.20 (HVOUT7)
/c: U1.7 (c), U4.25 (HVOUT2)
/d: U1.10 (d), U4.22 (HVOUT5)
/db: U1.9 (db), U4.23 (HVOUT4)
/dt: U1.3 (dt), U4.10 (HVOUT13)
/e: U1.5 (e), U4.12 (HVOUT11)
/f: U1.13 (f), U4.19 (HVOUT8)
/g: U1.4 (g), U4.11 (HVOUT12)
FILAMENT+: R6.1, U1.23 (F+)
FILAMENT-: R5.1, U1.17 (F-)
FIL_FWD: U2.7 (PB2), U5.4 (FWD)
FIL_REF: U2.4 (PA6), U5.6 (VREF)
FIL_REV: U2.6 (PB3), U5.5 (REV)
GND: C1.2, C3.2, C4.2, C5.2, C6.2, H1.1, H2.1, H3.1, H4.1, J1.1, J2.2, J3.1, J3.MP (MountPin), R2.1, R4.2, R14.2, U2.14 (GND), U3.2 (GND), U4.14 (GND), U5.8 (GND)
HV: C2.2, C3.1, D1.1 (K), R3.1, U4.1 (VPP_HV)
HV_BLANK: R14.1, U2.3 (PA5), U4.13 (BLANKING)
HV_CLOCK: U2.13 (PA3), U4.15 (CLOCK)
HV_DATA_IN: U2.11 (PA1), U4.27 (DATA_IN)
HV_DATA_OUT: U4.2 (DATA_OUT)
HV_EN: R1.2, U3.4 (EN)
HV_STROBE: U2.2 (PA4), U4.16 (STROBE)
unnamed: C2.1, R2.2, R3.2, U3.3 (FB)
unnamed: D1.2 (A), L1.2, U3.1 (SW)
unnamed: D2.1 (K), R4.1
unnamed: R5.2, U5.1 (OUT1)
unnamed: R6.2, U5.7 (OUT2)
unnamed: D2.2 (A), U2.5 (PA7)
unnamed: C4.1, L2.2, U5.2 (VM)
SCL: J1.4, J3.4, R7.2, U2.9 (PB0)
SDA: J1.3, J3.3, R8.1, U2.8 (PB1)
UPDI: J1.5, J2.1, U2.10 (~RESET/PA0)

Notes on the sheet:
High-Voltage Supply
Connector
Filament Drive
(alternatives: BD6211F-E2, BA6287F-E2)
Use X5R or X7R ceramic capacitors in high-voltage section
Mounting
Microcontroller
Vacuum Flourescent Display and Segment Driver

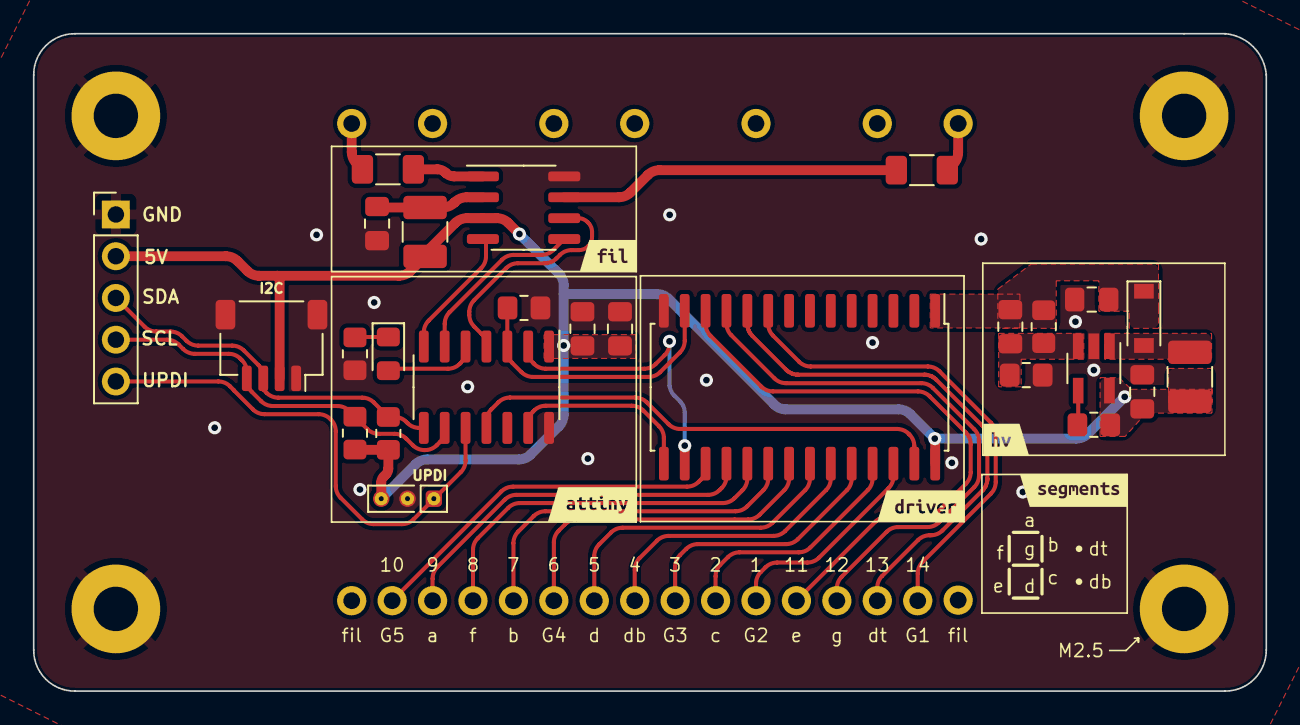
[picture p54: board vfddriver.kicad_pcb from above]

Board: 2 copper layers, 75.0 x 40.0 mm, 37 parts (1 on the bottom side), 37 nets.

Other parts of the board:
kibuzzard-61E36C9E: G***; kibuzzard-61E36C9E
kibuzzard-61E36C30: G***; kibuzzard-61E36C30
kibuzzard-61E3696A: G***; kibuzzard-61E3696A
kibuzzard-61E3771A: G***; kibuzzard-61E3771A
kibuzzard-61E36996: G***; kibuzzard-61E36996

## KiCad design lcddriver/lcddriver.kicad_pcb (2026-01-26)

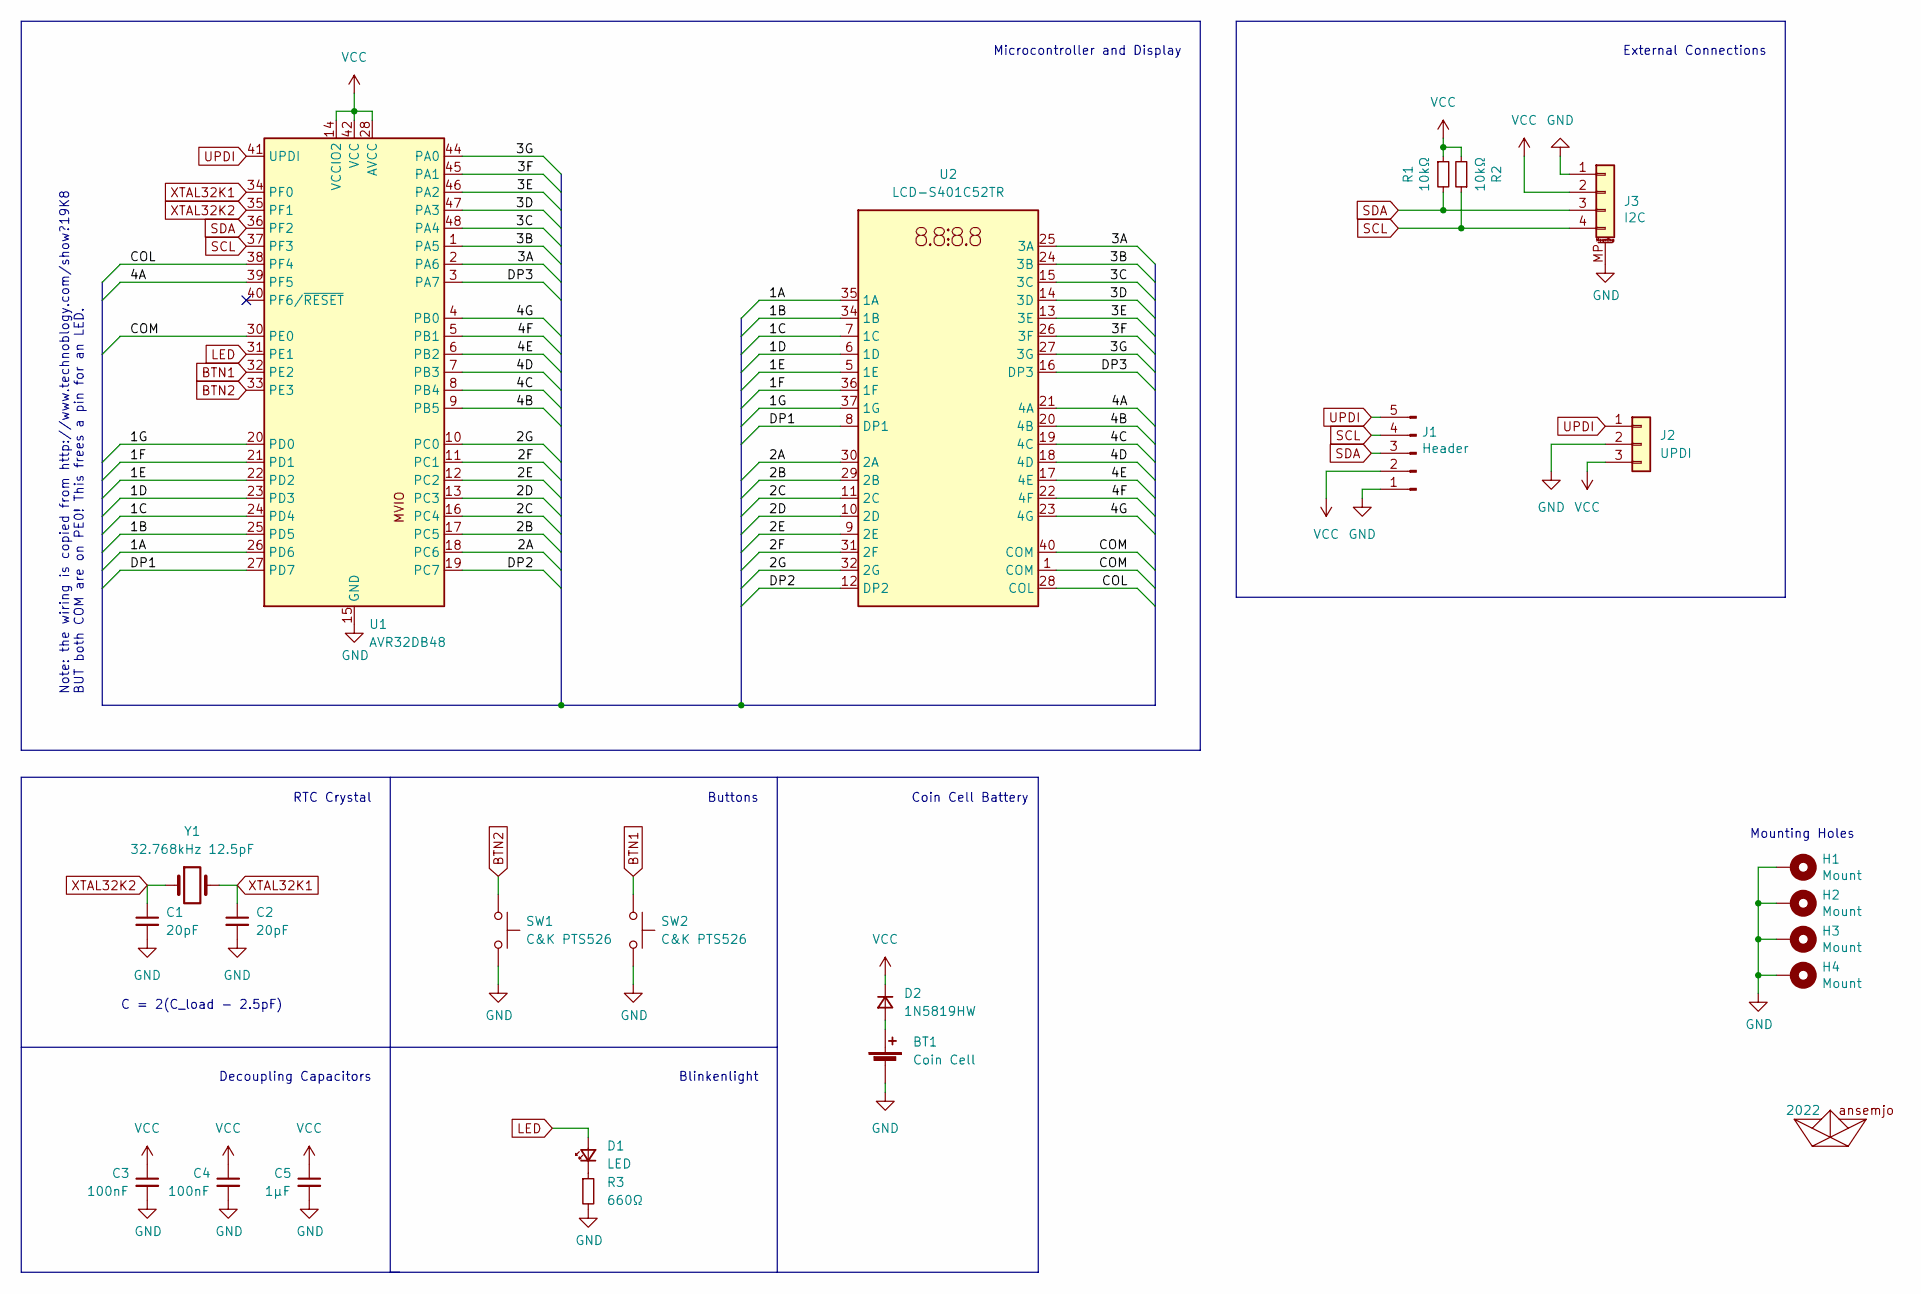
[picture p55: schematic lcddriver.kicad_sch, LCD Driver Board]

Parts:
A1: 2022; ahoi
BT1: Coin Cell; BatteryHolder_Keystone_3034_1x20mm
C1, C2: 20pF; C_0603_1608Metric_Pad1.08x0.95mm_HandSolder
C3, C4: 100nF; C_0805_2012Metric_Pad1.18x1.45mm_HandSolder; MPN UMK212BBJ475KG-T; Digi-Key PN 587-5485-1-ND
C5: 1µF; C_0805_2012Metric_Pad1.18x1.45mm_HandSolder; MPN UMK212BBJ475KG-T; Digi-Key PN 587-5485-1-ND
D1: LED; LED_0805_2012Metric_Pad1.15x1.40mm_HandSolder
D2: 1N5819HW; D_SOD-123
H1, H2, H3, H4: Mount; MountingHole_2.7mm_M2.5_Pad
J1: Header; PinHeader_1x05_P2.54mm_Vertical; MPN PREC040DBAN-M71RC; Digi-Key PN S2112EC-40-ND
J2: UPDI; UPDI_PogoProg
J3: I2C; JST_SH_SM04B-SRSS-TB_1x04-1MP_P1.00mm_Horizontal
R1, R2: 10kΩ; R_0805_2012Metric_Pad1.20x1.40mm_HandSolder; MPN RC0805FR-0710KL; Digi-Key PN 311-10.0KCRCT-ND
R3: 660Ω; R_0805_2012Metric_Pad1.20x1.40mm_HandSolder
SW1, SW2: C&K PTS526; SW_PTS526_SM08_SMTR2_LFS
U1: AVR32DB48; TQFP-48_7x7mm_P0.5mm
U2: LCD-S401C52TR; DE119-XX-XX
Y1: 32.768kHz 12.5pF; Crystal_SMD_3215-2Pin_3.2x1.5mm

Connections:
/1A: U1.26 (PD6), U2.35 (1A)
/1B: U1.25 (PD5), U2.34 (1B)
/1C: U1.24 (PD4), U2.7 (1C)
/1D: U1.23 (PD3), U2.6 (1D)
/1E: U1.22 (PD2), U2.5 (1E)
/1F: U1.21 (PD1), U2.36 (1F)
/1G: U1.20 (PD0), U2.37 (1G)
/2A: U1.18 (PC6), U2.30 (2A)
/2B: U1.17 (PC5), U2.29 (2B)
/2C: U1.16 (PC4), U2.11 (2C)
/2D: U1.13 (PC3), U2.10 (2D)
/2E: U1.12 (PC2), U2.9 (2E)
/2F: U1.11 (PC1), U2.31 (2F)
/2G: U1.10 (PC0), U2.32 (2G)
/3A: U1.2 (PA6), U2.25 (3A)
/3B: U1.1 (PA5), U2.24 (3B)
/3C: U1.48 (PA4), U2.15 (3C)
/3D: U1.47 (PA3), U2.14 (3D)
/3E: U1.46 (PA2), U2.13 (3E)
/3F: U1.45 (PA1), U2.26 (3F)
/3G: U1.44 (PA0), U2.27 (3G)
/4A: U1.39 (PF5), U2.21 (4A)
/4B: U1.9 (PB5), U2.20 (4B)
/4C: U1.8 (PB4), U2.19 (4C)
/4D: U1.7 (PB3), U2.18 (4D)
/4E: U1.6 (PB2), U2.17 (4E)
/4F: U1.5 (PB1), U2.22 (4F)
/4G: U1.4 (PB0), U2.23 (4G)
/COL: U1.38 (PF4), U2.28 (COL)
/COM: U1.30 (PE0), U2.1 (COM), U2.40 (COM)
/DP1: U1.27 (PD7), U2.8 (DP1)
/DP2: U1.19 (PC7), U2.12 (DP2)
/DP3: U1.3 (PA7), U2.16 (DP3)
BTN1: SW2.1, U1.32 (PE2)
BTN2: SW1.1, U1.33 (PE3)
GND: BT1.2 (-), C1.2, C2.2, C3.2, C4.2, C5.2, H1.1, H2.1, H3.1, H4.1, J1.1, J2.2, J3.1, J3.MP (MountPin), R3.2, SW1.2, SW2.2, U1.15 (GND), U1.29 (GND), U1.43 (GND)
LED: D1.2 (A), U1.31 (PE1)
unnamed: BT1.1 (+), D2.2 (A)
unnamed: D1.1 (K), R3.1
SCL: J1.4, J3.4, R2.1, U1.37 (PF3)
SDA: J1.3, J3.3, R1.2, U1.36 (PF2)
UPDI: J1.5, J2.1, U1.41 (UPDI)
XTAL32K1: C2.1, U1.34 (PF0), Y1.2
XTAL32K2: C1.1, U1.35 (PF1), Y1.1

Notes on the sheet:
Decoupling Capacitors
Buttons
RTC Crystal
C = 2(C_load - 2.5pF)
Blinkenlight
Coin Cell Battery
Note: the wiring is copied from http://www.technoblogy.com/show?19K8 BUT both COM are on PE0! This frees a pin for an LED.
Microcontroller and Display
Mounting Holes
External Connections

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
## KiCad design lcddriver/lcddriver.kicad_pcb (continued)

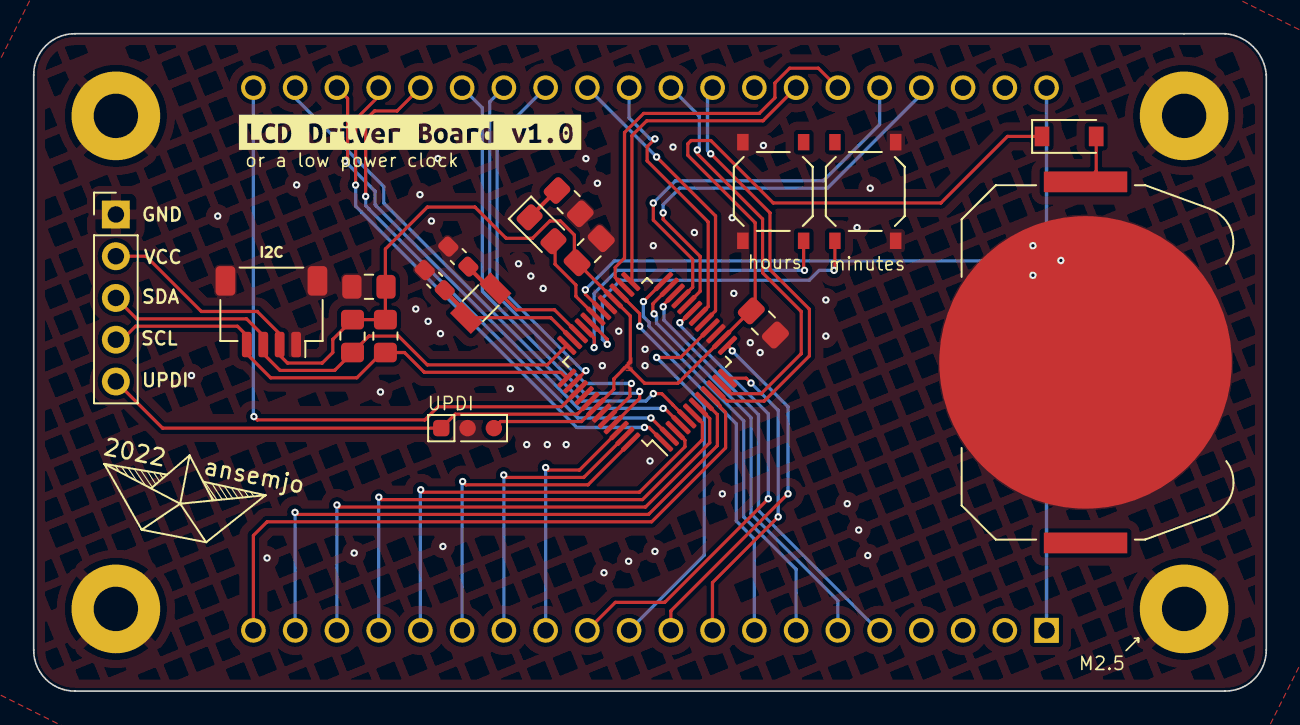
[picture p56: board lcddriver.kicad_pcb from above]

Board: 2 copper layers, 75.0 x 40.0 mm, 25 parts (1 on the bottom side), 45 nets.

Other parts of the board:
kibuzzard-6311A385: G***; kibuzzard-6311A385

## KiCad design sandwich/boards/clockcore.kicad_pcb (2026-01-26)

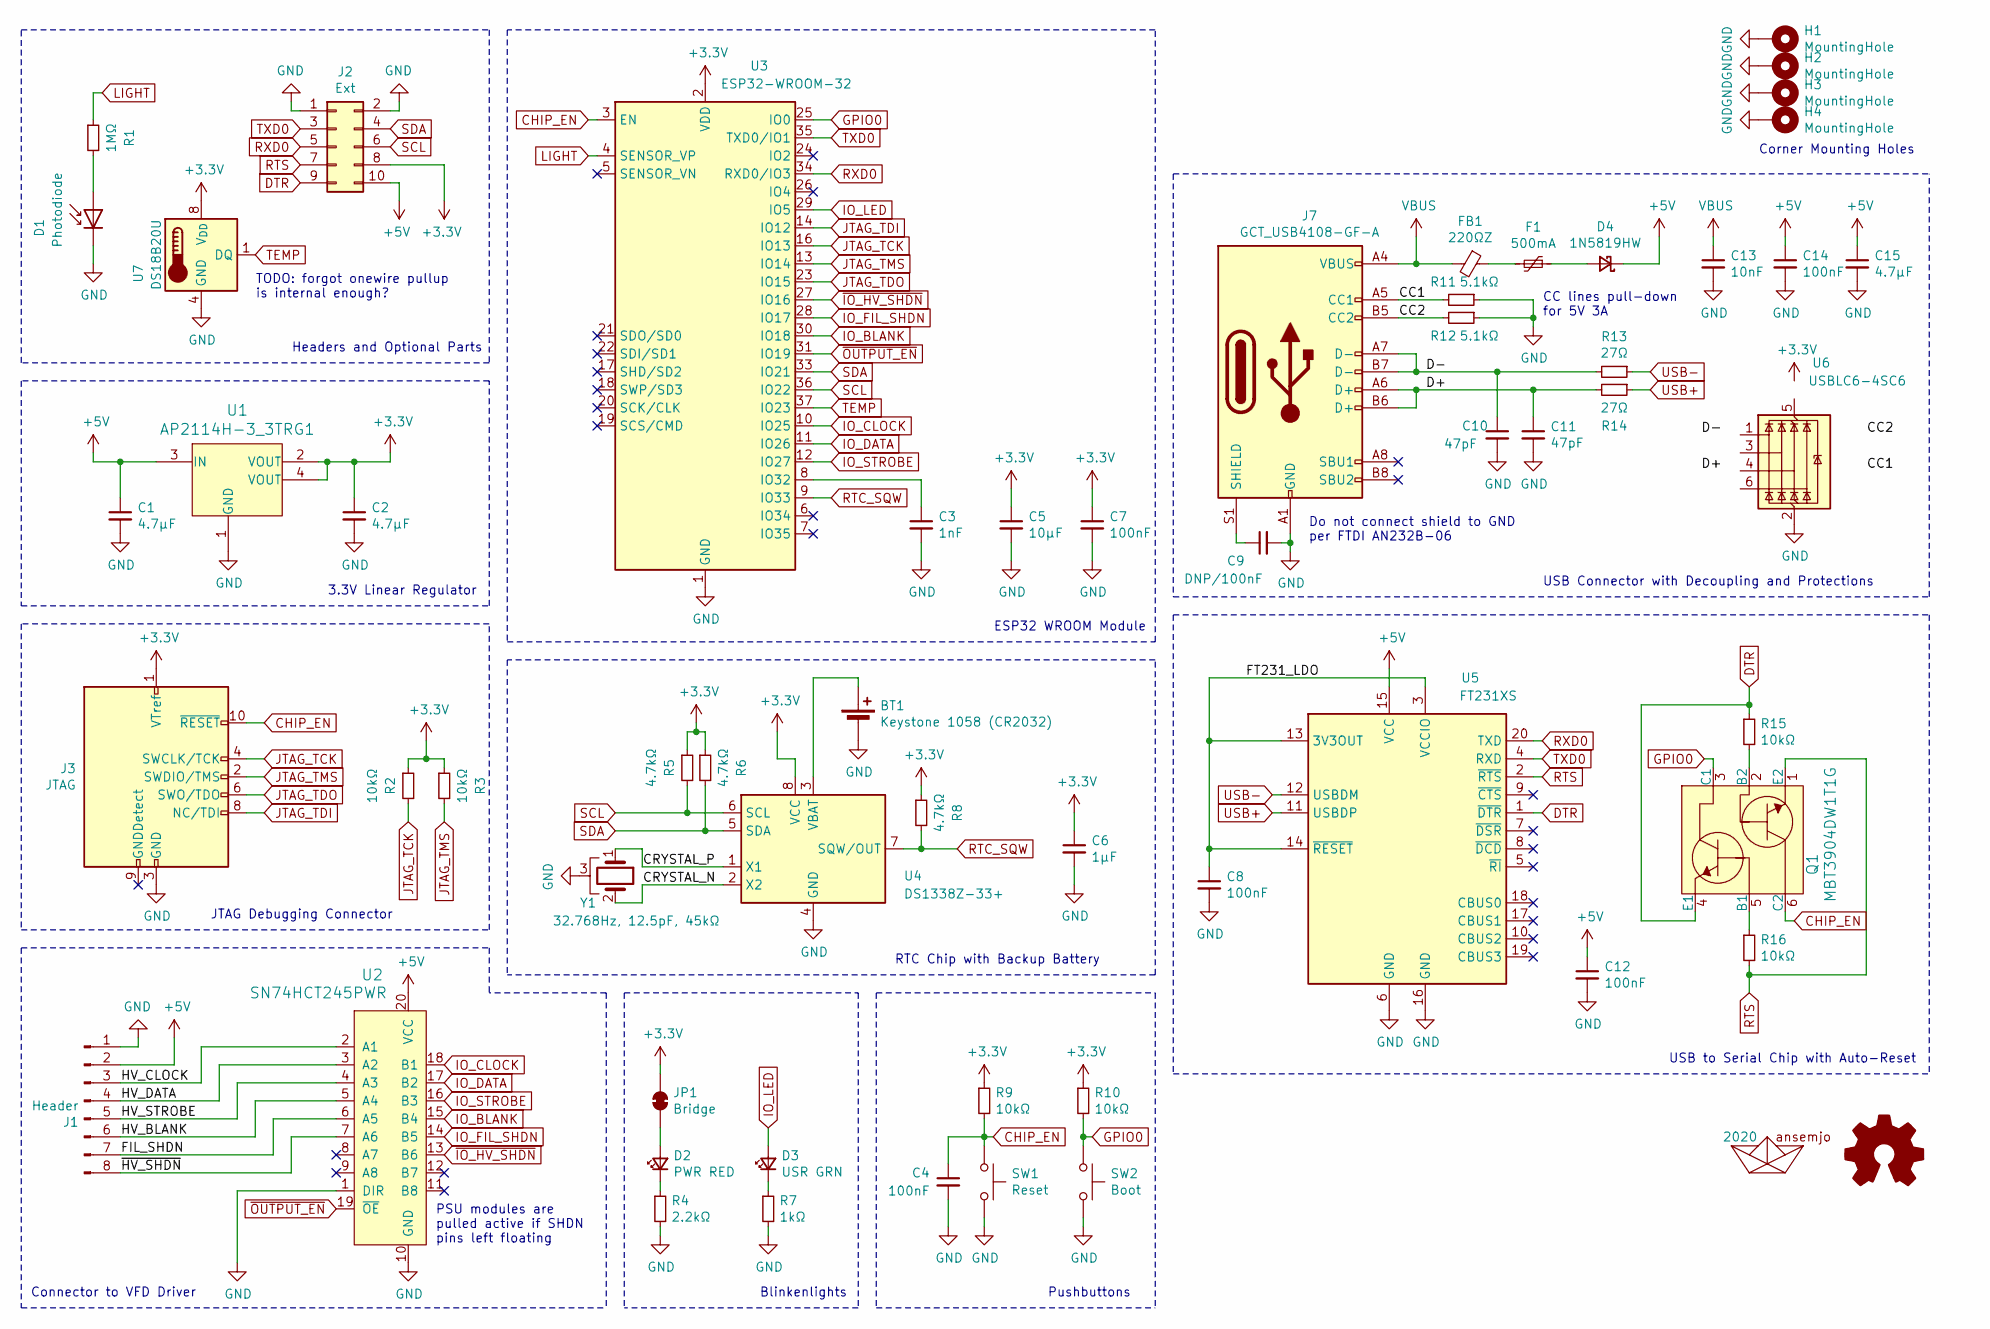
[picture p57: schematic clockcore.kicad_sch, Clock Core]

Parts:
A1: 2020; AHOI
A2: Logo_Open_Hardware_Small; OSHW-Symbol_6.7x6mm_SilkScreen
BT1: Keystone 1058 (CR2032); BatteryHolder_Keystone_1058_1x2032; MPN 1058; Digi-Key_PN 36-1058-ND
C1, C2, C15: 4.7µF; C_0805_2012Metric_Pad1.15x1.40mm_HandSolder; MPN CL21A475KAQNNNE; Digi-Key_PN 1276-1244-1-ND
C3: 1nF; C_0805_2012Metric_Pad1.15x1.40mm_HandSolder; MPN CL21B102KBANNNC; Digi-Key_PN 1276-1020-1-ND
C4, C7, C8, C12, C14: 100nF; C_0805_2012Metric_Pad1.15x1.40mm_HandSolder; MPN CL21B104KACNNNC; Digi-Key_PN 1276-1099-1-ND
C5: 10µF; C_0805_2012Metric_Pad1.15x1.40mm_HandSolder; MPN CL21A106KOQNNNE; Digi-Key_PN 1276-1096-1-ND
C6: 1µF; C_0805_2012Metric_Pad1.15x1.40mm_HandSolder; MPN CL21B105KAFNNNG; Digi-Key_PN 1276-6469-1-ND
C9: DNP/100nF; C_0805_2012Metric_Pad1.15x1.40mm_HandSolder; MPN CL21B104KACNNNC; Digi-Key_PN 1276-1099-1-ND
C10, C11: 47pF; C_0805_2012Metric_Pad1.15x1.40mm_HandSolder; MPN CC0805JRNPO9BN470; Digi-Key_PN 311-1107-1-ND
C13: 10nF; C_0805_2012Metric_Pad1.15x1.40mm_HandSolder; MPN CC0805KRX7R9BB103; Digi-Key_PN 311-1136-1-ND
D1: Photodiode; D_1206_3216Metric_Castellated; MPN VEMD1060X01; Digi-Key_PN VEMD1060X01CT-ND
D2: PWR RED; LED_0805_2012Metric_Pad1.15x1.40mm_HandSolder; MPN 150080SS75000; Digi-Key_PN 732-4985-1-ND
D3: USR GRN; LED_0805_2012Metric_Pad1.15x1.40mm_HandSolder; MPN 150080VS75000; Digi-Key_PN 732-4986-1-ND
D4: 1N5819HW; D_SOD-123; MPN 1N5819HW-7-F; Digi-Key_PN 1N5819HW-FDICT-ND
F1: 500mA; Fuse_1206_3216Metric_Pad1.42x1.75mm_HandSolder; MPN 0ZCJ0050FF2G; Digi-Key_PN 507-1802-1-ND
FB1: 220ΩZ; L_0805_2012Metric_Pad1.15x1.40mm_HandSolder; MPN BLM21PG221SZ1D; Digi-Key_PN 490-16661-1-ND
H1, H2, H3, H4: MountingHole; MountingHole_2.7mm_M2.5_Pad
J1: Header; PinSocket_1x08_P2.54mm_Vertical; MPN PPTC081LFBN-RC; Digi-Key_PN S7006-ND
J2: Ext; PinHeader_2x05_P2.54mm_Vertical; MPN PRPC040DAAN-RC; Digi-Key_PN S2011EC-40-ND
J3: JTAG; JTAG_2x05_P1.27mm_Vertical_SMD; MPN 20021121-00010C4LF; Digi-Key_PN 609-3695-6-ND
J7: GCT_USB4108-GF-A; USB_C_Receptacle_HRO_TYPE-C-31-M-12; MPN USB4105-GF-A; Digi-Key_PN 2073-USB4105-GF-ACT-ND
JP1: Bridge; SolderJumper-2_P1.3mm_Bridged_RoundedPad1.0x1.5mm
Q1: MBT3904DW1T1G; SOT-363; MPN MBT3904DW1T1G; Digi-Key_PN MBT3904DW1T1GOSCT-ND
R1: 1MΩ; R_0805_2012Metric_Pad1.15x1.40mm_HandSolder; MPN RC0805FR-071ML; Digi-Key_PN 311-1.00MCRCT-ND
R2, R3, R9, R10, R15, R16: 10kΩ; R_0805_2012Metric_Pad1.15x1.40mm_HandSolder; MPN RC0805FR-0710KL; Digi-Key_PN 311-10.0KCRCT-ND
R4: 2.2kΩ; R_0805_2012Metric_Pad1.15x1.40mm_HandSolder; MPN RC0805FR-072K2L; Digi-Key_PN 311-2.20KCRCT-ND
R5, R6, R8: 4.7kΩ; R_0805_2012Metric_Pad1.15x1.40mm_HandSolder; MPN RC0805FR-074K7L; Digi-Key_PN 311-4.70KCRCT-ND
R7: 1kΩ; R_0805_2012Metric_Pad1.15x1.40mm_HandSolder; MPN RC0805FR-071KL; Digi-Key_PN 311-1.00KCRCT-ND
R11, R12: 5.1kΩ; R_0805_2012Metric_Pad1.15x1.40mm_HandSolder; MPN RC0805JR-075K1L; Digi-Key_PN 311-5.1KARCT-ND
R13, R14: 27Ω; R_0805_2012Metric_Pad1.15x1.40mm_HandSolder; MPN RC0805FR-0727RL; Digi-Key_PN 311-27.0CRCT-ND
SW1: Reset; SW_PTS526_SM08_SMTR2_LFS; MPN PTS526 SK15 SMTR2 LFS; Digi-Key_PN CKN12221-1-ND
SW2: Boot; SW_PTS526_SM08_SMTR2_LFS; MPN PTS526 SK15 SMTR2 LFS; Digi-Key_PN CKN12221-1-ND
U1: AP2114H-3_3TRG1; SOT-223; MPN AP2114H-3.3TRG1; Digi-Key_PN AP2114H-3.3TRG1DICT-ND
U2: ‎SN74HCT245PWR‎; TSSOP-20_4.4x6.5mm_P0.65mm; MPN SN74HCT245PWR; Digi-Key_PN 296-8404-1-ND
U3: ESP32-WROOM-32; MPN ESP32-WROOM-32E (8MB); Digi-Key_PN 1965-ESP32-WROOM-32E(8MBFLASH)CT-ND
U4: DS1338Z-33+; SOIC-8_3.9x4.9mm_P1.27mm; MPN DS1338Z-33+T&R; Digi-Key_PN DS1338Z-33+T&RCT-ND
U5: FT231XS; SSOP-20_3.9x8.7mm_P0.635mm; MPN FT231XS-R; Digi-Key_PN 768-1129-1-ND
U6: USBLC6-4SC6; SOT-23-6; MPN USBLC6-4SC6; Digi-Key_PN 497-4492-1-ND
U7: DS18B20U; MSOP-8_3x3mm_P0.65mm; MPN DS18B20U+T&R; Digi-Key_PN DS18B20U+T&RCT-ND
Y1: 32.768Hz, 12.5pF, 45kΩ; Crystal_SMD_MicroCrystal_MS1V-T1K; MPN ECS-.327-12.5-13FLX-C; Digi-Key_PN XC1911CT-ND

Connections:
+3V3: C2.1, C5.1, C6.1, C7.1, J2.8, J3.1 (VTref), JP1.1 (A), R2.1, R3.1, R5.1, R6.1, R8.1, R9.1, R10.1, U1.2 (VOUT), U1.4 (VOUT), U3.2 (VDD), U4.8 (VCC), U6.5 (VBUS), U7.8 (V_{DD})
+5V: C1.1, C12.1, C14.1, C15.1, D4.1 (K), J1.2, J2.10, U1.3 (IN), U2.20 (VCC), U5.15 (VCC)
/CC1: J7.A5 (CC1), R11.2, U6.6 (I/O4)
/CC2: J7.B5 (CC2), R12.2, U6.4 (I/O3)
/CRYSTAL_N: U4.2 (X2), Y1.2
/CRYSTAL_P: U4.1 (X1), Y1.1
/D+: C11.1, J7.A6 (D+), J7.B6 (D+), R14.2, U6.3 (I/O2)
/D-: C10.1, J7.A7 (D-), J7.B7 (D-), R13.2, U6.1 (I/O1)
/FIL_SHDN: J1.7, U2.6 (A5)
/FT231_LDO: C8.1, U5.3 (VCCIO), U5.13 (3V3OUT), U5.14 (~RESET)
/HV_BLANK: J1.6, U2.5 (A4)
/HV_CLOCK: J1.3, U2.2 (A1)
/HV_DATA: J1.4, U2.3 (A2)
/HV_STROBE: J1.5, U2.4 (A3)
/~HV_SHDN: J1.8, U2.7 (A6)
CHIP_EN: C4.1, J3.10 (~RESET), Q1.6 (C2), R9.2, SW1.1, U3.3 (EN)
DTR: J2.9, Q1.4 (E1), R15.1, U5.1 (~DTR)
GND: BT1.2 (-), C1.2, C2.2, C3.2, C4.2, C5.2, C6.2, C7.2, C8.2, C9.2, C10.2, C11.2, C12.2, C13.2, C14.2, C15.2, D1.1 (K), H1.1, H2.1, H3.1, H4.1, J1.1, J2.1, J2.2, J3.3 (GND), J3.5 (GND), J7.A1 (GND), J7.A12 (GND), J7.B1 (GND), J7.B12 (GND), R4.2, R7.2, R11.1, R12.1, SW1.2, SW2.2, U1.1 (GND), U2.1 (DIR), U2.10 (GND), U3.1 (GND), U3.15 (GND), U3.38 (GND), U3.39 (GND), U4.4 (GND), U5.6 (GND), U5.16 (GND), U6.2 (GND), U7.4 (GND), Y1.3
GPIO0: Q1.3 (C1), R10.2, SW2.1, U3.25 (IO0)
IO_BLANK: U2.15 (B4), U3.30 (IO18)
IO_CLOCK: U2.18 (B1), U3.10 (IO25)
IO_DATA: U2.17 (B2), U3.11 (IO26)
IO_FIL_SHDN: U2.14 (B5), U3.28 (IO17)
IO_LED: D3.2 (A), U3.29 (IO5)
IO_STROBE: U2.16 (B3), U3.12 (IO27)
JTAG_TCK: J3.4 (SWCLK/TCK), R2.2, U3.16 (IO13)
JTAG_TDI: J3.8 (NC/TDI), U3.14 (IO12)
JTAG_TDO: J3.6 (SWO/TDO), U3.23 (IO15)
JTAG_TMS: J3.2 (SWDIO/TMS), R3.2, U3.13 (IO14)
LIGHT: R1.1, U3.4 (SENSOR_VP)
unnamed: BT1.1 (+), U4.3 (VBAT)
unnamed: C3.1, U3.8 (IO32)
unnamed: C9.1, J7.S1 (SHIELD)
unnamed: D1.2 (A), R1.2
unnamed: D2.1 (K), R4.1
unnamed: D2.2 (A), JP1.2 (B)
unnamed: D3.1 (K), R7.1
unnamed: D4.2 (A), F1.1
unnamed: F1.2, FB1.1
unnamed: Q1.2 (B2), R15.2
unnamed: Q1.5 (B1), R16.1
RTC_SQW: R8.2, U3.9 (IO33), U4.7 (SQW/OUT)
RTS: J2.7, Q1.1 (E2), R16.2, U5.2 (~RTS)
RXD0: J2.5, U3.34 (RXD0/IO3), U5.20 (TXD)
SCL: J2.6, R5.2, U3.36 (IO22), U4.6 (SCL)
SDA: J2.4, R6.2, U3.33 (IO21), U4.5 (SDA)
TEMP: U3.37 (IO23), U7.1 (DQ)
TXD0: J2.3, U3.35 (TXD0/IO1), U5.4 (RXD)
USB+: R14.1, U5.11 (USBDP)
USB-: R13.1, U5.12 (USBDM)
VBUS: C13.1, FB1.2, J7.A4 (VBUS), J7.A9 (VBUS), J7.B4 (VBUS), J7.B9 (VBUS)
~IO_HV_SHDN: U2.13 (B6), U3.27 (IO16)
~OUTPUT_EN: U2.19 (~OE), U3.31 (IO19)

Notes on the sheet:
Blinkenlights
TODO: forgot onewire pullup is internal enough?
Pushbuttons
Do not connect shield to GND per FTDI AN232B-06
Corner Mounting Holes
USB to Serial Chip with Auto-Reset
PSU modules are pulled active if SHDN pins left floating
USB Connector with Decoupling and Protections
Connector to VFD Driver
ESP32 WROOM Module
RTC Chip with Backup Battery
JTAG Debugging Connector
Headers and Optional Parts
3.3V Linear Regulator
CC lines pull-down for 5V 3A

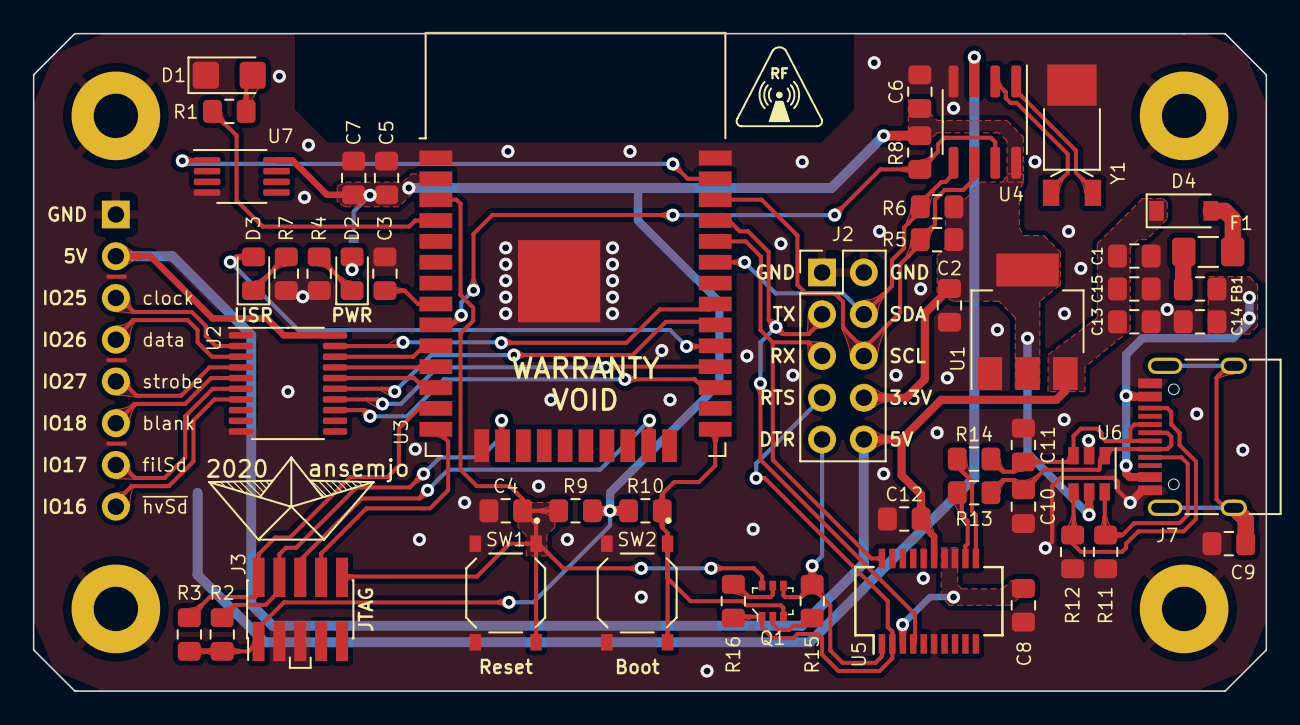
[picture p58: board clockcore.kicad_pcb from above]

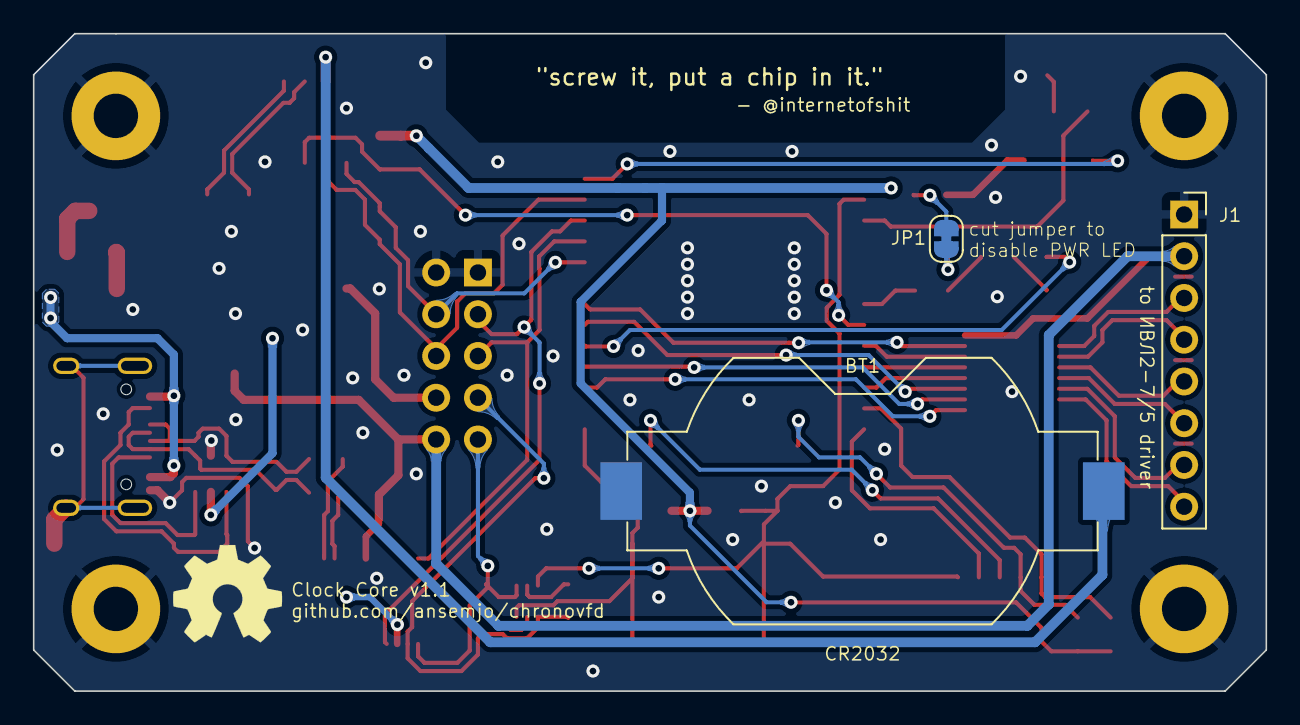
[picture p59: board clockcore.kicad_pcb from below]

Board: 2 copper layers, 75.0 x 40.0 mm, 60 parts (4 on the bottom side), 53 nets.

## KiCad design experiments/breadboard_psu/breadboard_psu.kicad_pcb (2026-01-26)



Board: 2 copper layers, 51.7 x 33.0 mm, 40 parts (5 on the bottom side), 24 nets.

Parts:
A1: 2021; ahoi
C1, C2: 4.7µF; C_0805_2012Metric_Pad1.18x1.45mm_HandSolder
C3: 82pF; C_0805_2012Metric_Pad1.18x1.45mm_HandSolder
C4: 47µF; CP_Elec_6.3x5.9
C11: 10nF; C_0805_2012Metric_Pad1.18x1.45mm_HandSolder
C12: 10µF; C_0805_2012Metric_Pad1.18x1.45mm_HandSolder
D1: 1N5819HW-7-F; D_SOD-123
J1: USB_B_Micro; USB_Micro-B_Amphenol_10118194_Horizontal
J2: PWR Header; PinHeader_2x02_P2.54mm_Vertical
J3: HV Jumper; PinHeader_2x03_P2.54mm_Vertical
J4: Filament Jumper; PinHeader_2x02_P2.54mm_Vertical
J5: Filament EN; PinHeader_2x01_P2.54mm_Vertical
J6: HV EN; PinHeader_2x01_P2.54mm_Vertical
J21, J22: Breadboard Rail; PinHeader_1x02_P2.54mm_Vertical
J31, J32: Breadboard NC; PinHeader_1x02_P2.54mm_Vertical
L1, L2: 10µH; L_1210_3225Metric_Pad1.42x2.65mm_HandSolder
R1: 47kΩ; R_0805_2012Metric_Pad1.20x1.40mm_HandSolder
R2: 13kΩ; R_0805_2012Metric_Pad1.20x1.40mm_HandSolder
R3: 240kΩ; R_0805_2012Metric_Pad1.20x1.40mm_HandSolder
R14, R15: 10kΩ; R_0805_2012Metric_Pad1.20x1.40mm_HandSolder
R16, R17: 10Ω; R_1206_3216Metric_Pad1.30x1.75mm_HandSolder
RV1: Trimmer; Potentiometer_Bourns_3266W_Vertical
RV4: 10kΩ; Potentiometer_Bourns_3266W_Vertical
TP1: 5V; TestPoint_THTPad_D1.5mm_Drill0.7mm
TP2: hv; TestPoint_THTPad_D1.5mm_Drill0.7mm
TP3: freq; TestPoint_THTPad_D1.5mm_Drill0.7mm
TP4: GND; TestPoint_THTPad_D1.5mm_Drill0.7mm
TP11: fB; TestPoint_THTPad_D1.5mm_Drill0.7mm
TP12: fA; TestPoint_THTPad_D1.5mm_Drill0.7mm
U1: 74LS132; SOIC-14_3.9x8.7mm_P1.27mm
U3: LM2733YMF; SOT-23-5
U4: ZXBM5210-S; SOIC-8_3.9x4.9mm_P1.27mm
VFD1: IVL2-5_7; IVL2-7_5-singleSide
kibuzzard-61E14426: G***; kibuzzard-61E14426

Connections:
/5V: C1.1, C4.1, J1.1 (VBUS), J2.1, J2.2, J5.2, J6.2, J21.2, J22.2, L1.1, L2.1, RV1.1, TP1.1, U1.14 (VCC), U3.5 (VIN), U4.3 (VDD)
/FIL_A: J4.3, TP12.1, VFD1.1 (F+)
/FIL_B: J4.1, TP11.1, VFD1.16 (F-)
/FIL_H_A: J4.4, R16.1
/FIL_H_B: J4.2, R17.1
/HV: C2.1, C3.2, D1.1 (K), J3.1, RV4.1
/HV_Grids: J3.3, VFD1.2 (G1), VFD1.6 (G2), VFD1.8 (G3), VFD1.11 (G4), VFD1.15 (G5)
/HV_Jumper: J3.2, J3.4, J3.6, TP2.1
/HV_Segments: J3.5, VFD1.3 (dt), VFD1.4 (g), VFD1.5 (e), VFD1.7 (c), VFD1.9 (db), VFD1.10 (d), VFD1.12 (b), VFD1.13 (f), VFD1.14 (a)
/H_EN: J5.1, R14.1, U1.1, U1.13
GND: C1.2, C2.2, C4.2, C11.2, C12.1, J1.5 (GND), J1.6 (Shield), J2.3, J2.4, J21.1, J22.1, J31.1, J32.1, R1.2, R2.1, R14.2, RV1.3, TP4.1, U1.7 (GND), U3.2 (GND), U4.8 (GND)
unnamed: C3.1, R2.2, R3.2, U3.3 (FB)
unnamed: C11.1, R15.1, TP3.1, U1.2
unnamed: C12.2, L2.2, U4.2 (VM)
unnamed: D1.2 (A), L1.2, U3.1 (SW)
unnamed: J6.1, R1.1, U3.4 (EN)
unnamed: R3.1, RV4.2
unnamed: R15.2, U1.3, U1.4, U1.5, U1.12
unnamed: R16.2, U4.1 (OUT1)
unnamed: R17.2, U4.7 (OUT2)
unnamed: RV1.2, U4.6 (VREF)
unnamed: U1.6, U4.5 (REV)
unnamed: U1.8, U4.4 (FWD)
unnamed: U1.9, U1.10, U1.11

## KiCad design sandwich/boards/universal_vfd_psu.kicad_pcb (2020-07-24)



Board: 2 copper layers, 53.0 x 30.5 mm, 32 parts (2 on the bottom side), 18 nets.

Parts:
C1: 2.2µF; C_0805_2012Metric_Pad1.15x1.40mm_HandSolder
C2: 4.7µF; C_0805_2012Metric_Pad1.15x1.40mm_HandSolder
C3: 82pF; C_0805_2012Metric_Pad1.15x1.40mm_HandSolder
C4: 10nF; C_0805_2012Metric_Pad1.15x1.40mm_HandSolder
C5, C10: 1µF; C_0805_2012Metric_Pad1.15x1.40mm_HandSolder
C6: 10µF; CP_Elec_4x5.4
C7, C8: 47µF; CP_Elec_6.3x5.9
C9: 100nF; C_0805_2012Metric_Pad1.15x1.40mm_HandSolder
D1: 1N5819HW-7-F; D_SOD-123
D2: 3.3V; D_SOD-123
FILAMENT: PinHeader_1x02_P2.54mm_Vertical
GND: SolderJumper-2_P1.3mm_Bridged2Bar_RoundedPad1.0x1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; SolderJumper-2_P1.3mm_Bridged2Bar_RoundedPad1.0x1.5mm
HV: PinHeader_1x02_P2.54mm_Vertical
L1: 10µH; L_1210_3225Metric_Pad1.42x2.65mm_HandSolder
R1: 47kΩ; R_0805_2012Metric_Pad1.15x1.40mm_HandSolder
R2: 13kΩ; R_0805_2012Metric_Pad1.15x1.40mm_HandSolder
R3: 240kΩ; R_0805_2012Metric_Pad1.15x1.40mm_HandSolder
R4, R5, R6, R7, R9: 10kΩ; R_0805_2012Metric_Pad1.15x1.40mm_HandSolder
R8: 2.2kΩ; R_0805_2012Metric_Pad1.15x1.40mm_HandSolder
R10, R11: 10Ω; R_1206_3216Metric_Pad1.42x1.75mm_HandSolder
R12, R13: 220Ω; R_0805_2012Metric_Pad1.15x1.40mm_HandSolder
U2: LM4871MX_NOPB; SOIC-8_3.9x4.9mm_P1.27mm
U3: LM2733YMF; SOT-23-5
VCC: SolderJumper-2_P1.3mm_Bridged2Bar_RoundedPad1.0x1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; SolderJumper-2_P1.3mm_Bridged2Bar_RoundedPad1.0x1.5mm

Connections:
/5V: C1.1, C6.1, C9.1, L1.1, R1.1, R5.1, U2.6, U3.5, VCC.2
/FIL_A: C7.2, FILAMENT.2, R12.2
/FIL_B: C8.2, FILAMENT.1, R13.2
/FIL_SHDN: R9.1, U2.1
/HV: C2.1, C3.2, D1.1, HV.2, R4.1
/~HV_SHDN~: R1.2, U3.4
GND: C1.2, C2.2, C4.2, C5.2, C6.2, C9.2, C10.2, D2.2, GND.2, HV.1, R2.1, R6.2, R9.2, U2.7, U3.2
unnamed: C3.1, R2.2, R3.2, U3.3
unnamed: C4.1, R8.1, U2.4
unnamed: C5.1, U2.2
unnamed: C7.1, R10.1
unnamed: C8.1, R11.1
unnamed: C10.1, D2.1, R12.1, R13.1
unnamed: D1.2, L1.2, U3.1
unnamed: R3.1, R4.2
unnamed: R5.2, R6.1, R7.2, U2.3
unnamed: R7.1, R8.2, R10.2, U2.5
unnamed: R11.2, U2.8

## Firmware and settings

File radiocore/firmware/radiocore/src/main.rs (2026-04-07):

#![no_std]
#![no_main]
#![deny(
    clippy::mem_forget,
    reason = "mem::forget is generally not safe to do with esp_hal types, especially those \
    holding buffers for the duration of a data transfer."
)]
#![deny(clippy::large_stack_frames)]

use embassy_executor::Spawner;
use embassy_futures::select::{self, Either};
use embassy_sync::blocking_mutex::raw::CriticalSectionRawMutex;
use embassy_sync::mutex::Mutex;
use embassy_sync::watch::Watch;
use embassy_time::{Duration, Instant, Timer};
use esp_hal::Async;
use esp_hal::clock::CpuClock;
use esp_hal::gpio::AnyPin;
use esp_hal::i2c;
use esp_hal::interrupt::software::SoftwareInterruptControl;
use esp_hal::time::Rate;
use esp_hal::timer::timg::TimerGroup;
use heapless::format;
use log::{debug, info, warn};

use esp_backtrace as _;

#[unsafe(no_mangle)]
pub extern "C" fn custom_halt() -> ! {
    const RESET: Option<&'static str> = option_env!("ESP_BACKTRACE");
    if let Some(r) = RESET
        && r == "RESET"
    {
        // reset the chip on panic
        esp_hal::system::software_reset();
    }
    // otherwise drop to infinite loop
    loop {}
}

use radiocore::display::VacuumDisplay;
use radiocore::nightlight::interpolate_brightness;
use radiocore::radio::{RDSUpdate, Si4706Radio, rds_to_julian};
use radiocore::rtc::{Ds1338, RtcControls, SqweRate};
use static_cell::StaticCell;

// Default app-descriptor required by the esp-idf bootloader
// https://docs.espressif.com/projects/esp-idf/en/stable/esp32/api-reference/system/app_image_format.html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
esp_bootloader_esp_idf::esp_app_desc!();

pub static SECONDS: Watch<CriticalSectionRawMutex, Instant, 2> = Watch::new();

pub static RDSTIME: Watch<CriticalSectionRawMutex, jiff::Zoned, 2> = Watch::new();

type I2cBus = Mutex<CriticalSectionRawMutex, i2c::master::I2c<'static, Async>>;

#[allow(
    clippy::large_stack_frames,
    reason = "it's not unusual to allocate larger buffers etc. in main"
)]
#[esp_rtos::main]
async fn main(spawner: Spawner) {
    // generator version: 1.2.0

    // use: $ ESP_LOG=Debug cargo run --release
    esp_println::logger::init_logger_from_env();

    // initialize to maximum frequency of 160 MHz
    let config = esp_hal::Config::default().with_cpu_clock(CpuClock::_160MHz);
    let peripherals = esp_hal::init(config);

    // prepare interrupt source for delay timers
    let timg0 = TimerGroup::new(peripherals.TIMG0);
    let sw_interrupt = SoftwareInterruptControl::new(peripherals.SW_INTERRUPT);
    esp_rtos::start(timg0.timer0, sw_interrupt.software_interrupt0);

    info!("Embassy initialized!");

    // initialize i2c controller
    let i2c = i2c::master::I2c::new(
        peripherals.I2C0,
        i2c::master::Config::default().with_frequency(Rate::from_khz(400)),
    )
    .unwrap()
    .with_sda(peripherals.GPIO5)
    .with_scl(peripherals.GPIO6);
    let i2c = i2c.into_async();

    // create a shared bus for multiple devices
    // https://github.com/embassy-rs/embassy/blob/main/examples/rp/src/bin/shared_bus.rs
    static I2CBUS: StaticCell<I2cBus> = StaticCell::new();
    let i2c = I2CBUS.init(Mutex::<CriticalSectionRawMutex, _>::new(i2c));

    // rtc.send(&[0, 0b0000_0000, 0b0010_0000, 0b0000_0001]).await; // set 01:20:00

    spawner.must_spawn(radio(i2c, peripherals.GPIO3.into(), &RDSTIME));
    spawner.must_spawn(ticktock(i2c, &SECONDS, &RDSTIME));
    spawner.must_spawn(seconds_ticker());
}

#[embassy_executor::task]
pub async fn radio(
    bus: &'static I2cBus,
    enable_pin: AnyPin<'static>,
    rdstime: &'static Watch<CriticalSectionRawMutex, jiff::Zoned, 2>,
) {
    let mut radio = Si4706Radio::bind(bus, Si4706Radio::ADDRESS_SEN_HIGH, enable_pin);
    let rdstime = rdstime.sender();
    radio.power_up().await;
    radio.log_revision().await;
    radio.preparations().await;
    radio.tune(10000).await;
    Timer::after_secs(1).await;
    let mut rds = [0; 14];
    let mut lastinfo = Instant::now();
    loop {
        if lastinfo.elapsed() > Duration::from_secs(60) {
            radio.receiver_status().await;
            lastinfo = Instant::now();
        }
        if let Some(instant) = radio.is_rds_ready(&mut rds).await {
            let block_a = u16::from_be_bytes([rds[4], rds[5]]);
            let block_b = u16::from_be_bytes([rds[6], rds[7]]);
            let block_c = u16::from_be_bytes([rds[8], rds[9]]);
            let block_d = u16::from_be_bytes([rds[10], rds[11]]);
            let b_group = (block_b & 0xf000) >> 12;
            let group = match b_group {
                0x00 => "STATION ",
                0x02 => "MESSAGE ",
                0x04 => "DATETIME",
                _ => &format!(8; "  [{:02x}]  ", b_group).unwrap(),
            };
            let block_a_err = (rds[12] >> 6) & 0b11;
            let block_b_err = (rds[12] >> 4) & 0b11;
            let block_c_err = (rds[12] >> 2) & 0b11;
            let block_d_err = (rds[12] >> 0) & 0b11;
            if group == "DATETIME" {
                warn!(
                    "RDS [{:04x}] typ: {}  B={:04x} C={:04x}, D={:04x} err={:?}",
                    block_a,
                    group,
                    block_b,
                    block_c,
                    block_d,
                    [block_a_err, block_b_err, block_c_err, block_d_err],
                );
                if let Some(dt) = rds_to_julian(&rds) {
                    if let Some(dt) = radio.plausible_update(RDSUpdate::new(instant, dt)) {
                        rdstime.send(dt);
                    }
                }
            } else {
                esp_println::print!(
                    "RDS [{:04x}] typ: {}  B={:04x} C={:04x}, D={:04x} err={:?}\r",
                    block_a,
                    group,
                    block_b,
                    block_c,
                    block_d,
                    [block_a_err, block_b_err, block_c_err, block_d_err],
                );
            }
        }
        Timer::after_millis(10).await;
    }
    // radio.tune_status().await;
}

#[embassy_executor::task]
pub async fn ticktock(
    bus: &'static I2cBus,
    ticker: &'static Watch<CriticalSectionRawMutex, Instant, 2>,
    rdstime: &'static Watch<CriticalSectionRawMutex, jiff::Zoned, 2>,
) {
    let mut vfd = VacuumDisplay::bind(bus, VacuumDisplay::DEFAULT_ADDRESS);
    vfd.brightness(100).await;

    let mut rtc = Ds1338::bind(bus);
    info!("RTC: {:?}", rtc.get().await);
    rtc.set_controls(RtcControls {
        oscillator_stop: false,
        output_control: true,
        sqaurewave_output: true,
        rate_select: SqweRate::_32768kHz,
    })
    .await;

    let mut tick = ticker.receiver().unwrap();
    let mut timeupdate = rdstime.receiver().unwrap();

    loop {
        match select::select(tick.changed(), timeupdate.changed()).await {
            Either::First(_) => {
                let dt = rtc.get_time().await;
                let brightness = interpolate_brightness(dt, 64, 120);
                debug!("set brightness {}", brightness);
                vfd.brightness(brightness).await;
                let mut str = format!(5; "{:02}:{:02}", dt.hour(), dt.minute())
                    .unwrap()
                    .into_bytes();
                if dt.second() % 2 == 0 {
                    str[2] = b' ';
                }
                vfd.send(&str).await;
            }
            Either::Second(upd) => {
                rtc.set_time(upd.datetime()).await;
            }
        }
    }
}

#[embassy_executor::task]
async fn seconds_ticker() {
    let mut timer = embassy_time::Ticker::every(Duration::from_hz(1));
    let watch = SECONDS.sender();
    info!("starting ticker");
    loop {
        timer.next().await;
        let now = Instant::now();
        watch.send(now);
        debug!(
            "uptime {:03}s {:06}",
            now.as_secs(),
            now.as_micros() % 1000000
        );
    }
}

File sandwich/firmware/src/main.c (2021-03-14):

// Copyright (c) 2020 Anton Semjonov
// Licensed under the MIT License

#include <stdio.h>
#include <stdlib.h>
#include <string.h>
#include <time.h>

#include <freertos/FreeRTOS.h>
#include <freertos/task.h>
#include <freertos/queue.h>
#include <freertos/event_groups.h>

#include <esp_system.h>
#include <esp_log.h>
#include <esp_types.h>
#include <esp_event.h>
#include <nvs_flash.h>
#include <esp_wifi.h>

#include <wifi_provisioning/manager.h>
#include <wifi_provisioning/scheme_ble.h>

#include <driver/gpio.h>

#include "ds1307.h"
#include "vfddriver.h"
#include "segments.h"
#include "realtimeclock.h"
#include "ambientlight.h"
#include "animations.h"
#include "wireless.h"

#define SECONDS configTICK_RATE_HZ

// turn on the usr led, yay
#define LED 5
void led_init() {
  
  gpio_set_level(LED, 1);
}

/*
  TODO LIST
  - erase nvs and reprovision on long gpio0 button press
  - manage "foreground" task in stack with push/pop
  - use the temperature sensor
*/

void do_sync(TaskHandle_t clock) {

  esp_err_t err;
  if (clock) vTaskSuspend(clock);
  TaskHandle_t loading;
  animation_spinner(&loading);

  wireless_connect();
  err = xEventGroupWaitBits(wireless, WIFI_CONNECTED, false, true, 30 * SECONDS);
  if (err == ESP_ERR_TIMEOUT) goto fail;
  err = sntp_sync(60 * SECONDS);
  if (err == ESP_ERR_TIMEOUT) goto fail;
  wireless_disconnect();
  goto out;

  fail:
  vTaskSuspend(loading);
  vfd_text("FAIL");
  vTaskDelay(2 * SECONDS);

  out:
  vTaskDelete(loading);
  if (clock) vTaskResume(clock);

}

TaskHandle_t factory_reset;

void factory_reset_task(void *arg) {

  ESP_LOGW("factory_reset", "button pressed");
  TickType_t t = xTaskGetTickCount();
  for (int i = 0; i < 5; i++) {
    ESP_LOGW("factory_reset", "in %d ...", 5 - i);
    gpio_set_level(LED, 1);
    vTaskDelayUntil(&t, 0.2 * SECONDS);
    gpio_set_level(LED, 0);
    vTaskDelayUntil(&t, 0.8 * SECONDS);
  }
  gpio_set_level(LED, 1);
  ESP_LOGW("factory_reset", "erase nvs partition & reboot");
  nvs_flash_erase();
  esp_restart();

}

static void IRAM_ATTR factory_reset_isr(void *arg) {

  int level = gpio_get_level(GPIO_NUM_0);
  if (!level) {
    // falling edge, button press
    xTaskCreate(factory_reset_task, "factory reset", 2048, NULL, ESP_TASK_PRIO_MIN + 1, &factory_reset);
  } else {
    // rising edge, release
    if (factory_reset) vTaskDelete(factory_reset);
    gpio_set_level(LED, 0);
  }

}

void factory_reset_watcher_init() {

  gpio_config_t factrst = {
    .mode = GPIO_MODE_INPUT,
    .pin_bit_mask = (1ULL << GPIO_NUM_0),
    .pull_up_en = true,
    .intr_type = GPIO_INTR_ANYEDGE,
  };
  gpio_config(&factrst);

  gpio_install_isr_service(0);
  gpio_isr_handler_add(GPIO_NUM_0, factory_reset_isr, NULL);

}

void app_main() {

  // initialize nonvolatile storage
  esp_err_t err = nvs_flash_init();
  if (err == ESP_ERR_NVS_NO_FREE_PAGES || err == ESP_ERR_NVS_NEW_VERSION_FOUND) {
    ESP_ERROR_CHECK(nvs_flash_erase());
    err = nvs_flash_init();
  }
  ESP_ERROR_CHECK(err);

  // init usr led
  gpio_set_direction(LED, GPIO_MODE_OUTPUT);
  gpio_set_level(LED, 0);
  factory_reset_watcher_init();

  // initialize vacuum flourescent display
  vfd_pin_t vfdcfg = {
    .enable    = VFD_PIN_ENABLE,
    .clock     = VFD_PIN_CLOCK,
    .data      = VFD_PIN_DATA,
    .strobe    = VFD_PIN_STROBE,
    .blank     = VFD_PIN_BLANK,
    .fil_shdn  = VFD_PIN_FILSHDN,
    .hv_shdn   = VFD_PIN_HVSHDN,
  };
  vfd_init_spi(&vfdcfg);
  TaskHandle_t digitmux;
  vfd_init_mux(0.002, &digitmux);

  // initialize filament dimmer via photodiode
  TaskHandle_t ambientlight;
  ambientlight_init(PHOTODIODE, vfdcfg.fil_shdn, &ambientlight);

  // connect to battery-backed rtc
  realtimeclock_init(I2C_SDA, I2C_SCL);
  time_t lastsync = realtimeclock_read_from_rtc();

  // set timezone to Europe/Berlin
  // https://github.com/nayarsystems/posix_tz_db/blob/master/zones.csv
  setenv("TZ", "CET-1CEST,M3.5.0,M10.5.0/3", 1);
  tzset();

  // enable and possibly provision credentials the first time
  // nvs_flash_erase(); // always clear creds to force conf
  wireless_init();
  wireless_provision();

  // maybe sync once on startup
  time_t now;
  time(&now);
  if ((lastsync == 0) || (lastsync > now) || ((now - lastsync) > (60 * 60))) {
    ESP_LOGI("main", "last sync more than an hour ago");
    do_sync(NULL);
  }

  // display the current time
  TaskHandle_t clock;
  clockface(&clock);
  
  // all segments for debug purposes
  // vfd_text("88:88");
  // for (;;) { vTaskDelay(2 * SECONDS); }

  for (;;) {
    sntp_sync_schedule(NULL);
    do_sync(clock);
  }

  wireless_end();
  
}

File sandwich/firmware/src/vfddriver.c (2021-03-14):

// Copyright (c) 2020 Anton Semjonov
// Licensed under the MIT License

#include <stdio.h>
#include <stdlib.h>
#include <string.h>

#include <freertos/FreeRTOS.h>
#include <freertos/semphr.h>
#include <freertos/task.h>
#include <esp_log.h>
#include <driver/spi_master.h>
#include <driver/gpio.h>
#include <driver/timer.h>

#include "vfddriver.h"
#include "segments.h"

// ------------------------ hv5812 spi driver ------------------------

#define TAG "chronovfd"

static vfd_handle_t vfd;

// set strobe low before spi transaction
void IRAM_ATTR vfd_strobe_low(spi_transaction_t *t) {
  gpio_set_level(vfd.pin.strobe, 0);
}

// set strobe high after spi transaction to latch contents
void IRAM_ATTR vfd_strobe_high(spi_transaction_t *t) {
  gpio_set_level(vfd.pin.strobe, 1);
}

// transmit data to a hv5812 vfd driver
void IRAM_ATTR vfd_transmit(uint16_t data) {
  spi_transaction_t t;
  memset(&t, 0, sizeof(t));

  // prepare data to be sent, 20 bits fully define all output pins
  uint32_t buf = SPI_SWAP_DATA_TX(data & (GRIDMASK|SEGMENTMASK), 20);
  t.tx_buffer = &buf;
  t.length = 20;

  // transmit and wait for transaction to finish
  ESP_ERROR_CHECK(spi_device_polling_transmit(vfd.spidev, &t));
}

// shorthand to prepare gpio outputs
#define gpio_init_output(pin, level) \
  ESP_ERROR_CHECK(gpio_set_direction(pin, GPIO_MODE_OUTPUT)); \
  ESP_ERROR_CHECK(gpio_set_level(pin, level))

// initialize spi interface to hv5812 display driver with auxiliary pins
void vfd_init_spi(vfd_pin_t *pin) {
  vfd.pin = *pin;

  // configure the spi bus
  spi_bus_config_t buscfg = {
    .sclk_io_num   = vfd.pin.clock,
    .mosi_io_num   = vfd.pin.data,
    .miso_io_num   = -1,
    .quadhd_io_num = -1,
    .quadwp_io_num = -1,
  };
  ESP_ERROR_CHECK(spi_bus_initialize(VFD_SPI_HOST, &buscfg, 0));
  ESP_LOGI(TAG, "hspi bus configured with { clock: %d, data: %d }",
    vfd.pin.clock, vfd.pin.data);
  
  // add the device on the bus
  spi_device_interface_config_t devcfg = {
    // HV5812 maximum rated frequency @ 125°C, 5V is 5 MHz
    // we're overclocking here, but it works for me™
    .clock_speed_hz = 20*1000*1000,
    .mode = 0,
    .pre_cb  = vfd_strobe_low,
    .post_cb = vfd_strobe_high,
    .command_bits = 0,
    .address_bits = 0,
    .dummy_bits = 0,
    .duty_cycle_pos = 128,
    .spics_io_num = -1,
    .queue_size = 4,
  };
  ESP_ERROR_CHECK(spi_bus_add_device(VFD_SPI_HOST, &devcfg, &vfd.spidev));
  ESP_LOGI(TAG, "device added to bus with { strobe: %d }", vfd.pin.strobe);

  // configure auxiliary gpios for display driver
  gpio_init_output( vfd.pin.strobe,   0 ); // don't latch immediately
  gpio_init_output( vfd.pin.blank,    0 ); // don't blank outputs
  gpio_init_output( vfd.pin.fil_shdn, 0 ); // filament supply on
  gpio_init_output( vfd.pin.hv_shdn,  1 ); // high-voltage supply on
  gpio_init_output( vfd.pin.enable,   0 ); // enable level shifter

  // set all hv pins to off once
  vfd_transmit(0);

}

// write text into the buffer from which digit multiplexing is performed.
// text must point to a char array with $GRIDS elements
void vfd_text(const char text[GRIDS]) {
  bool end = false;
  for (int i = 0; i < GRIDS; i++) {
    if (text[i] == 0) end = true;
    if (end)
      vfd.buf[i] = 0;
    else
      vfd.buf[i] = segment_lookup(text[i]);
  };
}

// copy a raw display buffer, when segment mapping has already been performed
void vfd_raw(uint16_t raw[GRIDS]) {
  memcpy(vfd.buf, raw, sizeof(uint16_t) * GRIDS);
}


// ------------------------ digitmux timer ------------------------

static IRAM_ATTR TaskHandle_t digitmux;

// periodically called function which does time-multiplexing of the
// individual digits on the display from contents of vfd->buf
void IRAM_ATTR vfd_digitmux_task(void *arg) {
  static int pos;
  uint16_t data;

  // acquire bus exclusively to speed up transactions
  ESP_ERROR_CHECK(spi_device_acquire_bus(vfd.spidev, portMAX_DELAY));

  // store own task handle for isr
  digitmux = xTaskGetCurrentTaskHandle();

  for (;;) {
    // unblocked from isr periodically
    ulTaskNotifyTake(pdTRUE, portMAX_DELAY);
    data = (vfd.buf[gridpos[pos]] & SEGMENTMASK) | grids[gridpos[pos]];
    vfd_transmit(data);
    pos = (pos + 1) % (sizeof(gridpos)/sizeof(gridpos[0]));
  }

}

// interrupt service routine that periodically unblocks vfd_digitmux_task
void IRAM_ATTR vfd_digitmux_isr(void *arg) {
  // rearm timer
#if VFD_MUX_TIMER_IDX == 0
  VFD_MUX_TIMERG_DEV.int_clr_timers.t0 = 1;
#else
  VFD_MUX_TIMERG_DEV.int_clr_timers.t1 = 1;
#endif
  VFD_MUX_TIMERG_DEV.hw_timer[VFD_MUX_TIMER_IDX].config.alarm_en = TIMER_ALARM_EN;
  // unblock and wake task
  if (digitmux) {
    BaseType_t HigherPriorityTaskWoken = pdTRUE;
    vTaskNotifyGiveFromISR(digitmux, &HigherPriorityTaskWoken);
    portYIELD_FROM_ISR();
  }
}


// vfd_mux_init configures a hardware timer and registers an isr for
// digit multiplexing in the background. use period=0.002 for 
// approximately 60 Hz overall refresh rate.
void vfd_init_mux(double period, TaskHandle_t *task) {

  // initialise multiplexing timer
  timer_config_t timercfg = {
    .divider = VFD_MUX_DIVIDER,
    .counter_en = false,
    .counter_dir = TIMER_COUNT_UP,
    .auto_reload = TIMER_AUTORELOAD_EN,
    .alarm_en = true,
    .intr_type = TIMER_INTR_LEVEL,
  };
  ESP_ERROR_CHECK(timer_init(VFD_TIMER, &timercfg));
  
  // reset counter and set alarm value for given period
  ESP_ERROR_CHECK(timer_set_counter_value(VFD_TIMER, 0));
  ESP_ERROR_CHECK(timer_set_alarm_value(VFD_TIMER, period * VFD_MUX_SECOND));
  ESP_LOGI(TAG, "digitmux timer prepared");

  // register isr and start timer
  ESP_ERROR_CHECK(timer_enable_intr(VFD_TIMER));
  ESP_ERROR_CHECK(timer_isr_register(VFD_TIMER, vfd_digitmux_isr, NULL, 0, NULL));
  ESP_ERROR_CHECK(timer_start(VFD_TIMER));

  // explicitly zero the display buffer
  bzero(vfd.buf, sizeof(vfd.buf));

  // create mux task and return its handle
  xTaskCreate(vfd_digitmux_task, "digitmux", 2048, NULL, configMAX_PRIORITIES - 1, task);
  // default event loop is pinned on core 0, so if you see flickering maybe pin to core 1 ..
  // xTaskCreatePinnedToCore(vfd_digitmux_task, "digitmux", 2048, NULL, configMAX_PRIORITIES - 1, task, 1);
  ESP_LOGI(TAG, "digitmux isr registered & task created");

}

void vfd_set_mux_period(double period) {
  ESP_ERROR_CHECK(timer_pause(VFD_TIMER));
  ESP_ERROR_CHECK(timer_set_alarm_value(VFD_TIMER, period * VFD_MUX_SECOND));
  uint64_t cnt;
  ESP_ERROR_CHECK(timer_get_counter_value(VFD_TIMER, &cnt));
  if (!(cnt < (period * VFD_MUX_SECOND))) {
    ESP_ERROR_CHECK(timer_set_counter_value(VFD_TIMER, (period * VFD_MUX_SECOND) - 1));
  }
  ESP_ERROR_CHECK(timer_start(VFD_TIMER));
  ESP_LOGV(TAG, "digitmux period changed to %0.3fs", period);
}

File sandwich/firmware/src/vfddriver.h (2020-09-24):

// Copyright (c) 2020 Anton Semjonov
// Licensed under the MIT License

#pragma once

#include <freertos/FreeRTOS.h>
#include <freertos/task.h>
#include <driver/spi_master.h>
#include <driver/gpio.h>
#include <driver/timer.h>
#include "segments.h"

// ------------------------ hv5812 spi driver ------------------------

// default interface to the hv5812 on chronovfd
#define VFD_SPI_HOST    HSPI_HOST
#define VFD_PIN_ENABLE  GPIO_NUM_19
#define VFD_PIN_CLOCK   GPIO_NUM_25
#define VFD_PIN_DATA    GPIO_NUM_26
#define VFD_PIN_STROBE  GPIO_NUM_27
#define VFD_PIN_BLANK   GPIO_NUM_18
#define VFD_PIN_FILSHDN GPIO_NUM_17
#define VFD_PIN_HVSHDN  GPIO_NUM_16

// vfd_pin_t holds relevant gpio numbers
// connected to the hv5812 display driver
typedef struct vfd_pin_t {
  gpio_num_t enable;
  gpio_num_t clock;
  gpio_num_t data;
  gpio_num_t strobe;
  gpio_num_t blank;
  gpio_num_t fil_shdn;
  gpio_num_t hv_shdn;
} vfd_pin_t;

// vfd_handle_t holds a handle to the instantiated
// spi device and the relevant gpio pins
typedef struct vfd_handle_t {
  vfd_pin_t pin;
  spi_device_handle_t spidev;
  uint16_t buf[5]; // display contents
} vfd_handle_t;

void vfd_init_spi(vfd_pin_t *pin);
void vfd_transmit(uint16_t data);
void vfd_text(const char text[GRIDS]);
void vfd_raw(uint16_t raw[GRIDS]);

// ------------------------ digitmux timer ------------------------

#define VFD_MUX_DIVIDER       80
#define VFD_MUX_SECOND        (TIMER_BASE_CLK / VFD_MUX_DIVIDER)
#define VFD_MUX_TIMERG_DEV    TIMERG0
#define VFD_MUX_TIMER_GROUP   0
#define VFD_MUX_TIMER_IDX     0
#define VFD_TIMER             VFD_MUX_TIMER_GROUP, VFD_MUX_TIMER_IDX

void vfd_init_mux(double period, TaskHandle_t *task);
void vfd_set_mux_period(double period);

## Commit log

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2020-03-02 attempt to detect connected i2c master through scl level
2020-03-05 attempt to use background refresh with timer interrupts and manual rtc communication
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2020-04-01 reduce brightness correction that was due to floaty blanking pin
    [hvshift.cpp]
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2020-04-01 fix a bug in i2c clock script: hexdump squeezing
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2020-07-23 begin tracking my kicad feng-shui
    pretty nice power supply submodule layouts so far ..
    [universal_vfd_psu.sch, vfdchrono.kicad_pcb, vfdchrono.sch]
2020-07-23 further psu layout optimizations
    [universal_vfd_psu.sch, vfdchrono.kicad_pcb]
2020-07-24 commit the board version that went to aisler, more silkscreen info
    [universal_vfd_psu.sch, vfdchrono.kicad_pcb, vfdchrono.sch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]
2020-07-24 rename kicad project files for driver board
    [vfddriver.kicad_pcb, vfddriver.sch, vfddriver_psu_modules.kicad_pcb]
2020-07-24 create a breadboard psu layout from universal psu modules
    [universal_vfd_psu.kicad_pcb, vfddriver.kicad_pcb, vfddriver_psu_modules.kicad_pcb]
2020-07-26 begin tracking work on clock shield with esp32
    [clockcore.kicad_pcb, clockcore.sch]
2020-07-28 finished schematic for clockcore, pcb layout todo
    [clockcore.kicad_pcb, clockcore.sch]
2020-07-29 finished pcb routing for clockcore, forgot to add zener
    [clockcore.kicad_pcb, clockcore.sch]
2020-07-30 final clockcore design v2_copy ... i think
    [clockcore.kicad_pcb, clockcore.sch]
2020-07-31 update vfddriver resistor values, 10 ohm is too dark, 4.7 too bright
    [filament_voltage.ods, universal_vfd_psu.sch, vfddriver.sch]
2020-07-31 add research notes about vfds in general
    [filament_voltage.ods, hv_lm2733.ods, vfddriver.kicad_pcb]
2020-07-31 add universal vfd psu design files by rolo kamp
    [bom.xlsx]
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2020-08-02 add ds18b20 to clock core and reroute a few traces
    [clockcore.kicad_pcb, clockcore.sch]
2020-08-02 updated crystal in schematic so pin3 is gnd, added teardrops
    [clockcore.kicad_pcb, clockcore.sch]
2020-08-07 add digikey bom for clockcore
    [clockcore.sch, clockcore_digikey_bom.csv]
2020-08-07 populate part numbers in clockcore symbol fields, generate new bom with kibom
    [clockcore.sch, clockcore_bom.csv, clockcore_digikey_bom.csv]
2020-08-09 brightness correction for hendriks vfd
    [hvshift.cpp]
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2020-08-15 add clockcore schematic pdf
    [clockcore.sch]
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2020-08-17 refactor to use handle on heap, experiment with filament dimming
    [filament_voltage.ods]
2020-08-19 hardware: add usb-c receptacle 3d model
    copied from esden/Glasgow @ dcf681eff68b47ce297b1218d60e69f61a113a32
    [USB_C_Receptacle_HRO_TYPE-C-31-M-12.step, clockcore.kicad_pcb]
2020-08-19 hardware: add switches 3d model and configure D1 F1 with similar 1206 models
    [PTS526SPG15SMTR2LFS.stp, clockcore.kicad_pcb]
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2020-08-20 hardware: add page setting for rev 1.0 before photodiode changes
    [clockcore.kicad_pcb]
2020-08-20 hardware: tidy up, fix photodiode, (re)export (i)boms and schematics
    [clockcore.kicad_pcb, clockcore.sch, clockcore_bom.csv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]
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2020-08-24 hardware: add erratum on how to fix the photodiode on rev1.0 boards
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2020-08-26 firmware: add and fix ds1307.c rtc config checks, use rtc as external clock source
    [ds1307.c, main.c]
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2020-09-05 fw: hacked together blocking behaviour on missing provisioning on boot
    [main.c]
2020-09-07 fw: replace a few taskdelays with taskdelayuntil where periodic is needed
    [ambientlight.c, realtimeclock.c]
2020-09-07 fw: tidy up wirelss functions, use event group for connection status bits
2020-09-07 fw: implement simple factory reset on gpio0
    [main.c]
2020-09-24 fw: update and fix espidf @ 4.1, add textrunner animation
    [vfddriver.c, vfddriver.h]
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2021-03-14 fw: add code to check if my display has burn-in
    [main.c, vfddriver.c]
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2021-08-27 hw: [WIP] add attiny412, remove traces in prep for v2
    [universal_vfd_psu.sch, vfddriver.kicad_pcb, vfddriver.sch]
2021-08-28 hw: tweak universal psu to test new filament driver
    [breadboard_psu_hbridge.kicad_pcb, breadboard_psu_hbridge.kicad_sch, breadboard_psu_hbridge.sch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]
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2021-08-28 hw: finished h-bridge psu test board
    [breadboard_psu_hbridge.kicad_pcb, breadboard_psu_hbridge.kicad_sch]
2021-08-28 hw: tweak breadboard psu for fabrication
    [breadboard_psu_hbridge.kicad_pcb]
2021-12-20 fw: fix build, pin new toolchain versions
2022-01-14 hw: update h-bridge psu with experiences as text on schematic
    [breadboard_psu_hbridge.kicad_sch]
2022-01-14 hw: update breadboard hbridge psu to kicad 6
    [breadboard_psu_hbridge.kicad_pcb, breadboard_psu_hbridge.kicad_sch, breadboard_psu_hbridge.sch]
2022-01-14 hw: [WIP] migrate libraries, put everything in subdirectories
    [breadboard_psu.kicad_pcb, breadboard_psu.kicad_sch, breadboard_psu_hbridge.kicad_pcb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]
2022-01-14 hw: [WIP] begin rework vfddriver with hbridge filament
    [universal_vfd_psu.kicad_sch, vfddriver.kicad_pcb, vfddriver.kicad_sch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]
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2022-01-16 hw: finished redesign of vfddriver frontplate
    [vfddriver.kicad_pcb, vfddriver.kicad_sch]
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2022-02-10 fw: implement digit multiplexing with RTC PIT, demo with random noise
    [main.c]
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2022-09-01 hw: begin new lcd clock face, not routed yet
    [lcddriver.kicad_pcb, lcddriver.kicad_sch]
2022-09-02 hw: finished routing lcd clock face
    [lcddriver.kicad_pcb, lcddriver.kicad_sch]
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2024-05-23 add eval board for Si4706 based RDS receiver
    [radio.kicad_pcb, radio.kicad_sch, radio.sch]
2024-10-19 lcddriver: add inverted variant of the firmware
    [lcdclock_inverted.ino]
2024-10-19 chronocase: 3d-printable cases
    [chronocase.step, chronocase_frontmount_deep.step, chronocase_frontmount_lcdclosed.step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]
2026-01-12 move case designs to /enclosure
    [chronocase.step, chronocase_frontmount_deep.step, chronocase_frontmount_lcdclosed.step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]
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2026-01-13 radio: small pcb update, add example firmware to get RDS signal
    [radio.kicad_pcb]
2026-01-25 reorganization; resurface original vfddriver v1 design and put in sandwich/; new rust firmware
    [PTS526SPG15SMTR2LFS.stp, SM04B-SRSS-TB(LF)(SN)--3DModel-STEP-56544.stp, USB_C_Receptacle_HRO_TYPE-C-31-M-12.step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]
2026-01-31 vfddriver: new renders, add 3d model for vfd tube
    The 3D model was made by Patrick Kübler, copied from https://github.com/Pakue95/VFD_Watch/
    [VFD_Display v1.step, vfddriver.csv, vfddriver.kicad_pcb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]
2026-01-31 replace firmware with rust and finish readme
    [anodes.rs, code_cabletrash_countdown.py, code_helovrld.py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]
2026-02-03 radiocore: redesign the Si4706 experiment to a new clock controller with ESP32-C3 and RTC
    [UJ20-C-V-C-2-SMT-TR.step, radio.kicad_pcb, radio.kicad_sch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]
2026-02-15 vfddriver: change i2c addr to 0x42
    the DS1338Z RTC also uses 0x68, so there'd be a collision by default
    [code_cabletrash_countdown.py, code_helovrld.py, code_ntpclock.py]
2026-02-15 radiocore: add ibom for assembly, found pcb errata and test firmware
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2026-03-22 radiocore: initial rust firmware with embassy + esp_hal
    essential parts are wired up; time updates for display come directly from RDS for now but with good FM signal this is already a viable clock
2026-03-29 radiocore: reset the chip on panics
    if ESP_BACKTRACE=RESET during compile
    [lib.rs, main.rs]
2026-04-02 radiocore: check rds updates for plausibility using drift and majority vote
    [main.rs, radio.rs]
2026-04-06 radiocore: add bounds check in rds_to_julian to avoid subtraction underflow
    [main.rs, radio.rs]
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
